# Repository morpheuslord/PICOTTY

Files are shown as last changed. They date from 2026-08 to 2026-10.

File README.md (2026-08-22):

<p align="center">
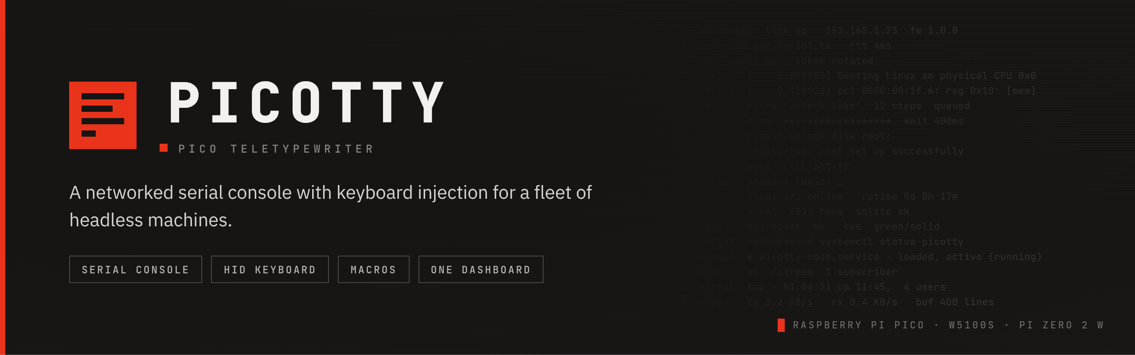
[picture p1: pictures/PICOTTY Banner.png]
PICOTTY — Pico TeleTYpewriter: a networked serial console with keyboard injection for a fleet of headless machines
  
</p>

# PICOTTY

*Pico TeleTYpewriter — an archaic telex reborn as a networked serial console.*

PICOTTY is a star-topology **serial console** for a fleet of Raspberry Pi Pico
nodes. Each node plugs into the USB port of a headless machine and becomes a
**networked serial console with keyboard injection** — it reads the target's
serial console back over the network and types keystrokes into the machine. One
hub (a Raspberry Pi Zero 2 W) coordinates the whole swarm and gives you a single
browser dashboard to watch every node and drive it, over your management network.

> **This is a serial console, not a KVM.** There is no video capture. Each node is
> a serial console with a USB keyboard attached: it reads what the target emits on
> its serial line and types back into it. Reading output therefore depends on the
> target actually having a serial console configured.

## Why this exists

I built PICOTTY for my own homelab, which runs on a rack of **mini PCs**. Unlike
a server, those boxes expose **no accessible serial port** — no BMC/IPMI, no
DB9/RJ45 console, often not even a usable header — so there's no out-of-band way
to see a stuck boot, poke a frozen box, catch a kernel panic, or drive the BIOS
without walking over and plugging in a keyboard and monitor. PICOTTY gives every
one of those headless machines exactly that, **over the network**: a tiny Pico on
its USB port acts as a USB keyboard (so you can type at BIOS, GRUB, and the OS)
and reads back a serial console, all surfaced in one browser dashboard. It's the
lights-out management a fleet of consumer mini PCs never shipped with.

---

## The dashboard

One page drives the whole swarm. **Click any screenshot to open it at full resolution.**

<p align="center">
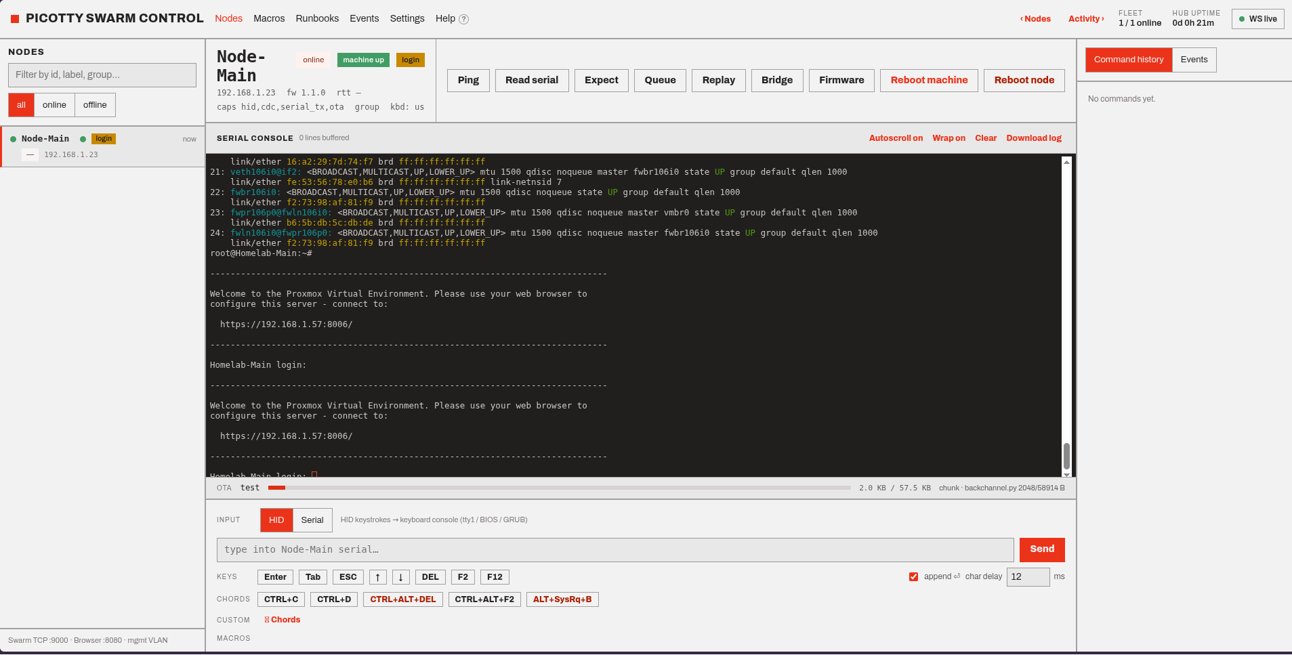
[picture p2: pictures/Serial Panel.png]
Serial console
  <br>
  <sub><b>Serial console</b> — live target output (ANSI-cleaned) with the HID ⇄ Serial input toggle</sub>
</p>

<table>
  <tr>
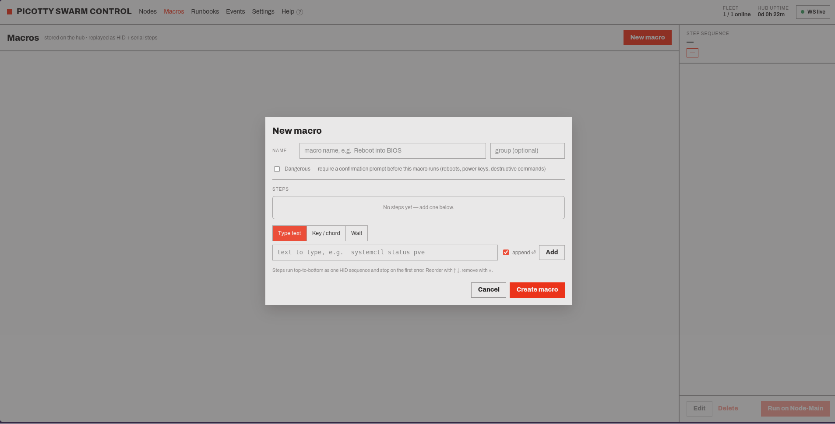
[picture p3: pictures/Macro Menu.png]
Macro editor
    <td width="50%" align="center"><br><sub><b>Macro editor</b> — reusable HID sequences from type / keys / wait steps</sub></td>
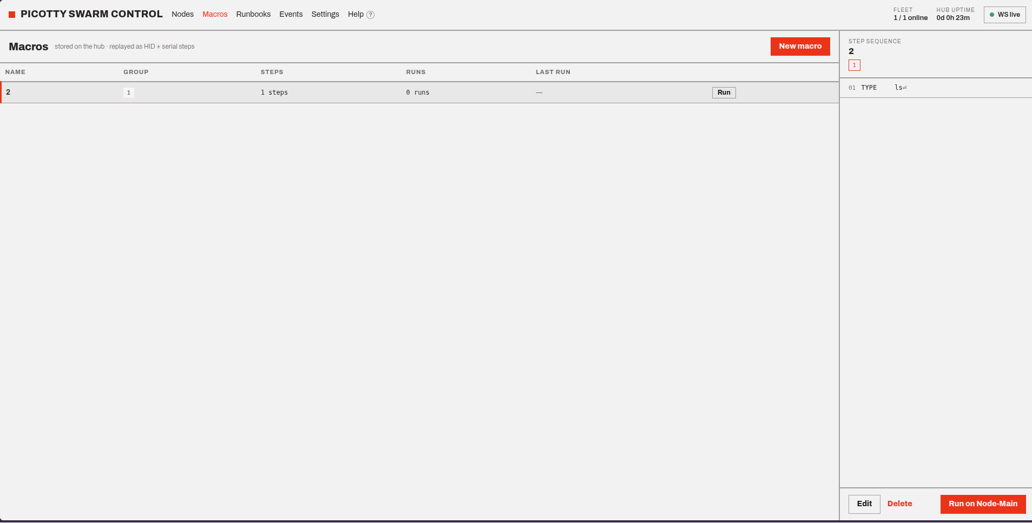
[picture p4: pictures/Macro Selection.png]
Macro library
    <td width="50%" align="center"><br><sub><b>Macro library</b> — saved sequences, replayable on any node</sub></td>
  </tr>
  <tr>
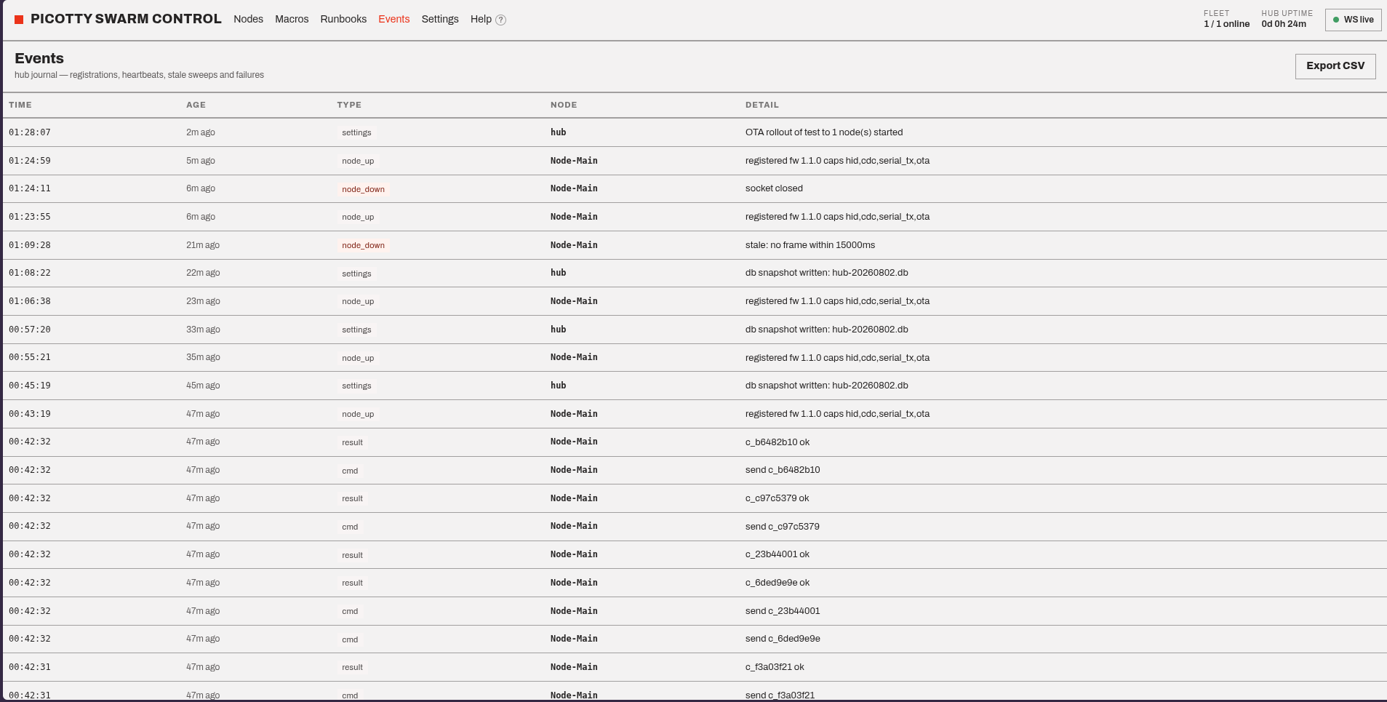
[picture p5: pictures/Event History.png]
Event history
    <td width="50%" align="center"><br><sub><b>Event history</b> — every connect, command, and fault, timestamped</sub></td>
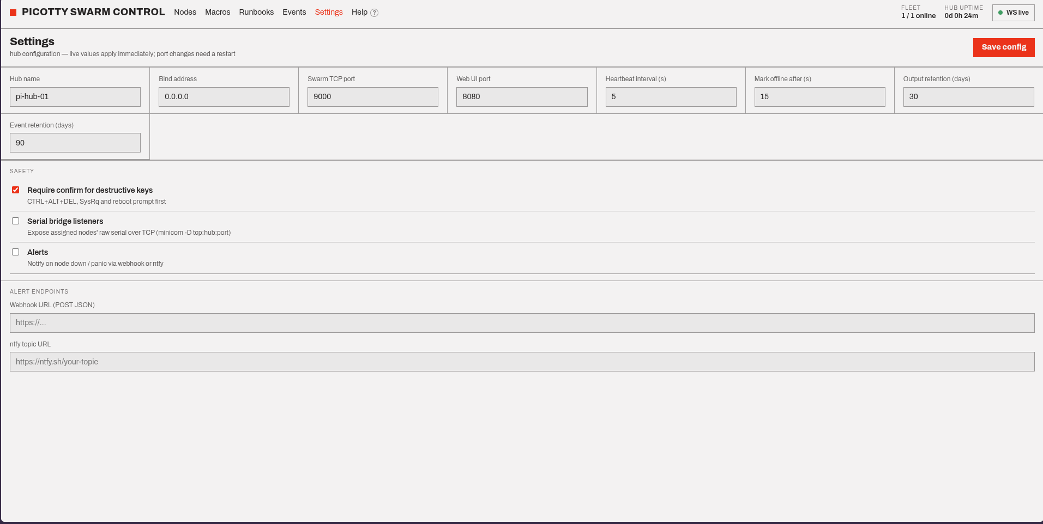
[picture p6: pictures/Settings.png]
Settings
    <td width="50%" align="center"><br><sub><b>Settings</b> — heartbeat, retention, token rotation, confirm-dangerous</sub></td>
  </tr>
  <tr>
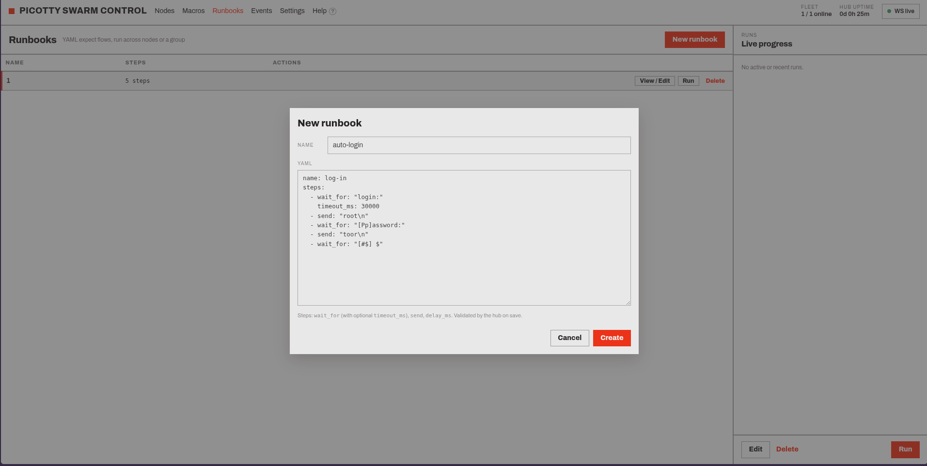
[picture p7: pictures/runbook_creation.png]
Runbook creation
    <td width="50%" align="center"><br><sub><b>Runbook creation</b> — author a YAML expect flow, validated on save</sub></td>
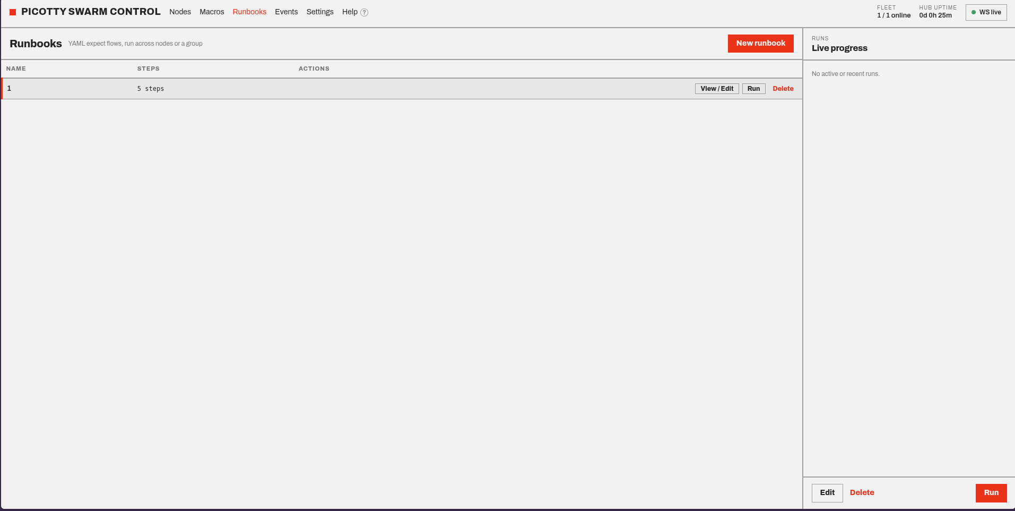
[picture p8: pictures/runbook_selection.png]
Runbook library
    <td width="50%" align="center"><br><sub><b>Runbook library</b> — pick a saved runbook, run it across a group</sub></td>
  </tr>
  <tr>
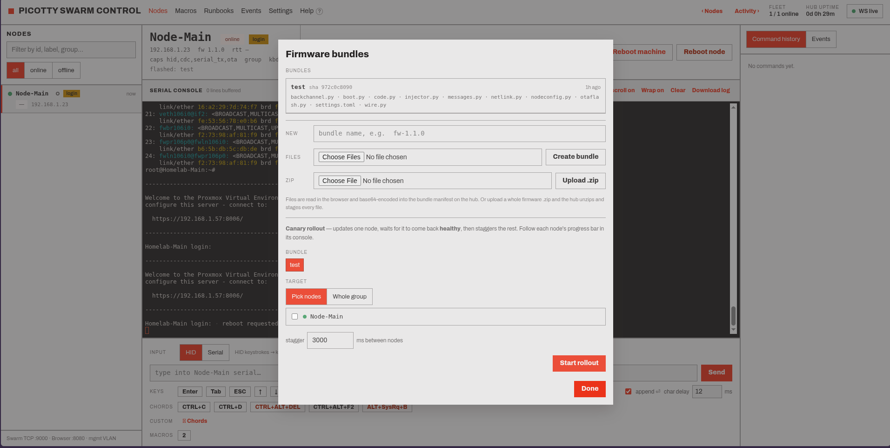
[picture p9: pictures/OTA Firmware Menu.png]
OTA firmware menu
    <td width="50%" align="center"><br><sub><b>OTA firmware menu</b> — push a bundle to a node, live byte-progress and health check</sub></td>
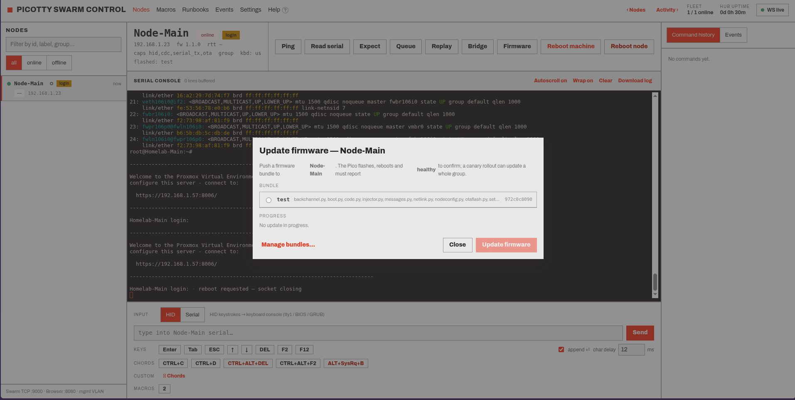
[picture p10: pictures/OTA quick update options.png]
OTA quick update options
    <td width="50%" align="center"><br><sub><b>OTA quick update options</b> — manage bundles, .zip upload, canary rollout</sub></td>
  </tr>
</table>

<p align="center">
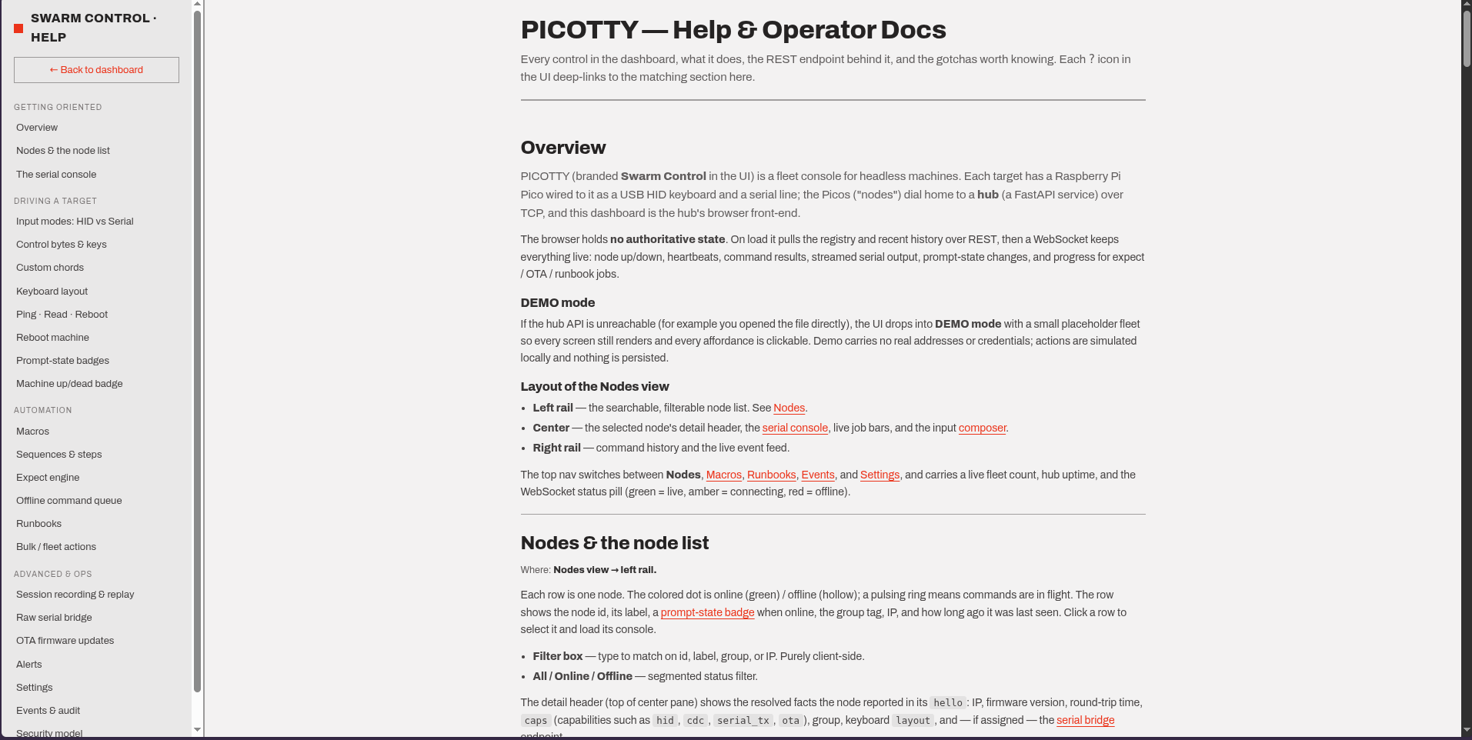
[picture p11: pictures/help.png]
In-app help
  <br>
  <sub><b>In-app help</b> — every control, its REST endpoint, and the gotchas, built into the hub</sub>
</p>

---

## What you get

- **Networked serial consoles** — read each target's serial console live and type
  into its serial login (`send`), all from the browser over the network.
- **Keyboard injection** — each node is also a USB HID keyboard, so it drives the
  target everywhere a keyboard works: BIOS, GRUB, initramfs, the OS.
- **One dashboard** — live status, per-node console, keys/chords, macros, bulk
  commands, and an event log, over HTTP + WebSocket.
- **Durable history** — every node, command, result, and output chunk is recorded
  in SQLite on the hub.
- **Headless-friendly** — LED status codes, opt-in `/error.txt`, and a REPL debug
  path make a node with no monitor diagnosable.

**What's new:** interactive serial write with a real terminal renderer, per-node
prompt-state badges, a **machine up/dead liveness badge** (is the *target* alive,
not just the node), a wait-for-output **expect engine** and YAML **runbooks**
(author, view, and edit in the browser), a **Reboot-machine menu** with three
methods (serial `reboot`, Ctrl+Alt+Del, Magic SysRq `Alt+SysRq+B`), **custom
quick chords** you save and replay, an offline command queue, **asciicast**
session replay, a raw **serial bridge** for `minicom`/PuTTY, webhook/**ntfy**
alerting, per-node keyboard layouts, and **OTA firmware updates** (chunked,
checksummed, **.zip-upload** bundles, canary rollout with watchdog-revert). Nodes now support **dual-hub failover** — a
primary + backup hub per node, with runtime steering (move / set-home / pin) and a
shared node token. The hub
now ships as the **`picotty`** uv package (`uv tool install picotty`, with a
`picotty.client` SDK), and an optional **Telegram bot sidecar** puts stats, alerts,
and a break-glass terminal on your phone — now with **fleet commands** (`/bulk`,
`/runmacro`, `/runbook`), read-only lookups (`/events`, `/log`, `/search`, `/ping`),
and dual-hub steering (`/hubs`, `/hub`). Depth in
**[docs/automation.md](docs/automation.md)**, **[docs/operations.md](docs/operations.md)**,
**[docs/ota.md](docs/ota.md)**, **[docs/packaging.md](docs/packaging.md)**,
**[docs/dual-hub.md](docs/dual-hub.md)**, and
**[docs/telegram.md](docs/telegram.md)**.

---

## Hardware

Per target machine: a **Raspberry Pi Pico** (or **Pico 2**) + a **WIZnet W5100S
Ethernet HAT** + a data-capable USB cable + an Ethernet drop. One shared **Pi Zero
2 W** runs the hub. (The all-in-one **W5100S-EVB-Pico** replaces the Pico + HAT.)

<table>
  <tr>
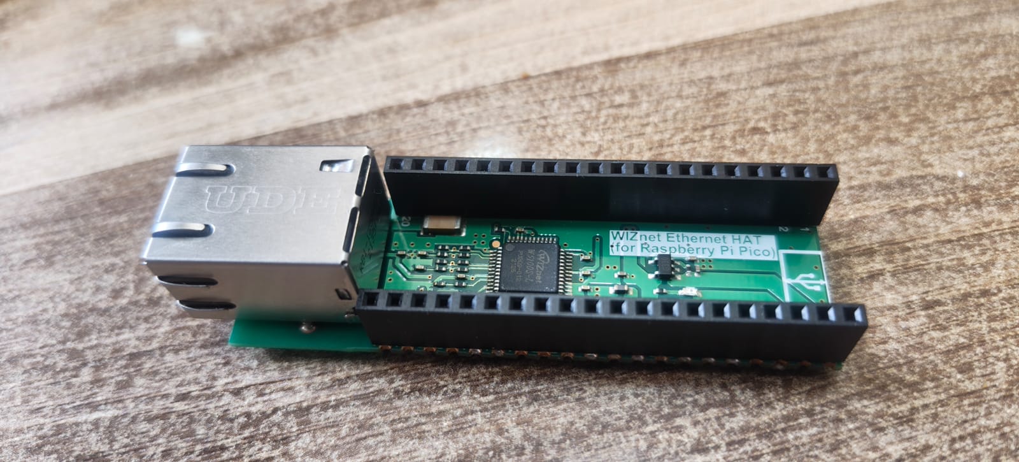
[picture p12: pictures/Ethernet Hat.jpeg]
WIZnet W5100S Ethernet HAT
    <td width="50%" align="center"><br><sub><b>WIZnet W5100S Ethernet HAT</b> — wired Ethernet over SPI</sub></td>
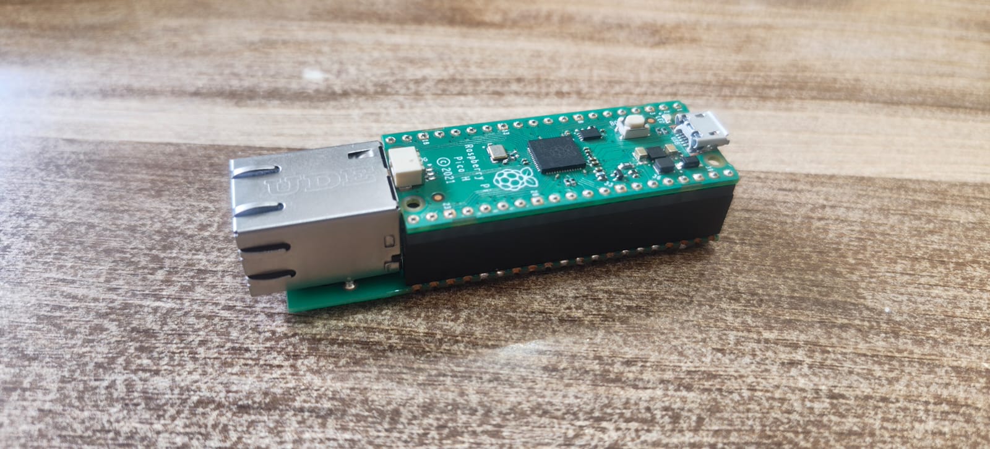
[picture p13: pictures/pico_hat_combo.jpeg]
Pico stacked with the Ethernet HAT
    <td width="50%" align="center"><br><sub><b>Pico + HAT</b> — SPI Ethernet, USB left free for the target</sub></td>
  </tr>
</table>

<p align="center">
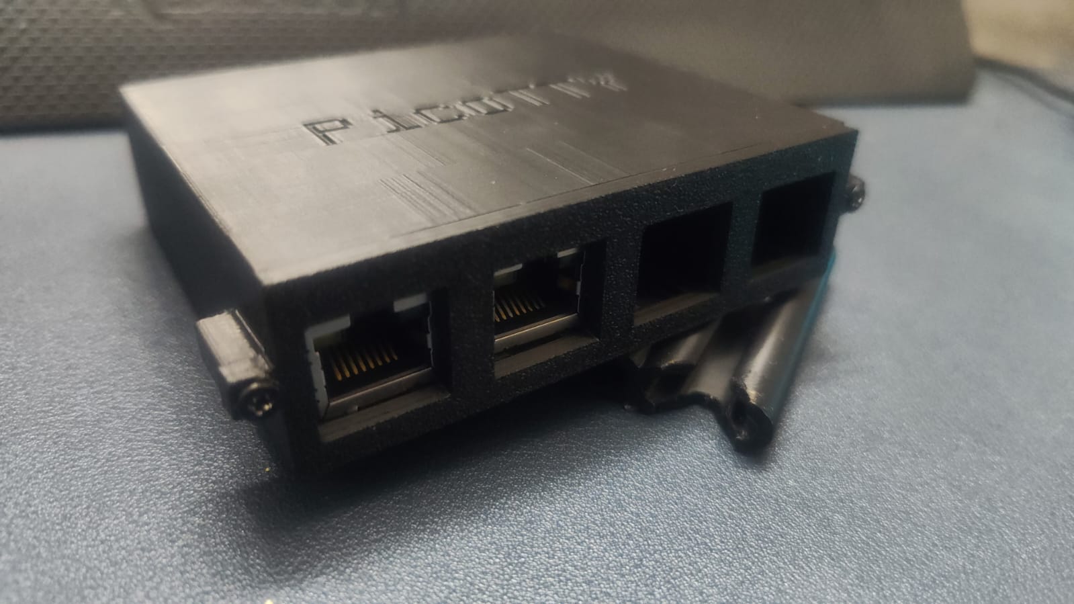
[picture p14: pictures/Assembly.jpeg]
A node assembled in its 3D-printed enclosure
  <br>
  <sub><b>A node assembled in its 3D-printed enclosure</b></sub>
</p>

### 3D-printable enclosure

<p align="center">
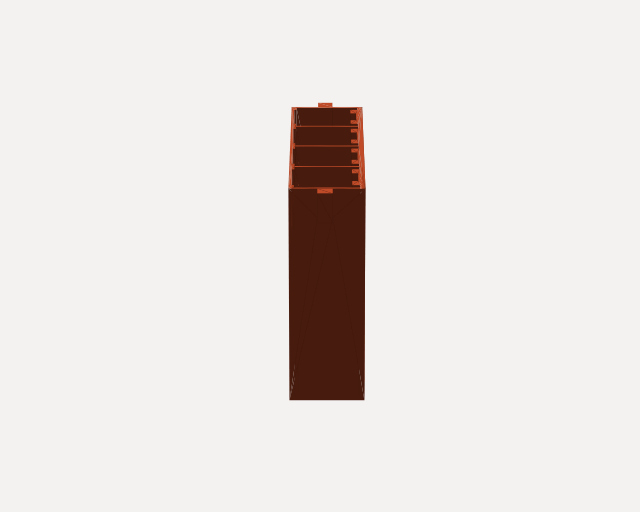
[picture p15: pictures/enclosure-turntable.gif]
PICOTTY node enclosure — rotating STL preview
  <br>
  <sub>▶ <b><a href="https://3dviewer.net/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">Open the interactive 3D viewer</a></b> &nbsp;·&nbsp; or click <a href="Enclosure%20Cad/Enclosure%20Body.stl">the STL in the repo</a> for GitHub's built-in 3D viewer</sub>
</p>

Files in [`Enclosure Cad/`](Enclosure%20Cad):
[**STL**](Enclosure%20Cad/Enclosure%20Body.stl) (slice & print) ·
[STEP](Enclosure%20Cad/PICOTTY-ENCLOSURE.step) (neutral CAD) ·
[Fusion 360 (.f3d)](Enclosure%20Cad/PICOTTY-ENCLOSURE.f3d) (editable source)

→ Full bill of materials and topology: **[docs/hardware.md](docs/hardware.md)**

---

## Quick start

The hub ships as the **`picotty`** package (uv). Install it as a tool, or run
from source:

```bash
# 1. Hub — on the Pi Zero 2 W
uv tool install picotty        # picotty-hub + picotty-sim on PATH  (or: from source ↓)
picotty-hub                    # → dashboard at http://<hub-ip>:8080
#    from a repo checkout instead:
bash hub/scripts/install.sh    # uv sync --extra hub  (+ fetches the terminal libs)
bash hub/scripts/install-service.sh          # or: bash hub/scripts/run.sh  (foreground)

# 2. Node — on your flashing machine (<id> = a node id under private/nodes/)
bash firmware/scripts/install-deps.sh
bash firmware/scripts/build.sh --node <id> --drive /run/media/$USER/CIRCUITPY
#    …or stage an artifact to drag on later:
bash firmware/scripts/build.sh --node <id> --stage        # -> firmware/build/<id>/ + .zip

# 3. Target — on each managed machine (emits its serial console to the node)
sudo bash target-setup/proxmox-serial.sh
```

**Test without hardware:**

```bash
uv run picotty-sim --id <id> --token <TOKEN>              # a fake node against the hub
python3 firmware/tools/testhub.py --selftest              # a mock hub against a real node
python3 firmware/tools/testhub.py --framecheck            # offline firmware framing checks
cd hub && uv run python tests/test_db.py                  # offline hub db checks
```

Your node ids, hub address, and token live only under `private/` (gitignored) —
nothing machine-specific is committed.

---

## Documentation

The full technical reference lives in **[docs/](docs/)**:

| Doc | What's inside |
|---|---|
| [architecture.md](docs/architecture.md) | Component roles, the single-loop hub, the one-cable USB design, the wire protocol, message journeys, data model, repo layout |
| [hardware.md](docs/hardware.md) | Physical topology, bill of materials, component tree, sizing |
| [deployment.md](docs/deployment.md) | The three build phases, the end-to-end workflow, the full script reference |
| [firmware.md](docs/firmware.md) | Firmware lifecycle, LED codes, keyboard layout, OTA capability, hardening, CircuitPython version rules |
| [dual-hub.md](docs/dual-hub.md) | Dual-hub failover: primary + backup hub per node, runtime steering, the independent-peers model, and the shared node token |
| [operations.md](docs/operations.md) | Observability, prompt-state badges, HID vs Serial input, console renderer, session recording, serial bridge, alerting |
| [automation.md](docs/automation.md) | Prompt-state detection, the expect (wait-for-output) engine, offline command queue, YAML runbooks |
| [ota.md](docs/ota.md) | Over-the-wire firmware updates: the safety model and rollout posture |
| [packaging.md](docs/packaging.md) | The `picotty` uv package: import surfaces, extras, entry points, the client SDK, and building + publishing to PyPI |
| [telegram.md](docs/telegram.md) | The Telegram bot sidecar: stats / alerts / gated terminal over chat, and the dashboard credential setup |
| [considerations.md](docs/considerations.md) | Security boundary, target requirements, power, roadmap |

---

## Contributing & security

- [CONTRIBUTING.md](CONTRIBUTING.md) — dev setup, coding style, the "keep secrets out of the repo" rule
- [SECURITY.md](SECURITY.md) — reporting a vulnerability, operator hardening
- [CODE_OF_CONDUCT.md](CODE_OF_CONDUCT.md) — community expectations
- Licensed under the terms in [LICENSE](LICENSE).

---

*PICOTTY — a teletype for machines that forgot they had a keyboard.*

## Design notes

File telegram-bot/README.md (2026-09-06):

[← Project README](../README.md)

# PICOTTY Telegram sidecar

Reach the hub from your phone without opening the management VLAN to inbound
traffic. This is a **separate process** (its own venv, its own systemd unit) that
talks to the hub **only** through the existing REST API and `/ws` event stream on
`:8080`. It holds no hub internals; stopping it removes the entire external
surface with zero hub impact — the kill switch.

Why Telegram: the Bot API's **long polling is outbound-only**. The sidecar opens
one HTTPS connection *out* to `api.telegram.org` and holds it — no inbound port,
no webhook, no public endpoint. The only firewall change is an egress allow to
`api.telegram.org` from the hub host.

> **Not end-to-end encrypted.** Bot traffic is TLS to Telegram's servers, which
> can read it. Fine for uptime numbers; for the shell tier this is the reason the
> terminal is gated behind break-glass TOTP arming and the getty keeps autologin
> off.

## Capability tiers

| Tier | Commands | Gate |
|---|---|---|
| **1 · Stats** | `/status` `/nodes` `/uptime [node]` `/telemetry [node]` | allowlist |
| **1b · Read-only** | `/events [n]` (recent audit), `/log <node> [lines]` (recent console), `/search <text>` (search console history), `/ping <node>` (active RTT), `/hubs`, `/source [primary\|backup]`, `/macros`, `/runbooks` | allowlist |
| **2 · Alerts** | node offline/online, watchdog recovery, command failed, hub restart; `/mute` `/unmute` | allowlist |
| **3 · Terminal** | `/shell [node]`, plain text → getty, `/ctrlc` `/ctrld` `/ctrlz` `/esc` `/tab` `/enter` `/up` `/down` `/left` `/right`, `/reboot`, `/sysrq` | allowlist **+ armed (TOTP)** |
| **3b · Fleet** | `/bulk <text>` (type into every online node), `/runmacro <id> [node …]`, `/runbook <id> <node …\|all\|group:NAME>`, `/hub <node> <switch\|prefer\|pin\|unpin> [target]` | allowlist **+ armed (TOTP)** |

Tier 3 is built on the hub `send` command and is **gated on the node advertising
`serial_tx`** — a node whose firmware can't write serial won't open a session. The
read-only and fleet commands are thin wrappers over existing hub REST; the fleet
commands touch many boards at once, so they sit behind the same break-glass arming
as the shell. `/hubs`, `/source`, and `/hub` cover [dual-hub
failover](../docs/dual-hub.md) — which hub each board is on, which hub the bot
acts on, and steering a board to the other hub.

## Security model

- **Chat-ID allowlist**, checked on *every* update, not just at session start.
  Unknown chats get **silence** (logged to the audit file), never a reply.
- **Break-glass arming** for tier 3. The allowlist alone isn't enough — a
  compromised phone or Telegram account would otherwise hold shell access. `/arm
  <TOTP>` arms the shell for a bounded window (`SHELL_ARM_WINDOW_S`, default 1 h),
  then it auto-disarms. The shell (`/shell`, `/reboot`, `/sysrq`) and the fleet
  actions (`/bulk`, `/runmacro`, `/runbook`, `/hub`) all require armed. Stats,
  read-only lookups, and alerts are always on. An immediate TOTP replay is
  rejected.
- **Idle auto-close** (`SHELL_IDLE_TIMEOUT_S`, default 5 min) ends a forgotten
  session; a mid-session disarm closes it too.
- **Password entry is safe for free**: the getty doesn't echo, so nothing
  sensitive is relayed. Your *typed commands* are visible in Telegram chat
  history, though — deleting them after is on you.
- **Audit log**: `data/telegram-audit.jsonl` (chmod 600, append-only) records
  chat id, command, node, and outcome — including session open/close and every
  line typed into a target. Kept sidecar-local so the bot needs no hub write
  endpoint (Option B isolation); the token and TOTP secret are never logged.
- **Sidecar kill switch**: `systemctl stop swarm-telegram`.
- **Egress**: allow the hub host outbound 443 to `api.telegram.org` only.

## Rate limits

The bot uses python-telegram-bot's `AIORateLimiter`, which honors Telegram's
`retry_after` on 429 automatically. Relayed terminal output is **coalesced** in a
~1.6 s window and flushed as monospace blocks split at Telegram's 4096-char
limit; under sustained output (boot logs at 115200 baud ≈ 11.5 KB/s) the pump
**drops to summarized delivery** — it keeps the tail and notes how many bytes it
skipped — so a `dmesg -w` can't blow past the per-chat limit.

## Setup

The sidecar and the hub share **one** credentials file —
`~/.config/picotty/telegram.env` (chmod 600) — which the dashboard writes and the
sidecar reads and **hot-reloads**. Nothing to align by hand.

**From the dashboard (recommended).** Open **Settings → the "Telegram sidecar"
card**: paste the bot token (from [@BotFather](https://t.me/BotFather)), your
numeric chat id (from [@userinfobot](https://t.me/userinfobot)), and — for the
shell tier — click **Generate** for a TOTP secret and add it to an authenticator
app. **Save** (the hub validates the token via `getMe`), then **Install / start
sidecar** (the hub runs `uv sync` and enables the service, showing the output).

**From the shell.**

```bash
bash telegram-bot/scripts/install.sh          # uv venv + the shared ~/.config/picotty/telegram.env
# fill that file in — by hand, or from the dashboard card above
bash telegram-bot/scripts/run.sh              # foreground (dev)
bash telegram-bot/scripts/install-service.sh  # systemd unit (starts on boot)
```

Then in Telegram, send **`/menu`** for the button UI — Status, Nodes (→ per-node
Ping/Read/Telemetry/Log/Mute and, once armed, Shell/Reboot/SysRq/Move-hub), Fleet
(Macros/Runbooks), Source hub, and Arm — all by tapping, no typing. Tap **🔒 Arm**
then send your TOTP code to unlock the shell tier. The typed commands below all
still work.

Or type directly: `/status`, `/nodes`, `/uptime`, `/telemetry`, and — after `/arm <code>` —
`/shell <node>`. The full walkthrough (with the security model and the credential
flow) is in **[../docs/telegram.md](../docs/telegram.md)**.

> After a `git pull` that changes hub code, `sudo systemctl restart swarm-hub` so
> new REST routes take effect (otherwise the install endpoint returns 405).

## Dual-hub

Set **`HUB_BASE_URL_BACKUP`** in `telegram.env` and the bot fails over between
hubs — every REST call and the live event stream prefer the primary and switch to
the backup when the primary is down. **`/source [primary|backup]`** picks which
hub the bot acts on (it still auto-fails-over afterward).

Telegram allows only **one active receiver per bot token**, so for HA run the
**same** bot on both hosts but keep only **one enabled** (systemctl) — the other
is a hot spare you promote by hand if the first host dies. Full model and setup:
**[../docs/dual-hub.md](../docs/dual-hub.md)**.

## Testing without Telegram

```bash
cd telegram-bot
uv run python tests/test_unit.py     # config, TOTP arm/replay, chunking, ANSI, roster
uv run python tests/smoke.py         # builds the whole app (wiring), no network
```

The unit tests cover config parsing, TOTP arming/replay, output chunking and the
summarize fallback, ANSI stripping, and the node roster rendering — none of which
need a live bot or hub.

## What runs where

```mermaid
graph LR
  TG["Telegram<br/>api.telegram.org"]
  subgraph MGMT["Management VLAN (no inbound)"]
    SIDE["telegram-bot<br/>sidecar process"]
    HUB["PICOTTY hub :8080<br/>REST + /ws"]
    NODES["nodes → targets"]
  end
  SIDE -->|"outbound HTTPS long-poll"| TG
  SIDE -->|"REST + WebSocket"| HUB
  HUB --> NODES
```

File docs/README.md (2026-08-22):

# PICOTTY documentation

Deep technical reference. For the gist and copy-paste commands, see the
[project README](../README.md).

| Doc | What's inside |
|---|---|
| [architecture.md](architecture.md) | Component roles, the single-loop hub, the one-cable USB design, the wire protocol, message journeys, data model, repository layout |
| [hardware.md](hardware.md) | Physical topology, bill of materials (Pico / Pico 2 + WIZnet HAT), component tree, sizing |
| [deployment.md](deployment.md) | The three build phases, the end-to-end workflow, the full script reference + common invocations |
| [firmware.md](firmware.md) | Node firmware lifecycle, LED status codes, keyboard layout, OTA capability, hardening, CircuitPython version rules |
| [dual-hub.md](dual-hub.md) | Dual-hub failover: a primary + backup hub per node, runtime steering (move / set-home / pin), cross-hub takeover from either hub (`HUB_PEERS`), the independent-peers model, and the shared node token |
| [operations.md](operations.md) | Observability, prompt-state badges, HID vs Serial input, console renderer, session recording, the serial bridge, alerting |
| [automation.md](automation.md) | Prompt-state detection, the expect (wait-for-output) engine, the offline command queue, YAML runbooks — with the REST API and worked examples |
| [ota.md](ota.md) | Over-the-wire firmware updates: the safety model (checksum, `.bak`, watchdog-revert, finalize-when-healthy), the push flow, canary rollout, and current integration status |
| [packaging.md](packaging.md) | The `picotty` uv package: import surfaces, extras, entry points, install (`uv tool install`), the client SDK, and building + publishing to PyPI |
| [telegram.md](telegram.md) | The Telegram bot sidecar: tiers (stats / alerts / gated terminal), the security model, and the dashboard credential setup flow |
| [considerations.md](considerations.md) | Security boundary, the serial-bridge boundary, target requirements, power, roadmap |

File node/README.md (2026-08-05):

[← Project README](../README.md)

# picotty_node — CircuitPython library (packaging target)

> **This is the DEFERRED Part-2 target, not the running firmware.** The
> authoritative node firmware **today** is [`firmware/circuitpython/`](../firmware/circuitpython/)
> — flat modules deployed by `build.sh`, fully working, OTA-capable. This folder
> holds the *packaging target* for that firmware (`picotty_node` as a `/lib`
> library) plus the drive-file [examples](examples/). The `.mpy` bundles, the
> per-CircuitPython-major CI, and circup registration described below are a
> **follow-up** — nothing here ships yet. Do not deploy from `node/`; deploy from
> `firmware/`.

## Goal

A node's `CIRCUITPY` drive should hold two files: a three-line `code.py` and a
`settings.toml`. Everything else — the wire layer, the netlink transport, the
HID injector, the serial backchannel, the command dispatch, OTA — moves into a
library installed once at `/lib/picotty_node/`.

```python
# code.py on the CIRCUITPY drive — the whole thing
import picotty_node
picotty_node.run()
```

`run()` reads `settings.toml`, builds the cooperative loop, and never returns.
Config stays out of the library on purpose: `settings.toml` is the one file
edited per node, `code.py` never changes, and a library update is "replace
`/lib/picotty_node/`" — touching neither. See [examples/](examples/) for both
template files.

## Package shape

The current flat firmware modules fold into the package one-to-one, with the
`code.py` dispatch loop becoming the package entry point:

| Current firmware module | `picotty_node` submodule |
|---|---|
| `code.py` (dispatch loop) | `picotty_node/__init__.py` (`run()`) + `picotty_node/loop.py` |
| `boot.py` | stays a drive file (runs before `/lib` is importable); OTA boot-recovery it calls moves to `picotty_node.otaflash` |
| `nodeconfig.py` | `picotty_node/config.py` |
| `messages.py` | `picotty_node/messages.py` |
| `wire.py` | `picotty_node/wire.py` |
| `netlink.py` | `picotty_node/netlink.py` |
| `injector.py` | `picotty_node/injector.py` |
| `backchannel.py` | `picotty_node/backchannel.py` |
| `otaflash.py` | `picotty_node/otaflash.py` |

`boot.py` is the one file that cannot move: it runs before `/lib` is on the
import path, so it stays on the drive (the example ships a thin one that imports
`picotty_node.otaflash` for boot-time OTA recovery). Third-party Adafruit
libraries (`adafruit_wiznet5k`, HID, `adafruit_hashlib`, layout libs) stay in
`/lib` alongside `picotty_node/` exactly as `build.sh` stages them today.

## Why `.mpy`

Shipping compiled `.mpy` instead of `.py` buys two things on an RP2040:

- **Import-time RAM.** No on-device compile step at import — faster boot and
  lower peak RAM during import, which is the tight resource at 264 KB.
- **Single-folder install.** `/lib/picotty_node/` is one directory of bytecode,
  no loose source files to manage on the drive.

The cost is a build step. **`.mpy` bytecode is tied to the CircuitPython MAJOR
version** — a 10.x board must load 10.x `.mpy`, and a 9.x `.mpy` fails to import
and crash-loops the node (the same rule that governs the Adafruit bundle, see
[firmware.md](../docs/firmware.md#circuitpython-version-rules)). So bundles are
compiled **per supported major** with the matching `mpy-cross`.

## Release layout (CI, per tag)

CI downloads the pinned `mpy-cross` binaries, compiles, zips, and attaches to the
GitHub release. Two artifacts per tag:

- **`picotty-node-<version>-cp<major>.zip`** — the `/lib/picotty_node/` folder as
  `.mpy` for that CircuitPython major, plus an example `code.py` and
  `settings.toml`. One zip per supported major.
- **`picotty-node-<version>-src.zip`** — plain `.py` source, for running from
  source or on a major without a prebuilt bundle.

Adafruit's cookiecutter library template and build actions do exactly this
per-major compile-and-attach and are worth cribbing from rather than writing
fresh.

## Install

### Manual unzip (the offline path — lead with this)

This must always work and needs no network on the node host.

1. Check the board's CircuitPython major (in `boot_out.txt` on the drive, or the
   REPL).
2. Download `picotty-node-<version>-cp<major>.zip` matching that major.
3. Unzip its `picotty_node/` folder into the board's `/lib`.
4. Copy the example `code.py` and `settings.toml` to the drive root; edit
   `settings.toml` for this node.

Getting the major wrong is the one failure mode — a mismatched `.mpy` crash-loops
the node — so match the zip's `cp<major>` to the board before copying.

### circup (follow-up)

Once `picotty_node` is registered in the CircuitPython **Community Bundle**,
`circup install picotty_node` fetches the bundle matching the board's real
version automatically. Registration means adopting the community bundle's repo
layout, CI conventions, and tagged releases — worth doing for discoverability,
but a follow-up, not a blocker. **In the meantime circup can install straight
from a GitHub URL**, so the tagged release is usable via circup before formal
registration lands.

## Memory checklist

The current firmware already fits, and `.mpy` only *improves* the import-time
footprint — but the restructure is the moment to bank a measurement. Add to the
node test checklist:

- **Measure free RAM after `run()` reaches steady state, per supported
  CircuitPython major**, and record it. Regressions across a major bump then show
  up as a number, not a mystery crash-loop.

**Escape hatch (mention, don't build):** if a future CircuitPython major gets
tight, `picotty_node` can be built as **frozen modules in flash**, which drops
its RAM cost further still. Note it as an option; there is no need to build it
now.

## Protocol compatibility

The node and hub version independently and will drift — a hub bugfix should not
force reflashing four nodes — so they negotiate rather than assume:

- The hub's `picotty.protocol` carries `PROTOCOL_VERSION = 1`. The node **echoes
  it in `hello`**. The hub logs a warning on mismatch and **refuses only on an
  incompatible major**; a compatible drift is allowed.
- **Capability flags** (`hid` / `cdc` / `serial_tx` / `ota`) still do
  feature-level negotiation on top of the version handshake — a node only gets
  offered what it advertises it can do.
- Each side's release notes state the protocol version it speaks and the minimum
  counterpart version.

### Constants-diff CI check

`picotty.protocol` is the single authoritative source; the node's wire code
mirrors it. A CI check **diffs the command names and the protocol version**
between the hub's protocol module and the node's wire code, failing the build if
they diverge — so the two sides cannot silently drift out of sync. Direct code
sharing is not practical (the node is written against CircuitPython's stdlib
subset), which is exactly why the diff exists.

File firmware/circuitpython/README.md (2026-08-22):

# Node firmware (CircuitPython)

Firmware for one swarm node: a Raspberry Pi Pico (RP2040) with a WIZnet W5100S
Ethernet HAT. The node plugs into a target machine's USB port and presents itself
as a **USB keyboard** plus a **USB serial data channel**, while reaching the hub
over Ethernet (SPI). It dials the hub, obeys its commands (type text, send key
chords, run sequences, read the target's serial output, and **write** into the
target's serial line), and reports back.

This implements the node half of the wire protocol: growing reconnect backoff, a
bounded receive buffer, a per-loop cap on forwarded output, non-blocking I/O
throughout, a hardware watchdog, and full coverage of every message type.

## Files

| File | Role |
|---|---|
| `boot.py` | Shapes the USB device (keyboard HID + CDC data channel). Runs once, before USB enumerates. |
| `code.py` | Main program: bring-up, connect/backoff supervisor, cooperative session loop, command dispatch. |
| `netlink.py` | Transport over the W5100S: brings the interface up once, manages one TCP socket with correct non-blocking semantics. |
| `injector.py` | The keystroke path: type literal text and map named chords to HID keycodes. |
| `backchannel.py` | Reads the target's serial output from the CDC data channel, and writes into it for the `send` command (chunked, non-blocking, drained across loop passes). |
| `wire.py` | Length-prefixed JSON framing and a bounded frame reader. |
| `messages.py` | Builders for every node→hub message. |
| `nodeconfig.py` | Loads and validates `settings.toml`. |
| `hubselect.py` | Dual-hub failover: picks primary/backup, rotates on failure, applies runtime steering directives. Pure logic, host-testable. |
| `otaflash.py` | Over-the-wire firmware update machinery (checksummed push, `.bak` + watchdog-revert). Wired into `code.py`/`boot.py` behind the `ota` capability — see the OTA note below. |
| `settings.toml.example` | Copy to `settings.toml` and edit per node. |

## Hardware and wiring

W5100S HAT on the Pico's SPI0 (confirm against your HAT's silkscreen — revisions
vary):

| Signal | Pico GPIO |
|---|---|
| MISO | GP16 |
| CS | GP17 |
| SCK  | GP18 |
| MOSI | GP19 |
| RST  | GP20 |
| INT  | GP21 (unused by the polling driver) |

The HAT is powered from the Pico's 3V3; the Pico is powered from the target's USB.
When the target is off, the node is off. If you need the node to survive a target
power cycle, give it a second power feed and avoid backfeeding the target (a
hardware choice, not a firmware one).

To change the pins, edit the constants at the top of `netlink.py`.

## Flashing

1. **Install CircuitPython** on the Pico. Flash the generic *Raspberry Pi Pico*
   build (8.x or 9.x), **not** the W5100S-EVB build — your Ethernet is a separate
   HAT, not integrated. Hold BOOTSEL, drag the `.uf2` onto the `RPI-RP2` drive.
   The board reboots as a `CIRCUITPY` drive.

2. **Install the libraries** into `CIRCUITPY/lib/`. The easiest way is
   [`circup`](https://github.com/adafruit/circup), which pulls dependencies too:

   ```bash
   pip install circup
   circup install adafruit_wiznet5k adafruit_hid
   ```

   That brings in `adafruit_wiznet5k`, `adafruit_hid`, and their dependencies
   (`adafruit_bus_device`, `adafruit_ticks`, `adafruit_connection_manager`).
   Requires **adafruit_wiznet5k ≥ 7.0.0** (the SocketPool API this firmware uses).
   Alternatively, copy those folders from the matching
   [CircuitPython library bundle](https://circuitpython.org/libraries) by hand.

3. **Copy the firmware.** Copy every file in this directory to the root of the
   `CIRCUITPY` drive: `boot.py`, `code.py`, `netlink.py`, `injector.py`,
   `backchannel.py`, `wire.py`, `messages.py`, `nodeconfig.py`, `hubselect.py`.

4. **Configure the node.** Copy `settings.toml.example` to `settings.toml` on the
   drive and edit at least `NODE_ID`, `NODE_TOKEN`, and `HUB_IP`. Because `boot.py`
   changes the USB descriptors, **fully power-cycle the board once** after the
   first copy (a plain reset re-runs `code.py` but not `boot.py`).

5. **Watch it come up.** Open the node's REPL console serial port; you should see
   `node <id> ip <addr> cap ['hid', 'cdc', 'serial_tx']` then `connected; hello sent`.

### Build scripts (steps 2–4 automated)

`../scripts/install-deps.sh` installs the tooling (circup, mpy-cross). Then
`../scripts/build.sh` either deploys to a mounted board or builds a drop-in
artifact:

```bash
../scripts/build.sh --node node-01              # copy onto a mounted CIRCUITPY
../scripts/build.sh --node node-01 --stage      # -> ../build/node-01/ + a .zip
```

A CircuitPython app is a *folder* of files (`boot.py`, `code.py`, the modules,
`lib/`, `settings.toml`), not a single compiled binary — the only one-file
drop-in is the CircuitPython `.uf2` in step 1. `--stage` assembles that folder
(and a zip) offline, with the Adafruit libraries fetched into `lib/`, so you can
drag its contents onto any board later without this machine present. Add `--mpy`
to ship the modules precompiled.

## `settings.toml`

`NODE_ID`, `NODE_TOKEN`, and `HUB_IP` are required; the node refuses to run without
them and prints a clear error. Everything else has a sensible default — see the
comments in `settings.toml.example`. Notes:

- Use the hub's **IP**, not a hostname, so `connect()` stays fast.
- Leave `STATIC_IP` unset to use DHCP. A static node needs no lease upkeep.
- Each node auto-derives a **unique MAC** from its `NODE_ID` (nodes must not share
  a MAC on the VLAN). Override with `NODE_MAC` only if you manage MACs centrally.
- Numbers must have no leading zeros, underscores, or `0x`/`0b` prefixes
  (CircuitPython parses `settings.toml` numbers with C `strtol` rules).

## The real limitation: the target must talk

The node presents a serial port to the target, but it can only read what the
target actually *sends* to it. By default a running OS sends nothing there. To get
output back, configure the target to use that serial port as a console:

- **Linux:** enable a `getty` on the serial device (e.g. `systemctl enable
  --now serial-getty@ttyACMx.service`) and/or add `console=ttyACMx,115200` to the
  kernel command line.
- **BIOS/UEFI:** enable serial console redirection to the port.

Where a target can't be configured this way, the node is a **blind keyboard**: you
can type, you can't read. That's inherent to the hardware. The node still advertises
`cdc`; it just won't see output until the target emits some. Decide per target
which machines are worth wiring a console on.

Also note the node presents **two** CDC ports (the node's own REPL console and the
data channel). Point the target's serial console at the **data** port. For a
production node you can set `console=False` in `boot.py` so the target sees only the
one clean data port.

## Writing to the serial line — the `send` command

Reading the console is only half of an interactive session. The `send` command
lets the hub **write** bytes into the target's serial line, so with a getty
running there the console becomes a real serial login (type a command, the getty
echoes it back, you read the reply — all over the one CDC data channel).

- Wire shape: `{type: "send", cmd_id, data}` for UTF-8 text, or
  `{type: "send", cmd_id, raw}` where `raw` is a hex string (e.g. `"03"` for
  Ctrl+C, `"0d"` for CR, `"7f"` for Backspace). Exactly one of `data`/`raw`.
  Binary bytes travel as hex so the wire stays UTF-8 JSON.
- **Cooperative, non-blocking.** Writes are chunked and drained across loop
  passes with a per-loop byte budget (`SERIAL_TX_BUDGET`, default 1024),
  interleaved with the console read path so neither starves the other. A large
  paste can never block the loop or trip the ~8 s watchdog.
- **Bounded buffer.** At most `SERIAL_TX_BOUND` bytes (default 4096) may be queued
  but unsent at once. A `send` that would overflow it is failed with a
  `serial tx backlog` detail rather than growing memory. The `ok` result is sent
  only once the whole payload has been handed to the CDC port.
- **Capability-gated.** A node advertises `serial_tx` in its `hello` capabilities
  when `usb_cdc.data` is present, so the hub and dashboard can tell new firmware
  from old. If the data channel is not enabled in `boot.py`, `send` fails cleanly
  with a clear detail — it never crashes the loop.

## Keyboard layout — `KEYBOARD_LAYOUT`

The node types as a USB HID keyboard, and the character-to-keycode mapping is
**layout-specific** and lives on the node. A US-configured node typing into a
target set to a German/UK/French layout mistypes symbols (the classic "the
password has a `/` and the node sent `-`" bug), so the layout is a per-node
setting the hub cannot fix for you.

- Set `KEYBOARD_LAYOUT` in `settings.toml` to the target's layout code. Default
  `us`; an unset value keeps a node typing exactly as before.
- `us` (or `en`/`en_us`) uses the built-in `KeyboardLayoutUS`. Any other code
  lazily imports the community library `keyboard_layout_win_<code>` (which needs
  its paired `keycode_win_<code>` in `lib/`). If that library isn't on the board,
  the node **logs a warning and falls back to US** — a bad layout degrades to a
  working keyboard, never a fatal error. Stage the layout your node needs.
- The node reports its resolved layout in `hello`; the hub shows it read-only in
  node detail so you can see what each node is set to.
- Only literal text (`type`, and `send` as text) is layout-sensitive; the
  named-chord path (`keys`) maps keycodes directly and is unaffected.

## Firmware updates over the wire

`otaflash.py` implements receiving a new firmware bundle over the network and
swapping it in, with SHA-256 verification, a `.bak` backup of every replaced file,
and an automatic revert if the new firmware crash-loops (a watchdog reset on the
next boot restores the `.bak` set). It is **fully wired into `code.py` and
`boot.py`**: `code.py` imports it, advertises the `ota` capability when
`OTA_ENABLED` is set and the filesystem is writable with `adafruit_hashlib`
present, and handles `ota_begin`/`ota_chunk`/`ota_commit` plus finalize-on-healthy;
`boot.py` runs its boot-time recovery. So an OTA-posture node can be flashed over
the wire from the dashboard. The safety model and push flow are documented in
[../../docs/ota.md](../../docs/ota.md).

## Reboot, reconnect, and liveness

- `reboot` from the hub calls `supervisor.reload()` — it restarts the firmware
  logic (fresh sockets and buffers) **without** re-enumerating USB, so the target
  keeps seeing the keyboard and serial port. It is not a target reboot.
- If the hub goes away, the node retries with growing backoff (1 s → 30 s) and
  resumes when it returns. It does nothing to the target in the meantime.
- If the main loop ever hangs, the hardware watchdog resets the node (this *does*
  re-enumerate USB). Disable it with `WATCHDOG_ENABLED = "false"` if you prefer.

## Testing a node in isolation (no hub)

Use `../tools/testhub.py` — a mock hub that a node connects to, so you can verify
the firmware before the real hub exists. Point the node at the machine running it
(set `HUB_IP`/`HUB_PORT` in the node's `settings.toml`) and either match the token
or let the tool accept any.

```bash
# on the test machine:
python3 ../tools/testhub.py                 # interactive
python3 ../tools/testhub.py --selftest      # automated checks, then exit
python3 ../tools/testhub.py --selftest --hid # also test keystroke injection
```

When the node connects you'll see its `hello`, live heartbeats, and any serial
output. Interactive commands: `run <cmd>`, `type <text>`, `key ENTER`,
`keys CTRL+C`, `read`, `send <text>`, `sendraw <hex>`, `ping`, `config <ms>`,
`seq`, `reboot`, `selftest`.

`--selftest` checks heartbeat, ping/pong RTT, `read`, `send` (serial write, on
nodes advertising `serial_tx`), `config`, and graceful handling of an unknown
command, printing PASS/FAIL. Add `--hid` to also test `type`/`keys`. Like `read`,
`send` has no HID side effect — its bytes go to the serial channel, not the
keyboard — so it is in the default safe subset.

> **Watch where the keystrokes go.** `type`/`keys`/`seq` inject over USB into
> **whatever machine the Pico is plugged into**. For a clean test, plug the Pico
> into a spare machine or VM with a text field focused, and run `testhub.py` on a
> different box. The ping/read/config/heartbeat checks have no HID side effects.

## Observing a deployed node (no console)

Once deployed — USB to the target, Ethernet to the switch — there's no port left
for a serial console. Two channels replace it.

### 1. The onboard LED — problems *before* the hub is reachable

The firmware drives the Pico's onboard LED so you can read the node at a glance:

| LED | Meaning |
|---|---|
| **solid on** | connected to the hub, healthy |
| **slow blink** (~1 Hz) | powered + networked, but not connected to the hub (retrying) |
| **medium blink** (~2.5 Hz) | Ethernet/link problem — can't bring the network up |
| **fast blink** (~5 Hz) | fatal config or HID error (bad `settings.toml`, HID not enabled) |

The W5100S HAT's own RJ45 link/activity LEDs separately confirm the physical
Ethernet link.

### 2. The hub — everything *after* it connects

The node reports home, so the hub is your log. In the dashboard's **Events** feed
(or `GET /api/events`, or `journalctl -u swarm-hub -f` on the hub) you see:

- **node_up / node_down** — registration, disconnect, and stale-sweep offline.
- **heartbeat + RTT** — live liveness; a node that dies stops pulsing.
- **error events** — the node sends an `error` frame for anything it wants on the
  record: an unknown command, a protocol desync, and **"recovered from watchdog
  reset"** after the loop hung and the watchdog restarted it.
- **command results** — every command's `ok`/`failed`, and on failure the detail
  (e.g. `unknown keycode: 'FOO'`, or an unmappable character). Filter the Events
  feed or command history by the node's id to see exactly what failed.

So: a misbehaving node shows up as failed results + error events against its id; a
dead one shows as node_down and silence. Repeated "recovered from watchdog reset"
means it's hanging — check power and the attached target.

### 3. Optional: `/error.txt` on the filesystem

For detail from a node that can't reach the hub — config errors, HID failures,
Ethernet-init failures, watchdog reset loops, crashes — the firmware can append
them to `/error.txt`, which you read by unplugging the Pico and plugging it into
any computer.

Turn it on with `LOG_TO_FILE = "true"` in `settings.toml`. `boot.py` then remounts
the filesystem writable to CircuitPython and `code.py` logs faults there (the file
self-truncates past ~32 KB).

**The trade-off:** a filesystem writable to CircuitPython is **read-only over USB**,
so `build.sh` / `deploy-zip.sh` drag-drop updates no longer work while it's on. You
can still *read* the drive (that's the point), just not write it. To update or turn
logging back off, **re-flash CircuitPython** (hold BOOTSEL, drag the `.uf2`) — that
resets the filesystem to host-writable — then redeploy with `LOG_TO_FILE = "false"`.

So: leave it off normally (the hub + LED cover the usual cases); switch it on only
when you're actively chasing a fault on a node you can't attach a console to.

### Before you deploy

Bench-test each node headless first: point its `HUB_IP` at your laptop and run
`python3 ../tools/testhub.py --selftest`. If that passes, the node is good before
it ever goes dark.

## Troubleshooting

- **Board boots to safe mode, or the keyboard/serial port never appears on the
  target.** You've likely exhausted USB endpoints (keyboard HID + two CDC channels
  + the mass-storage drive is a lot for the RP2040). Uncomment
  `storage.disable_usb_drive()` in `boot.py` to drop the drive and free endpoints —
  this also hides the `CIRCUITPY` drive from the target, which you usually want on a
  node plugged into a managed machine. Edit files via a dev machine or the REPL
  afterward.
- **`HID ERROR: no USB HID devices`.** `boot.py` didn't enable the keyboard, or you
  edited it and only did a soft reset. Power-cycle so `boot.py` re-runs.
- **`CONFIG ERROR: missing required setting`.** Add the named key to `settings.toml`
  and reset.
- **`ethernet init failed` on a loop.** Check the HAT seating, the SPI pins in
  `netlink.py`, and (for DHCP) that a lease is available. The node retries every
  3 s.
- **Connected, but no serial output in the console.** The target isn't emitting to
  the serial port — see "The real limitation" above. Typing still works.
- **Symbols type wrong.** The character-to-keycode mapping is layout-specific and
  defaults to US. If the target is set to a non-US layout, set `KEYBOARD_LAYOUT`
  (e.g. `"de"`, `"uk"`, `"fr"`) in `settings.toml` and make sure the matching
  `keyboard_layout_win_<code>` library is in `lib/`; otherwise the node logs a
  warning and falls back to US. The named-chord path (`keys`) is unaffected. See
  "Keyboard layout" below.

## A note on MicroPython

This firmware is CircuitPython specifically because of the composite USB device:
CircuitPython exposes an HID keyboard **and** a dedicated CDC *data* channel
(separate from the REPL) natively. On MicroPython the second data CDC requires a
custom composite descriptor and a firmware rebuild; its built-in CDC is the REPL,
so the target's serial port would be the node's Python prompt rather than a clean
data channel.

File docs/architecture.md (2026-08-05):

[← Docs index](README.md) · [← Project README](../README.md)

# Architecture

- [Component roles](#component-roles)
- [How a node uses one USB cable](#how-a-node-uses-one-usb-cable)
- [The hub, inside](#the-hub-inside)
- [The wire protocol](#the-wire-protocol)
- [Message journeys](#message-journeys)
- [Data model](#data-model)
- [Repository layout](#repository-layout)

## Component roles

Each node opens a persistent TCP connection **out** to the hub's fixed address and
announces itself with an ID baked into its firmware. The hub keeps a live registry
of connected nodes in memory and a durable record in SQLite. A single Python
process on the hub runs two listeners on one asyncio event loop: a raw TCP server
facing the swarm (`:9000`), and a FastAPI app facing your browser over HTTP and
WebSocket (`:8080`). The browser holds no authoritative state — it loads the
current picture over REST, then live-updates from the WebSocket as nodes connect,
heartbeat, and return output. Commands you issue in the browser travel down the
same socket the node opened, and results come back up it.

| Component | Runs on | Initiates | Listens | Renders | Persists |
|---|---|---|---|---|---|
| Node firmware | Pico + W5100S | Outbound TCP to hub | Hub commands; target serial | Nothing | `/error.txt` (opt-in) |
| TCP server | Pi Zero (hub) | Nothing | Node connections `:9000` | Nothing | Writes DB on ingest |
| Registry | Pi Zero, in memory | — | — | — | No (rebuilt on connect) |
| DB layer | Pi Zero, SQLite | — | — | — | Yes |
| REST API | Pi Zero (FastAPI) | Writes to node sockets | Browser HTTP `:8080` | Nothing | Reads/writes DB |
| WebSocket hub | Pi Zero (FastAPI) | Pushes to browsers | Browser upgrades | Nothing | Reads DB on backfill |
| Dashboard | Your browser | Calls REST | WebSocket events | Everything | Local prefs only |

## How a node uses one USB cable

A node built with the default `boot.py` presents the target **three** USB
functions plus draws power — all over the single cable — while reaching the hub
over SPI Ethernet:

```mermaid
graph LR
  subgraph PICO["Pico node (CircuitPython)"]
    CODE["code.py<br/>cooperative loop"]
    HID["usb_hid — keyboard"]
    DATA["usb_cdc.data — back-channel"]
    CONS["usb_cdc.console — REPL"]
    ETH["W5100S over SPI0"]
    LED["onboard LED — status"]
  end

  CODE --> HID
  CODE <--> DATA
  CODE --> CONS
  CODE --> LED
  CODE <-->|"length-prefixed JSON"| ETH

  HID -->|"keystrokes"| TARGET["Target machine"]
  TARGET -->|"serial console out"| DATA
  CONS <-->|"/dev/ttyACM — pico-debug"| TARGET
  ETH <-->|"TCP :9000"| HUB["Hub"]
```

- **`usb_hid` keyboard** injects keystrokes (works everywhere a USB keyboard
  works: BIOS, bootloader, OS).
- **`usb_cdc.data`** is the clean serial back-channel the node reads the target's
  console from **and** writes into (the `send` command / dashboard Serial mode).
- **`usb_cdc.console`** is the CircuitPython REPL — a live debug view of the node
  itself, reachable from the target host via `pico-debug.sh`.

## The hub, inside

One Python program, one asyncio event loop, two faces sharing one registry and one
database. Run it under a **single** uvicorn worker — a second worker would get its
own registry and its own node sockets, and the two would disagree about who is
online.

```mermaid
graph TB
  NODES["Swarm nodes"] -->|"frames"| TCP["TCP server :9000"]

  subgraph HUBPROC["Hub process — single asyncio loop"]
    TCP --> REG["Registry (in-memory)"]
    TCP --> DB["SQLite (aiosqlite, WAL)"]
    TCP --> BUS["Event bus"]
    REST["FastAPI REST :8080"] --> REG
    REST --> DB
    REST -->|"writer lookup → push cmd"| REG
    WS["WebSocket /ws"] --> BUS
    TASKS["tasks: sweep · output-flush · retention · stats · loop-lag"] --> REG
    TASKS --> DB
    TASKS --> BUS
    BUS --> WS
  end

  REST --> BROWSER["Dashboard"]
  WS --> BROWSER
```

- The **TCP server** writes what nodes report (registrations, results, output,
  connect/disconnect). The **REST layer** writes what operators change (labels,
  notes, groups, macros, settings, the initial command row). Both read.
- The **registry** is the only shared mutable state, and it is small and
  rebuildable — on a hub restart it starts empty and refills as nodes reconnect.
- Serial **output** is subscription-scoped over the WebSocket (only browsers that
  have a node's console open receive it); everything else broadcasts. Slow clients
  get drop-oldest backpressure, never a stalled loop.

## The wire protocol

The `:9000` link is deliberately small: each message is a **4-byte big-endian
length** followed by that many bytes of **UTF-8 JSON**. Length-prefixing (not
newline-delimiting) means a body containing newlines or control characters needs
no escaping.

```
+----------------+--------------------------------+
| length (4 B)   | JSON body (length bytes)       |
+----------------+--------------------------------+
```

```mermaid
graph LR
  subgraph N2H["node → hub"]
    direction TB
    hello["hello {id, token, fw, cap}"]
    heartbeat["heartbeat {id}"]
    result["result {cmd_id, status, payload?}"]
    output["output {text, ts}"]
    pong["pong {nonce}"]
    error["error {detail, cmd_id?}"]
    bye["bye {}"]
  end
  subgraph H2N["hub → node"]
    direction TB
    type["type {cmd_id, text, char_delay_ms?}"]
    keys["keys {cmd_id, chord[]}"]
    sequence["sequence {cmd_id, steps[], stop_on_error?}"]
    read["read {cmd_id}"]
    send["send {cmd_id, data | raw}"]
    ping["ping {nonce}"]
    reboot["reboot {}"]
    config["config {heartbeat_ms?}"]
  end
```

Every command carries a **`cmd_id`**; the node echoes it in the `result` and in any
`output` it can attribute to that command. This correlation is what lets the UI
match a result to the exact command that produced it, even when several commands
are in flight. The `token` in `hello` is a shared secret that stops a random device
on the VLAN from registering; it is a second line behind network isolation, not a
replacement for it.

## Message journeys

**A — A node comes online.**

```mermaid
sequenceDiagram
  participant N as Node
  participant T as TCP server
  participant D as Database
  participant B as Event bus
  participant U as Browser
  N->>T: hello {id, token, fw, cap}
  T->>T: validate token
  alt token ok
    T->>D: upsert node + node_up event
    T->>T: add to registry (online, store writer)
    T->>B: node_up
    B->>U: node_up (row appears / un-greys)
  else token bad
    T->>D: audit event
    T->>N: close socket
  end
```

**B — An operator issues a command.**

```mermaid
sequenceDiagram
  participant U as Browser
  participant R as REST
  participant G as Registry
  participant N as Node
  participant T as TCP server
  participant D as Database
  participant B as Event bus
  U->>R: POST /nodes/{id}/cmd
  R->>G: online? get writer
  R->>D: insert command (status=sent)
  R->>N: cmd frame (down node's own socket)
  R-->>U: {cmd_id, status:sent}
  N->>N: inject HID / read serial
  N->>T: result {cmd_id, status, payload?}
  T->>D: update command → done/failed, insert result
  T->>B: result (to subscribers)
  B->>U: result (resolves the inflight cmd_id)
```

**C — The target emits serial output.**

```mermaid
sequenceDiagram
  participant Tg as Target
  participant N as Node
  participant T as TCP server
  participant D as Database
  participant B as Event bus
  participant U as Browser (subscribed)
  Tg->>N: serial bytes to CDC data
  N->>T: output {text, ts}
  T->>D: append to output_log (batched)
  T->>B: output (subscribers only)
  B->>U: console appends the chunk
```

**D — Heartbeats and the liveness sweep.**

```mermaid
sequenceDiagram
  participant N as Node
  participant T as TCP server
  participant S as Sweep task
  participant B as Event bus
  participant U as Browser
  loop every 5s
    N->>T: heartbeat {id}
    T->>T: refresh last_seen (registry only, no DB write)
    T->>B: heartbeat pulse (rtt)
    B->>U: live pulse
  end
  loop every few seconds
    S->>S: scan registry for stale last_seen
    S->>B: node_down (if past threshold)
    B->>U: node greys out
  end
```

## Data model

Two stores. The **registry** is in-memory, live, and disposable. The **database**
is SQLite, durable, and the record of truth for anything that must survive a
restart. WAL is on so reads don't block the ingest writer; output appends are
batched to protect SD-card throughput.

```mermaid
erDiagram
  nodes ||--o{ commands : "issues"
  commands ||--o| results : "produces"
  nodes ||--o{ output_log : "emits"
  nodes ||--o{ events : "logs"

  nodes {
    text id PK
    text label
    text group_name
    text notes
    text fw_version
    int  first_seen
    int  last_seen
  }
  commands {
    int  id PK
    text cmd_id UK
    text node_id FK
    text type
    text payload
    text status
    int  issued_at
    int  completed_at
  }
  results {
    int  id PK
    int  command_id FK
    text cmd_id
    text status
    text payload
    int  received_at
  }
  output_log {
    int  id PK
    text node_id FK
    text cmd_id
    text text
    int  received_at
  }
  events {
    int  id PK
    text node_id
    text type
    text detail
    int  ts
  }
  macros {
    int  id PK
    text name
    text group_name
    text steps
    int  dangerous
  }
  settings {
    text key PK
    text value
  }
```

`output_log` and `events` are pruned on a daily schedule per their retention
settings; `commands`/`results` are kept longer; `nodes`/`macros` are never
auto-pruned. The registry holds `writer`, `last_seen`, `status`, `rtt_ms`, and
`inflight` per node — none of which is persisted.

## Repository layout

```
PICOTTY/
├── README.md                     ← the gist + copy-paste commands
├── docs/                         ← this technical reference
├── .gitignore                    ← ignores private/, hub/data/, firmware/build/
│
├── firmware/                     ← the nodes (CircuitPython)
│   ├── circuitpython/            ← boot.py, code.py, wire/netlink/injector/backchannel/
│   │                               nodeconfig/messages, settings.toml.example, README.md
│   ├── scripts/                  ← install-deps.sh, build.sh, deploy-zip.sh
│   ├── tools/                    ← testhub.py  (mock hub to test a node)
│   └── build/                    ← staged artifacts (gitignored)
│
├── hub/                          ← the management side (Python)
│   ├── src/picotty/              ← the picotty package (installed, console scripts)
│   │   ├── hub/                  ← main, config, registry, db, eventbus,
│   │   │                           core, tcp_server, tasks, api/{rest,ws,models}
│   │   ├── client/               ← client-side helpers
│   │   ├── protocol.py           ← wire protocol
│   │   ├── sim.py                ← fake node to test the hub (picotty-sim)
│   │   └── static/               ← Swarm Control dashboard (index.html, app.js, styles)
│   ├── scripts/                  ← install.sh, run.sh, install-service.sh, swarm-hub.service
│   ├── tests/                    ← offline checks (test_db.py)
│   ├── data/                     ← hub.db (gitignored)
│   ├── pyproject.toml            ← project + deps (picotty-hub / picotty-sim scripts)
│   └── uv.lock
│
├── target-setup/                 ← run ON a target machine
│   ├── proxmox-serial.sh         ← target emits its serial shell to the node
│   └── pico-debug.sh             ← open the node's REPL from the target host
│
└── private/                      ← secrets + per-node config (gitignored)
    ├── nodes/<id>/settings.toml
    ├── provision.py              ← stamp token into configs + seed the hub DB
    ├── hub-token.txt             ← shared node token (systemd EnvironmentFile)
    └── demo.json                 ← optional populated offline demo
```

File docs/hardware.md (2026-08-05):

[← Docs index](README.md) · [← Project README](../README.md)

# Hardware

## Physical topology

The shape is a star. The hub sits at the center. Every node is a leaf with two
independent attachments: a USB cable to its target machine, and an Ethernet cable
to the management switch. Nothing connects node to node. Addresses below are
illustrative placeholders — use your own management subnet.

```mermaid
graph TB
  subgraph MGMT["Management VLAN"]
    HUB["Pi Zero 2 W — HUB<br/>static IP<br/>:9000 swarm · :8080 web"]
    SW["Managed switch"]
    HUB --- SW
  end

  SW --- N1["node-01<br/>Pico + W5100S"]
  SW --- N2["node-02<br/>Pico + W5100S"]
  SW --- N3["node-03<br/>Pico + W5100S"]
  SW --- N4["node-04<br/>Pico + W5100S"]

  N1 -->|"USB: HID + serial + power"| T1["target A"]
  N2 -->|"USB: HID + serial + power"| T2["target B"]
  N3 -->|"USB: HID + serial + power"| T3["target C"]
  N4 -->|"USB: HID + serial + power"| T4["target D"]

  OP["Operator browser"] -->|"HTTP + WebSocket (via VPN / tunnel)"| HUB
```

Two facts drive the whole design:

- **The node's Ethernet is on SPI, not USB.** The W5100S talks to the Pico over
  SPI, leaving the Pico's USB free to be a device presented to the target. That is
  what lets a node be a USB keyboard *and* reach the network at the same time.
- **One node per target.** No fan-out. Five machines means five nodes, five
  Ethernet drops, five IPs. The per-node cost is the real sizing driver.

Each node draws power from its target over the same USB cable that carries HID.
When the target is off, the node is off.

## Component itemization

```mermaid
graph TD
  ROOT["PICOTTY"] --> FW["firmware/ — the nodes"]
  ROOT --> HUBC["hub/ — the management side"]
  ROOT --> TGT["target-setup/ — target host config"]
  ROOT --> PRIV["private/ — secrets + per-node config (gitignored)"]

  FW --> FWC["circuitpython/ — boot.py, code.py, modules"]
  FW --> FWS["scripts/ — install-deps, build, deploy-zip"]
  FW --> FWT["tools/ — testhub.py (mock hub)"]

  HUBC --> APP["app/ — TCP + FastAPI + SQLite + registry"]
  HUBC --> STAT["static/ — Swarm Control dashboard"]
  HUBC --> HST["scripts/ — install, run, systemd service"]
  HUBC --> HTL["picotty-sim — fake node"]

  TGT --> PS["proxmox-serial.sh — target emits serial to node"]
  TGT --> PD["pico-debug.sh — debug the node itself"]

  PRIV --> PN["nodes/<id>/settings.toml"]
  PRIV --> PP["provision.py, hub-token.txt, demo.json"]
```

## Bill of materials

**Per node** — one set for each target machine you want to control:

| Component | Role | Qty | Notes |
|---|---|---|---|
| **Raspberry Pi Pico** (RP2040) — *or* **Pico 2** (RP2350) | Runs the CircuitPython node firmware; enumerates on the target as a USB keyboard + serial back-channel | 1 | Pico 2 is a drop-in — identical 40-pin layout and USB; just flash the **Pico 2** CircuitPython `.uf2` and stage libs for that build. Plain (non-W) boards are fine: the node is wired, so on-board Wi-Fi/BLE goes unused. |
| **WIZnet W5100S Ethernet HAT** | Wired Ethernet to the hub over **SPI**, keeping the Pico's USB free for the target | 1 | Seats on the Pico's 40-pin header (SPI0 + reset/interrupt). Driven by `adafruit_wiznet5k`. |
| **USB cable — data-capable** | Power **and** all three USB functions to the target, over the one cable | 1 | Micro-USB for Pico, USB-C for Pico 2. A charge-only cable powers the board but carries no HID/serial — a common gotcha. |
| **Ethernet patch cable** | Node → switch, on the management segment | 1 | |

> **All-in-one alternative:** the **WIZnet W5100S-EVB-Pico** integrates an RP2040 and the W5100S on a single board — it replaces the *Pico + HAT* pair with **no firmware changes**. Use it where you'd rather not stack a HAT.

**Hub** — one, shared by the whole swarm:

| Component | Role | Qty | Notes |
|---|---|---|---|
| **Raspberry Pi Zero 2 W** | Runs the hub: FastAPI dashboard, raw-TCP node server, SQLite history | 1 | Give it a **static IP** — nodes dial it by address. 64-bit Raspberry Pi OS installs the Python wheels (uvicorn/pydantic-core) most smoothly. Any always-on Linux box works too. |
| **Wired Ethernet for the hub** | Puts the hub on the **same wired management segment as the nodes** | 1 | The Zero 2 W has **no built-in Ethernet** (only Wi-Fi). Add wired networking with an Ethernet HAT — e.g. the **Waveshare Ethernet/USB HUB HAT** (also a WIZnet W5500-based Ethernet HAT) — or a USB-OTG Ethernet adapter. See the note below. |
| **microSD card** (8 GB+) | Hub OS + the SQLite database | 1 | |
| **USB power supply** | Powers the hub | 1 | |

> **Put the hub on wired Ethernet.** The nodes reach the hub over wired Ethernet
> (SPI → RJ45), so the hub belongs on that same switched/VLAN segment. The Pi Zero
> 2 W has only Wi-Fi on-board, so give it a wired NIC: an **Ethernet HAT** such as
> the **Waveshare Ethernet/USB HUB HAT** (or any W5500/USB-Ethernet HAT), or a
> USB-OTG Ethernet dongle. Wi-Fi *works* for a bench test, but a wired hub is the
> production posture — it keeps hub↔node traffic on one isolated management
> segment and avoids Wi-Fi drops taking the whole fleet's control plane with them.

**Fabric** — shared:

| Component | Role | Notes |
|---|---|---|
| **Managed switch / isolated VLAN** | Carries node↔hub TCP on an internal segment | The network boundary is **not** an authenticator — the node token still applies on every connection. |

**Sizing:** one Pico (+ HAT) and one Ethernet drop **per target machine**. A five-node swarm is five Picos, five HATs, five IPs, plus the single hub — the per-node cost is the real sizing driver.

Your real node ids, hub address, and token live only under `private/` (gitignored)
— nothing machine-specific is committed.

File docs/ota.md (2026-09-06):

[← Docs index](README.md) · [← Project README](../README.md)

# OTA firmware updates

- [Current status](#current-status)
- [Why this is the highest-risk feature](#why-this-is-the-highest-risk-feature)
- [The safety model](#the-safety-model)
- [Creating a bundle: files or a .zip](#creating-a-bundle-files-or-a-zip)
- [The push flow](#the-push-flow)
- [Rollout posture: canary, one node at a time](#rollout-posture-canary-one-node-at-a-time)
- [The writable-filesystem trade-off](#the-writable-filesystem-trade-off)
- [When OTA fails: wipe and reflash by hand](#when-ota-fails-wipe-and-reflash-by-hand)

Updating firmware by hand means physically touching every Pico — for a rack of
nodes that is the real operational cost. CircuitPython can remount its own
filesystem writable, so a node can receive new files over the wire and reload
itself. OTA is that: a hub-driven, chunked, checksummed file push with a
known-good fallback so a bad update self-reverts.

## Current status

**OTA is fully wired, end to end.** The firmware safety machinery and the
transport wiring and the hub side are all in place:

- `firmware/circuitpython/otaflash.py` implements the staging, SHA-256
  verification, atomic-ish swap, `.bak` backup, watchdog-revert, and
  finalize-when-healthy logic described below. This is the hard, dangerous part.
- **The firmware wiring:** `code.py` imports `otaflash`, advertises the `ota`
  capability (only when `OTA_ENABLED` is on *and* the write probe + `adafruit_hashlib`
  succeed), and dispatches `ota_begin`/`ota_chunk`/`ota_commit`; it calls
  `ota.finalize()` on a healthy heartbeat. `boot.py` calls `recover_if_pending()`
  early in boot; the `OTA_ENABLED` setting exists in `nodeconfig.py` /
  `settings.toml`.
- **The hub side:** `hub/src/picotty/hub/ota.py` provides bundle storage (under
  `hub/data/firmware/`), the per-node chunked push, and the canary rollout, with
  REST endpoints (`GET/POST /api/ota/bundles`, `POST /api/nodes/{id}/ota`,
  `GET /api/nodes/{id}/ota/{job_id}`, `POST /api/bulk/ota`).

The capability gate does exactly its job: a node that cannot safely receive OTA
(read-only filesystem, or no `adafruit_hashlib`) never advertises `ota`, so the
hub never offers it a push. This page is both the design of record for the safety
model and the operator runbook for the shipped feature.

## Why this is the highest-risk feature

A bad firmware push deploys to hardware you may not be able to reach. If an update
crash-loops a node in a rack you can't physically get to, and there is no
automatic escape, that node is bricked until someone walks to it with a laptop and
holds BOOTSEL. Every design choice below exists to make that outcome impossible
*without human help*. The rule: **build the safety rails first, and never push to
the whole fleet at once.**

## The safety model

Four rails, in order, each one covering the previous one's failure:

1. **It only runs on a writable filesystem.** OTA needs `boot.py` to have
   remounted `/` writable-to-CircuitPython — which (like `LOG_TO_FILE`) makes the
   `CIRCUITPY` drive read-only over USB, the production posture anyway (USB drive
   hidden). A node that cannot write does not advertise `ota`, so the hub never
   tries to push to it.
2. **Integrity is verified before anything is swapped.** Each file carries a size
   and a SHA-256 in the manifest; every staged file's hash and length must match
   before a single live file is touched. SHA-256 comes from `adafruit_hashlib`;
   without that library the node reports `ota` unavailable rather than trusting an
   unchecked transfer. A half-received or corrupt bundle is discarded and the live
   firmware is left exactly as it was.
3. **The swap keeps the old files and drops a pending marker.** On commit, each
   replaced file is renamed to `<file>.bak` and an `/ota_pending.json` marker is
   written listing what changed. The staged files are moved into place, then the
   node reloads.
4. **A crash-looping update reverts itself on the next reset.** `boot.py` calls
   `recover_if_pending(was_watchdog)` early in boot. If a pending marker
   exists **and this boot followed a watchdog reset** — i.e. the new firmware hung
   and the ~8 s hardware watchdog restarted the node — the `.bak` set is restored
   automatically and the marker is cleared. The node comes back on the old, known-good
   firmware without anyone touching it.

The counterpart to rail 4 is **finalize-when-healthy**: once the *new* firmware
has actually booted, connected to the hub, and run, it calls `finalize()`, which
deletes the `.bak` files and the pending marker. From that point a later,
unrelated watchdog reset can never revert a firmware that already proved it works.
So the window in which an update can auto-revert is exactly "it was just installed
and hasn't successfully run yet" — which is precisely the window you want it in.

All of `otaflash.py`'s filesystem operations swallow errors during boot recovery:
recovery must never itself raise in `boot.py` and brick a node.

The whole commit → reboot → recover-or-finalize decision, end to end:

```mermaid
flowchart TD
    A[ota_commit: verify every file's size and SHA-256] -->|mismatch| Z[Discard staging, live firmware untouched]
    A -->|all match| B[Swap staged files in]
    B --> C[Rename each replaced file to file.bak]
    C --> D[Write /ota_pending.json marker]
    D --> E[supervisor.reload onto new firmware]
    E --> F{Next boot: what kind of reset?}
    F -->|watchdog reset, new firmware hung| G[recover_if_pending restores the .bak set and clears the marker]
    F -->|clean boot, connects, runs a heartbeat| H[finalize deletes the .bak files and the marker]
    G --> I[Node returns on the old, known-good firmware]
    H --> J[New firmware is now permanent, cannot be reverted]
```

### Path safety

A bundle path must be a plain relative path under the drive root — no leading `/`,
no `..` traversal. A hostile or malformed manifest cannot write outside
`CIRCUITPY`.

## Creating a bundle: files or a .zip

Before anything is pushed, the firmware to ship lives on the hub as a **bundle** —
a directory under `hub/data/firmware/<name>/` holding the file blobs and a
`manifest.json` (each file's path, size, and SHA-256, plus a `total_sha256`).
There are two ways to create one.

**From hand-picked files** — `POST /api/ota/bundles`:

```json
{"name": "node-01-v3", "files": [{"path": "code.py", "content_b64": "..."},
                                  {"path": "nodeconfig.py", "content_b64": "..."}]}
```

Each file is base64 in the request; the dashboard's "Manage bundles…" sheet reads
the picked files in the browser and fills this in. The name must match
`[A-Za-z0-9._-]{1,64}`.

### Uploading a bundle as a .zip

Picking files one by one is fine for a one-line patch but tedious for a whole
firmware (with `lib/` that is hundreds of files). Instead, upload the entire
firmware as a single `.zip` — `POST /api/ota/bundles/zip`:

```json
{"name": "node-01-v3", "zip_b64": "<base64 of a .zip>"}
```

`zip_b64` is the base64 of a `.zip` archive. The hub **decompresses it
server-side** and stages every entry, so the browser never has to enumerate the
files. Two conveniences make the archive "just work":

- **A single shared top-level directory is stripped.** Zipping the *folder*
  `Node-Main/` yields entries like `Node-Main/code.py`; the hub detects that every
  entry shares one leading directory and strips it, so the bundle contains
  `code.py`, not `Node-Main/code.py`. (A flat zip with no common prefix is left
  as-is.)
- **Junk entries are skipped** — `__MACOSX/`, `.DS_Store`, `boot_out.txt`,
  `Thumbs.db` are never staged.

Every path is then validated exactly like a hand-built bundle (plain relative
paths only — no leading `/`, no `..`), and the same size/count caps apply
(≤ 400 files, ≤ 1 MiB/file, ≤ 8 MiB/bundle). A malformed archive is rejected with
HTTP **422** (`bad_zip`, or `not a valid zip file`); the bundle name defaults to
the uploaded file's basename (sanitized) when the name field is blank.

**`build.sh` already produces exactly this.** Building with `--stage` writes both
`firmware/build/<node>/` and `firmware/build/<node>.zip` — that `.zip` is precisely
what the upload endpoint expects, so the normal path is: build the node artifact,
then upload its `.zip` as a bundle.

```bash
bash firmware/scripts/build.sh --node <id> --stage   # -> firmware/build/<id>.zip
#   …then upload firmware/build/<id>.zip via "Upload .zip" (or POST /api/ota/bundles/zip)
```

<p align="center">
  The per-node OTA firmware push panel — bundle picker and live byte-progress
  <br><sub>The per-node OTA panel: pick a bundle, push, and watch live byte-progress until the node reports healthy.</sub>
</p>

## The push flow

Once a bundle exists, pushing it to a node (`POST /api/nodes/{id}/ota`) runs the
begin → chunk → commit → reconnect flow below. Progress streams to every browser
as `ota_progress` events; poll `GET /api/nodes/{id}/ota/{job}` for a snapshot.

```mermaid
sequenceDiagram
    actor Op as Operator
    participant Hub
    participant Node as Node (Pico)
    Op->>Hub: Create bundle (pick files or upload .zip)
    Op->>Hub: Push bundle to node
    Hub->>Node: ota_begin {files[path,size,sha256], total_sha256}
    Node-->>Hub: ok — staging opened, one file per entry
    loop each file, in 4 KB chunks
        Hub->>Node: ota_chunk {path, seq, data as hex}
        Node-->>Hub: ok — appended to staging, running hash updated
    end
    Hub->>Node: ota_commit {}
    Node-->>Hub: ok — every size + SHA-256 verified, swapped in
    Note over Node: writes .bak backups + /ota_pending marker, then supervisor.reload()
    Node->>Hub: hello — reconnects on the new firmware
    Hub->>Hub: canary gate — reconnected healthy?
```

Three node commands carry a bundle, designed to stream without growing memory:

| Command | Payload | Node does |
|---|---|---|
| `ota_begin` | `{files: [{path, size, sha256}], total_sha256}` | Clears staging, opens an empty staging file per manifest entry. |
| `ota_chunk` | `{path, seq, data}` (`data` is hex) | Appends the chunk to that file's staging area and updates its running hash. |
| `ota_commit` | `{}` | Verifies every file's size + SHA-256, swaps in with `.bak` backups, writes the pending marker, reloads. |

Chunks are **4 KB** raw (≈8 KB as hex, under the node's 16 KB frame cap) and
written straight to a staging file, so a large bundle never grows the heap. The
cooperative loop keeps feeding the watchdog between chunk frames exactly as it does
for serial output — filesystem writes on CircuitPython can be slow, so the work is
budgeted the same way `drain_tx` budgets serial writes.

**Resilient transfer.** A transient link drop *during* begin/chunk retries the
whole transfer (up to a few times) rather than failing the push — this is safe
because `ota_begin` re-wipes staging and nothing is swapped until commit. Commit
itself is sent once and never retried (see the safety model above).

## Scoped pushes: firmware-only / settings-only

A push takes a **scope** so you can update code and configuration independently —
the hub simply filters which files of the bundle it sends, and the node writes
exactly what it receives (no firmware change needed):

| Scope | Sends | Use |
|---|---|---|
| `all` (default) | every file in the bundle | a full deploy |
| `firmware` | everything **except** `settings.toml` | update the code, **keep each node's existing config** |
| `settings` | **only** `settings.toml` | change config, **keep the running code** |

```bash
# update code on a node, leaving its settings.toml alone
curl -X POST http://hub:8080/api/nodes/Node-IC2/ota \
     -H 'Content-Type: application/json' \
     -d '{"bundle":"Node-IC2-dualhub","scope":"firmware"}'

# push only settings.toml (e.g. retune HUB_FAILOVER_TRIES) — code untouched
curl ... -d '{"bundle":"Node-IC2-dualhub","scope":"settings"}'
```

In the dashboard the **Update firmware** sheet has an **Update scope** selector
(Everything / Firmware only / Settings only). A push whose scope leaves nothing to
send (e.g. `firmware` on a settings-only bundle) is rejected with `empty_scope`.
`POST /api/bulk/ota` takes the same `scope`. Because a settings-only push carries
just one small file, it's the way to retune a board's timing/failover knobs
without reflashing code.

The reload uses the same `supervisor.reload()` soft-reload path as `reboot`: it
restarts the firmware **without** re-enumerating USB, so the target keeps seeing
the node's keyboard and serial port across the update.

Any recoverable failure (bad path, size or hash mismatch, commit with no begun
bundle) is reported as a `failed` result, never a crash — the half-written staging
area is discarded and the live firmware is untouched.

## Rollout posture: canary, one node at a time

The single most important operational rule: **never flash the whole fleet in one
shot.** The hub orchestration (`POST /api/bulk/ota`) is a staged rollout with a
canary — push to one node, wait for it to reconnect on the new `fw` version and
run a clean heartbeat (i.e. prove rail 4 didn't have to fire), and only then
proceed to the next node or small batch. A bad bundle then costs you exactly one
node's auto-revert cycle, not a dark rack.

```mermaid
flowchart TD
    A[Rollout: node list + bundle] --> B[Push to the first node, the canary]
    B --> C{Canary reconnected healthy?}
    C -->|no| D[Abort rollout, report canary status, touch nothing else]
    C -->|yes| E[Push to the next node]
    E --> F{More nodes left?}
    F -->|yes, wait stagger_ms| E
    F -->|no| G[Rollout complete]
```

Verify the revert path deliberately before trusting it in production: push a
knowingly-broken `code.py` to a single bench node and confirm it watchdog-resets,
restores the `.bak` set, and reconnects on the old firmware on its own. Exercise
the whole flow against one node on the bench (via `firmware/tools/testhub.py`)
before any bulk path exists.

## The writable-filesystem trade-off

OTA and normal drag-drop deployment are mutually exclusive on a given boot, for
the same reason `LOG_TO_FILE` is (see
[firmware.md](firmware.md#circuitpython-version-rules)): a filesystem writable to
CircuitPython is **read-only over USB**. An OTA-capable node is one you update
*over the network* precisely because you have given up updating it *over USB* —
that is the whole point, and it is the production posture (USB drive hidden) you
would run a deployed node in anyway. A node left in host-writable mode for
bench work simply won't advertise `ota`, and that is correct.

## When OTA fails: wipe and reflash by hand

The automatic watchdog-revert (rail 4) recovers a node from a *crash-looping*
update on its own. But some failures need hands-on recovery — an OTA push that
errors out repeatedly, a bundle that boots but is wrong, a node you simply want to
re-provision. The catch is that an OTA node's `CIRCUITPY` drive is **read-only over
USB** (that is the writable-filesystem trade-off above), so you can't just drag new
files onto it or delete the old ones.

The escape hatch is **`firmware/scripts/wipe-pico.sh`**. It reaches the node over
the one channel that still works when USB is write-locked — the CircuitPython
**REPL** on the console serial port — disables the watchdog, and reformats the
filesystem (`storage.erase_filesystem()`). That returns `CIRCUITPY` to an **empty,
host-writable** drive, after which you deploy the current firmware by hand exactly
as you would a fresh board:

```bash
# 1. Wipe the write-protected node (auto-grants the serial port with sudo chmod).
bash firmware/scripts/wipe-pico.sh                 # or --dev /dev/ttyACM0
#    --files instead does a softer delete (keeps lib/); --status just shows the port.

# 2. The drive comes back empty and writable — redeploy the built firmware:
bash firmware/scripts/build.sh --node <id> --drive /run/media/$USER/CIRCUITPY
#    …or drag the contents of firmware/build/<id>/ onto CIRCUITPY, then power-cycle.
```

If the REPL can't be reached at all (no console port, or the watchdog resets the
board before the wipe lands), fall back to the guaranteed hardware path: hold
**BOOTSEL** while plugging the Pico in, then drop the CircuitPython `.uf2` (fresh
install) or Adafruit's `flash_nuke.uf2` (full erase) onto the `RPI-RP2` drive, and
redeploy. See the script's `--help` for the full manual REPL sequence
(`Ctrl-C` → `import storage; storage.erase_filesystem()`).

Nothing unique is lost in a wipe: each node's identity lives in
`private/nodes/<id>/settings.toml`, and `build.sh` re-stitches it back in on the
next deploy.

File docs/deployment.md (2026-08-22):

[← Docs index](README.md) · [← Project README](../README.md)

# Deployment

## The plan

PICOTTY is delivered in three layers, built and deployed in this order:

```mermaid
flowchart LR
  P1["Phase 1 — Nodes<br/>CircuitPython firmware<br/>(HID + serial + Ethernet)"]
  P2["Phase 2 — Hub<br/>asyncio TCP + FastAPI + SQLite<br/>+ Swarm Control dashboard"]
  P3["Phase 3 — Targets<br/>serial console<br/>+ stable device names"]
  P1 --> P2 --> P3
  P2 -.observes + drives.-> P1
  P3 -.emits serial to.-> P1
```

- **Phase 1 — Nodes.** Flash CircuitPython, deploy firmware, verify each node in
  isolation with a mock hub, then join it to the fleet.
- **Phase 2 — Hub.** Runs on the Pi Zero 2 W: listens for every node, records
  history, and serves the dashboard where you watch and drive the fleet.
- **Phase 3 — Targets.** Configure each managed machine to emit its serial console
  to its node, with a device name that survives reboots.

## End-to-end workflow

```mermaid
flowchart TD
  subgraph HUBSETUP["Hub (Pi Zero 2 W)"]
    H1["hub/scripts/install.sh"] --> H2["hub/scripts/install-service.sh"]
    H2 --> H3["hub listening :9000 / :8080<br/>token adopted from hub-token.txt"]
    H3 --> H4["private/provision.py --seed-db<br/>(label the nodes)"]
  end

  subgraph NODESETUP["Each node (Pico)"]
    N1["Flash CircuitPython .uf2"] --> N2["firmware/scripts/build.sh --node <id> --stage"]
    N2 --> N3["Drop build/<id>/ contents onto CIRCUITPY"]
    N3 --> N4["Power-cycle"]
    N4 --> N5{"LED solid + appears in hub?"}
    N5 -->|no| ND["Debug: LED code · /error.txt · pico-debug · testhub"]
    N5 -->|yes| N6["Node online in the fleet"]
  end

  subgraph TARGETSETUP["Each target"]
    T1["target-setup/proxmox-serial.sh"] --> T2["serial shell on /dev/ttyPICO"]
  end

  H3 -.nodes dial the hub.-> N6
  N6 --> T1
```

**Step by step:**

1. **Hub.** On the Zero 2 W: `bash hub/scripts/install.sh` then
   `bash hub/scripts/install-service.sh`. It adopts the shared token from
   `private/hub-token.txt` and starts listening. Optionally seed labels:
   `python3 private/provision.py --token <TOKEN> --seed-db hub/data/hub.db`.
2. **Bench-test a node.** Flash CircuitPython, build + deploy the firmware, point
   the node's `HUB_IP` at your laptop, and run
   `python3 firmware/tools/testhub.py --selftest` — confirm ping/read/config/
   heartbeat pass before it goes headless. (`--framecheck` runs the framing unit
   checks with no hardware at all.)
3. **Deploy nodes.** Set `HUB_IP` back to the hub's address, deploy, power-cycle.
   Each node dials the hub and appears in the dashboard.
4. **Configure targets.** On each managed machine run
   `target-setup/proxmox-serial.sh` so it emits its serial console to the node.
5. **Operate.** Open `http://<hub-ip>:8080`, pick a node, watch its console, and
   drive it (keys, chords, macros, bulk). Everything is logged.

## Optional: a backup hub

For failover, stand up a **second hub** and point boards at it. The two hubs are
independent (own DB each) and share only the node token:

1. Install the backup hub exactly like the primary, but give it a **distinct
   `HUB_ID`** (`HUB_ID=hub-backup picotty-hub`) so you can tell them apart.
2. Set the **same node token** on both hubs (its `node_token_hash` must match), so
   either can authenticate the same board.
3. On each node's `settings.toml`, point `HUB_IP_BACKUP` at the backup hub. Nodes
   prefer the primary and fail over to the backup when it's unreachable.
4. On **both** hubs, set **`HUB_PEERS`** to the *other* hub's base URL (e.g.
   `HUB_PEERS=http://192.168.1.169:8080` on the primary, and the primary's URL on
   the backup). This enables cross-hub takeover and peer visibility: each hub shows
   boards held by its peer as "active on `<peer>`", and steering a board a hub
   doesn't hold relays the directive to the peer that does — so you can pull a
   board across from either dashboard. Peer calls carry no auth, so this assumes a
   trusted management VLAN.

The **Telegram sidecar** can run on both hosts too: set `HUB_BASE_URL_BACKUP` so
the bot fails over between hubs, but keep only **one** unit enabled at a time
(Telegram allows one active receiver per bot token) — the other is a hot spare.

Full model, runtime steering, and token setup: **[dual-hub.md](dual-hub.md)**.

## Script execution reference

All shell scripts are run with `bash <script>` (no chmod needed). Python tools run
with `python3`.

| Script | Run on | Purpose |
|---|---|---|
| `firmware/scripts/install-deps.sh` | flashing machine | Install `circup` + `mpy-cross` tooling. |
| `firmware/scripts/build.sh` | flashing machine | Deploy firmware to a mounted board (`--drive`) **or** build a drop-in artifact (`--stage`); installs Adafruit libs via circup; includes a node's `settings.toml` (`--node`). Staged library version defaults to CircuitPython 10.2.1 — override with `--cp-version`. |
| `firmware/scripts/deploy-zip.sh` | flashing machine | Extract a staged `.zip` onto a `CIRCUITPY` drive (for a machine that only has the zip). |
| `firmware/tools/testhub.py` | any machine | Mock hub: exercise a real node's every command, interactively or `--selftest`; `--framecheck` runs offline framing unit checks. |
| `hub/scripts/install.sh` | hub (Pi) | `uv sync --extra hub` (creates `hub/.venv`) + fetches the terminal libs. |
| `hub/scripts/run.sh` | hub (Pi) | Run the hub in the foreground (loads `hub-token.txt`). |
| `hub/scripts/install-service.sh` | hub (Pi) | Install + enable + start the systemd service. |
| `picotty-sim` (packaged simulator) | any machine | Fake node: exercise the hub + dashboard with no hardware. |
| `hub/tests/test_db.py` | any machine | Offline SQLite checks for the hub's data layer. |
| `private/provision.py` | anywhere | Stamp the token into node configs and seed the hub DB. |
| `target-setup/proxmox-serial.sh` | target host | Pin the node's serial device to `/dev/ttyPICO` + run a serial login shell. |
| `target-setup/pico-debug.sh` | target host | Open the node's CircuitPython REPL over USB (live debug). |

**Common invocations** (`<id>` = one of your node ids from `private/nodes/`):

```bash
# --- flashing a node ---
bash firmware/scripts/install-deps.sh
bash firmware/scripts/build.sh --node <id> --stage                # -> firmware/build/<id>/ + .zip
bash firmware/scripts/build.sh --node <id> --drive /run/media/$USER/CIRCUITPY   # direct
bash firmware/scripts/deploy-zip.sh firmware/build/<id>.zip       # on another machine
python3 firmware/tools/testhub.py --selftest                      # verify the node
python3 firmware/tools/testhub.py --framecheck                    # offline framing checks

# --- the hub ---
bash hub/scripts/install.sh
bash hub/scripts/install-service.sh
uv run picotty-sim --id <id> --token <TOKEN>                      # test without hardware
hub/.venv/bin/python hub/tests/test_db.py                         # offline db checks

# --- a target ---
sudo bash target-setup/proxmox-serial.sh            # emit serial to the node
sudo bash target-setup/pico-debug.sh                # debug the node itself
```

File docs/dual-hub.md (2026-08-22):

[← docs index](README.md)

# Dual-hub failover

Give a node a **primary** and a **backup** hub. The node prefers the primary,
fails over to the backup when the primary is unreachable, and either hub can
drive the board. A hub — the dashboard today, an app tomorrow — can also **steer**
a board at runtime: move it to the other hub, or promote the backup to be its new
home. It is the lights-out-management equivalent of a second power feed.

## The model: independent peers, one connection at a time

The two hubs are **independent**. Each runs its own process and its own SQLite
database; they do **not** replicate state. They share exactly one thing: the
**node token**, so either can authenticate the same board.

```mermaid
graph TB
  subgraph HUBS["Two independent hubs (own DB each)"]
    A["hub-main :9000<br/>(primary)"]
    B["hub-backup :9000<br/>(backup)"]
  end
  N["node A2<br/>HUB_IP + HUB_IP_BACKUP"]
  N -->|"prefers primary"| A
  N -.->|"fails over when primary is down"| B
  A -. "shared node token only" .- B
```

A board holds **exactly one** connection at a time, so there is no split-brain
and no coordination between hubs. What this buys you and what it doesn't:

- **Fails over:** the live control connection moves to the backup. You keep full
  control of the board from the backup's dashboard/API/bot.
- **Does not move with the board:** per-hub data — queued commands, session
  recordings, OTA jobs, command history, alert settings — stays on the hub that
  recorded it. Each hub shows only the boards currently connected to *it*.

If you need history that spans both hubs, export/read it from each; there is no
merge. This is deliberate — a homelab backup hub should be simple and reliable,
not a distributed database.

## Node configuration

In the node's `settings.toml` (see
[settings.toml.example](../firmware/circuitpython/settings.toml.example)):

```toml
HUB_IP = "10.20.0.10"          # primary (required, as before)
HUB_PORT = 9000

HUB_IP_BACKUP = "10.20.0.11"   # backup — set this to enable failover
HUB_PORT_BACKUP = 9000

# Optional labels, shown on the dashboard / in Telegram and used as the target
# name when you steer a board. Defaults: "primary" / "backup".
HUB_LABEL = "primary"
HUB_LABEL_BACKUP = "backup"

# Failback policy after a failover:
#   sticky     (default) stay on whichever hub is working — never interrupts a
#              live session. Move back manually when you want.
#   preemptive retry the most-preferred hub first on every reconnect, so a
#              recovered primary is used again on the next reconnect.
HUB_FAILBACK = "sticky"

HUB_FAILOVER_TRIES = 2         # connect failures before rotating to the other hub
```

Leave `HUB_IP_BACKUP` unset and the node behaves exactly as a single-hub node —
this change is fully backward compatible.

**Both hubs must share the node token.** `NODE_TOKEN` on the board must match the
`node_token_hash` on *both* hubs (see [below](#sharing-the-node-token)). And both
hubs ping their nodes by default (`HUB_NODE_PING_INTERVAL_MS`), which the node's
`HUB_TIMEOUT_MS` relies on — so don't disable pinging on the backup.

## How the node chooses (the selector)

The node's `HubSelector`
([hubselect.py](../firmware/circuitpython/hubselect.py)) keeps an ordered list of
hubs and points the transport at the chosen one before each connect:

- **Boot / normal:** dial the primary.
- **Primary unreachable:** after `HUB_FAILOVER_TRIES` failed connects, rotate to
  the backup.
- **Sticky (default):** once a hub accepts the board, keep using it across benign
  drops. A recovered primary does **not** yank a live session back.
- **Dead-hub detection:** if the connected hub goes silent past `HUB_TIMEOUT_MS`,
  the node drops it and reconnects (retrying the same hub first, then rotating).

Failover triggers are the same signals the node already used for reconnect —
there is no extra polling and no second socket (the WIZnet chip has only four).

## Steering a board at runtime

Each hub advertises its identity to a board right after it connects (a `welcome`
frame carrying the hub's `HUB_ID`), so the board always knows **which hub it is
talking to**. An authenticated hub can then send the board a directive:

| Action | Effect |
|---|---|
| **switch** | Move to the target hub **now** (one-shot; preference unchanged — a later failover still prefers the primary). |
| **prefer** | Make the target the board's **preferred/home** hub **and** move now. Persisted — this is "use my backup as my main". |
| **pin** | Lock the board to the target hub, ignoring failover, and move now. Persisted. |
| **unpin** | Release a pin; normal failover resumes. |

The target must be one of the board's **configured** hubs, so a hub can never
redirect a board to an arbitrary address. `prefer`/`pin` persist to
`/hub_pref.json` on the board so they survive a soft reload (best-effort: on a
read-only filesystem — the default without OTA — the override holds for the life
of the process instead).

Drive it three ways:

- **Dashboard:** each node's **Hub** control (Move / Set-as-home / Pin / Unpin).
- **REST:** `POST /api/nodes/{id}/hub` with `{"action": "...", "target": "..."}`.
- **Telegram:** `/hubs` shows which hub each board is on; `/hub <node>
  <switch|prefer|pin|unpin> [target]` steers it (armed / break-glass gated).

## Driving a board from *either* hub (peer relay)

A board holds exactly one hub connection at a time, so only the hub that
currently **holds** the board can push it a frame. That means a plain single hub
can't steer — or even see — a board that's connected to the *other* hub: to the
backup, a board living on the primary just looks offline.

Point each hub at the other with **`HUB_PEERS`** (a comma-separated list of the
other hubs' base URLs) and both gaps close:

```bash
HUB_ID=hub-main    HUB_PEERS=http://192.168.1.169:8080  picotty-hub   # primary knows the backup
HUB_ID=hub-backup  HUB_PEERS=http://192.168.1.174:8080  picotty-hub   # backup knows the primary
```

With peers configured:

- **Peer visibility.** Each hub polls its peers' rosters, so a board live on the
  other hub shows in the list as **"active on `<peer>`"** (a purple badge) instead
  of missing/offline — even for a board this hub has never seen. You know it's up
  and where.
- **On-demand takeover from either hub.** When you steer a board the hub doesn't
  hold, the directive is **relayed** to the peer that does hold it, which delivers
  it — the board then switches over to you. So you can stand at the **backup's**
  dashboard, hit **Move / Set-as-home** on a board that's on the primary, and pull
  it across. (A relayed call is never relayed again, so peers can't loop.)

`HUB_PEERS` assumes a **trusted management VLAN** — peer calls carry no auth,
matching the node-token posture. Leave it unset for a standalone hub; failover
and holding-hub steering still work, you just can't steer/see a board from the
hub that isn't holding it.

## Sharing the node token

The board authenticates with the same `NODE_TOKEN` on every hub, so both hubs
must hold the matching `node_token_hash`. Set it up once:

1. On the primary, note or rotate the node token (dashboard **Settings → rotate
   node token**, or `POST /api/settings/token/rotate`). Flash the token into every
   board's `settings.toml` as `NODE_TOKEN`.
2. On the backup, set the **same** token so its `node_token_hash` matches. The
   simplest path is to point the backup at the same value during install; if you
   rotate later, rotate on both or copy the hash across.

Give each hub a distinct name so you can tell them apart:

```bash
HUB_ID=hub-main    picotty-hub   # primary
HUB_ID=hub-backup  picotty-hub   # backup
```

`HUB_ID` is shown on the dashboard and sent to boards in the welcome frame; it
defaults to the host's name.

## What it looks like end to end

1. Board boots, dials `hub-main`, registers, gets `welcome{hub_id: hub-main}`.
2. `hub-main` loses power. The board's connects fail; after
   `HUB_FAILOVER_TRIES` it dials `hub-backup`, registers there, and you keep
   working from the backup — sticky, so it stays put when `hub-main` returns.
3. You decide the backup should be home: from the backup's dashboard (or `/hub A2
   prefer backup`) you promote it. The board persists the preference; future
   failovers now prefer `hub-backup`.

## The Telegram sidecar in a dual-hub setup

The phone control plane should survive a hub outage too, so the sidecar is
dual-hub aware.

### The bot fails over between hubs

Give the sidecar a backup hub and it prefers the primary, failing over to the
backup if the primary is unreachable — every REST call and the live event stream
follow whichever hub is up:

```ini
# in ~/.config/picotty/telegram.env
HUB_BASE_URL=http://192.168.1.174:8080          # primary
HUB_BASE_URL_BACKUP=http://192.168.1.169:8080   # backup
```

Pick which hub the bot **acts on** from chat:

- **`/source`** — show the two hubs and which one is active.
- **`/source primary`** / **`/source backup`** — switch the bot to that hub. (It
  still auto-fails-over if that hub later goes down.)

So `/source` chooses your **source/fleet**, while `/hub <node> …` (armed) steers
an individual **board** between hubs.

### Running a sidecar on both hosts (one active)

Telegram allows only **one active receiver per bot token** — two processes polling
the same token conflict and drop messages. So run the **same** bot on both hosts
but keep only **one enabled** at a time; the other is a hot spare:

```bash
# on BOTH hosts: install with the SAME telegram.env (token, allowlist, both hubs)
bash telegram-bot/scripts/install.sh

# host A (the one you run day to day): make it the live bot
bash telegram-bot/scripts/install-service.sh    # enables + starts swarm-telegram

# host B (the spare): install the unit but leave it OFF
sudo systemctl disable --now swarm-telegram
```

If host A dies, promote the spare with one command on host B:

```bash
sudo systemctl enable --now swarm-telegram
```

The live bot already reaches **both** hubs (via `HUB_BASE_URL_BACKUP`) and you pick
the source with `/source`, so a single active bot covers the whole fleet — the
second host is purely for surviving the loss of the first host.

## See also

- [architecture.md](architecture.md) — the wire protocol and the node/hub loop.
- [firmware.md](firmware.md) — node lifecycle, LED codes, settings.
- [telegram.md](telegram.md) — the `/hubs` and `/hub` commands in context.

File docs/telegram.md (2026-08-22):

[← Docs index](README.md) · [← Project README](../README.md)

# Telegram sidecar

Reach the hub from your phone without opening the management VLAN to inbound
traffic.

## What it is

The sidecar is a **separate process** — the [`telegram-bot/`](../telegram-bot/)
uv app — not part of the hub. It reaches the hub **only** through the hub's REST
API and `/ws` event stream; it holds no hub internals. It depends on
`picotty[telegram]` and imports `picotty.client` (the `HubClient` + `HubEvents`
SDK), so it needs no repo checkout of the hub — just the installed package. How
`picotty[telegram]` is installed is in [packaging.md](packaging.md).

Telegram is used because the Bot API's **long polling is outbound-only**: the
sidecar opens one HTTPS connection *out* to `api.telegram.org` and holds it — no
inbound port, no webhook, no public endpoint. The only firewall change is an
egress allow to `api.telegram.org` from the hub host. Stopping the sidecar
removes the entire external surface with zero hub impact.

## Setup

Two ways to bring the sidecar up on the hub host. Both end at the **same
credentials file** — `~/.config/picotty/telegram.env` — which the dashboard
writes and the sidecar reads and hot-reloads. No path to align by hand.

**A · From the dashboard (recommended).** In **Settings → the "Telegram sidecar"
card**:

1. Create a bot with [@BotFather](https://t.me/BotFather) and paste the **token**.
2. Add your numeric **chat id** (get it from [@userinfobot](https://t.me/userinfobot)).
3. For the shell tier, click **Generate** for a TOTP secret and add it to an
   authenticator app — or turn "Enable shell tier" off for stats + alerts only.
4. **Save** — the hub validates the token via `getMe` and writes the file.
5. Click **Install / start sidecar** — the hub runs the installer (`uv sync` +
   the shared `.env`) and enables the service, streaming the output into the card.
   The card's status line then reads **sidecar running**.

The install button's service step needs passwordless sudo on the hub (typical on
Raspberry Pi OS); if that isn't set up, the output panel prints the one command to
run by hand.

**B · From the shell.**

```bash
bash telegram-bot/scripts/install.sh          # uv venv + the shared ~/.config/picotty/telegram.env
# fill that file in — by hand, or from the dashboard card above
bash telegram-bot/scripts/run.sh              # foreground test
bash telegram-bot/scripts/install-service.sh  # systemd unit (starts on boot)
```

Then in Telegram: `/status`, `/nodes`, `/uptime`, and — after `/arm <code>` —
`/shell <node>`.

> **After a `git pull` that changes hub code, restart the hub** —
> `sudo systemctl restart swarm-hub` — or new REST routes (like the install
> endpoint) return `405 Method Not Allowed`. The dashboard's static files update
> live, but the Python server is loaded into memory at start.

## Capability tiers

| Tier | Commands | Gate |
|---|---|---|
| **1 · Stats** | `/status` `/nodes` `/uptime [node]` | allowlist |
| **1b · Read-only** | `/events [n]` (recent audit), `/log <node> [lines]` (recent console), `/search <text>` (search console history), `/ping <node>` (active RTT), `/hubs`, `/source [primary\|backup]`, `/macros`, `/runbooks` | allowlist |
| **2 · Alerts** | node down/up, watchdog recovery, command failed, hub restart; `/mute` `/unmute` | allowlist |
| **3 · Terminal** | `/shell [node]`, plain text → getty, control keys (`/ctrlc` `/ctrld` `/ctrlz` `/esc` `/tab` `/enter` …), `/reboot`, `/sysrq` | allowlist **+ armed (TOTP)** |
| **3b · Fleet** | `/bulk <text>` (type into every online node), `/runmacro <id> [node …]`, `/runbook <id> <node …\|all\|group:NAME>`, `/hub <node> …` | allowlist **+ armed (TOTP)** |

Tier 3 rides the hub `send` command and is gated on the node advertising
`serial_tx`. The read-only and fleet commands are thin wrappers over existing hub
REST — nothing new on the hub. Fleet commands touch many boards at once, so they
sit behind the same break-glass arming as the shell. The full command reference is
in [../telegram-bot/README.md](../telegram-bot/README.md).

### Dual-hub commands

With a [backup hub](dual-hub.md) configured, more commands surface which hub each
board is on, pick which hub the bot acts on, and let you steer a board:

- **`/hubs`** (allowlist) — list every board and the hub it's currently connected
  to (its `via <label>`).
- **`/source [primary|backup]`** (allowlist) — pick which hub the bot **acts on**.
  With no argument it shows the two hubs and which is active; `/source primary` /
  `/source backup` switch the bot to that hub. This is the bot's own source/fleet
  selection — distinct from `/hub <node> …`, which steers an individual board
  between hubs.
- **`/hub <node> <switch|prefer|pin|unpin> [target]`** (armed) — steer a board:
  move it now (`switch`), make a hub its home (`prefer`), lock it (`pin`), or
  release a pin (`unpin`). It maps to `POST /api/nodes/{id}/hub`; because it
  redirects control of a board, it is armed / break-glass gated like the shell.
  See [dual-hub.md](dual-hub.md) for the model.

### Dual-hub

The sidecar is dual-hub aware so the phone control plane survives a hub outage.
Give it a backup hub with **`HUB_BASE_URL_BACKUP`** and every REST call and the
live event stream prefer the primary, failing over to the backup when the primary
is unreachable. **`/source`** switches which hub the bot acts on (it still
auto-fails-over afterward).

Telegram allows only **one active receiver per bot token**, so HA is run the
**same** bot on both hosts with only **one enabled** (systemctl) and the other a
hot spare you promote by hand if the first host dies. The live bot already reaches
both hubs, so a single active bot covers the whole fleet. See
[dual-hub.md](dual-hub.md#the-telegram-sidecar-in-a-dual-hub-setup) for the setup.

## Security model

- **Chat-ID allowlist**, checked on *every* update — not just at session start.
  Unknown chats get **silence** (logged), never a reply.
- **Break-glass arming** for tier 3. The allowlist alone isn't enough: a
  compromised phone would otherwise hold shell access. `/arm <TOTP>` arms the
  shell for a bounded window, then it **auto-disarms**; an **idle timeout** ends
  a forgotten session; a replayed code is rejected. Stats, read-only lookups, and
  alerts are always on — the shell (`/shell`, `/reboot`, `/sysrq`) and the fleet
  actions (`/bulk`, `/runmacro`, `/runbook`, `/hub`) require armed.
- **Passwords stay out of chat**: the getty doesn't echo, so nothing sensitive
  is relayed back (your *typed* commands are still in chat history — deleting
  them is on you).
- **Sidecar-local audit log**: chat id, command, node, outcome, and every line
  typed into a target, append-only, chmod 600 — kept sidecar-local so the bot
  needs no hub write endpoint. The bot token and TOTP secret are never logged.
- **Kill switch**: `systemctl stop` the sidecar unit removes the whole external
  surface at once.
- **Egress**: allow the hub host outbound 443 to `api.telegram.org` only.

## How the credential file works

The sidecar's credentials are provisioned from the dashboard, so nothing
sensitive is typed at a shell. **Settings → the "Telegram sidecar" card** drives
the hub's REST layer:

- **`POST /api/telegram`** — validates the bot token against Telegram (`getMe`)
  before saving, then writes the token, allowlist, and shell/alert settings.
- **`POST /api/telegram/totp`** — generates a base32 TOTP secret and returns an
  `otpauth://` URI (render it as a QR for the authenticator app).
- **`POST /api/telegram/install`** — the **Install / start sidecar** button: runs
  the sidecar's own installer on the hub (`uv sync` + the shared `.env`) and
  enables its systemd service, returning the captured output.
- **`GET /api/telegram`** — the card's status: whether it's configured, the bot
  username (via `getMe`), the chat count, and **`service_active`** (sidecar
  running/stopped). Never returns the token or the TOTP secret — both are
  **write-only**.

**One file, no alignment needed.** Both the hub (`TELEGRAM_ENV_PATH`) and the
sidecar (`TELEGRAM_ENV_FILE`) default to the same path, **`~/.config/picotty/
telegram.env`** (chmod 600) — `install.sh` standardizes on it. The sidecar
**hot-reloads** the allowlist and shell/alert settings whenever the file changes,
with no restart. The one exception: a **bot-token change needs a sidecar restart**
(python-telegram-bot binds the token at start), and the sidecar logs that it's
required. A legacy in-repo `telegram-bot/.env` still works as a fallback and is
migrated on the next `install.sh`.

```mermaid
flowchart LR
  DASH["Dashboard<br/>Settings · Telegram card"]
  HUB["Hub REST<br/>/api/telegram · /totp · /install"]
  ENV["~/.config/picotty/telegram.env<br/>chmod 600"]
  SIDE["Sidecar<br/>reads + hot-reloads"]
  TG["api.telegram.org"]
  DASH -->|token · allowlist · install| HUB
  HUB -->|getMe validates token| TG
  HUB -->|writes the shared file| ENV
  ENV -->|hot-reload allowlist + settings| SIDE
  SIDE -->|outbound long-poll| TG
```

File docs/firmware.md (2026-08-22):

[← Docs index](README.md) · [← Project README](../README.md)

# Node firmware

## Lifecycle

The firmware is a single cooperative loop with a hardware watchdog. The onboard
LED encodes the state so a headless node is readable at a glance.

```mermaid
stateDiagram-v2
  [*] --> Boot
  Boot --> Fatal: bad settings.toml / no HID
  Boot --> NetInit: HID ready (blocks on USB enumerate)
  NetInit --> NetDown: Ethernet/DHCP fails
  NetDown --> NetInit: retry (3s)
  NetInit --> Connecting: interface up, watchdog armed
  Connecting --> Online: connect + hello ok
  Online --> Connecting: link drop → backoff (1s→30s)
  Connecting --> Connecting: hub unreachable → backoff
  Fatal --> [*]: idle, needs attention

  note right of Online: LED solid · reports to hub
  note right of Connecting: LED slow blink
  note right of NetDown: LED medium blink
  note right of Fatal: LED fast blink · logs /error.txt
```

Key hardening: growing reconnect backoff, a bounded receive buffer, a per-loop cap
on forwarded output, non-blocking I/O throughout, a bounded connect timeout so a
down hub never hangs the loop, an ~8 s RP2040 watchdog (armed only after startup so
enumeration/DHCP don't false-trip it), and a unique MAC derived per node id.

Firmware is now **1.3.0**.

## Dual-hub failover

A node can carry a **primary and a backup hub** and fail over between them — the
same reconnect signals above drive it, with no extra socket. Set the backup keys
in `settings.toml`:

```toml
HUB_IP_BACKUP = "10.20.0.11"   # set this to enable failover (unset = single-hub)
HUB_PORT_BACKUP = 9000
HUB_LABEL = "primary"          # labels shown on the dashboard / in Telegram
HUB_LABEL_BACKUP = "backup"
HUB_FAILBACK = "sticky"        # sticky (default) | preemptive
HUB_FAILOVER_TRIES = 2         # connect failures before rotating to the other hub
```

The node prefers the primary and, after `HUB_FAILOVER_TRIES` failed connects,
rotates to the backup; a hub can also steer a board at runtime. Leaving
`HUB_IP_BACKUP` unset keeps the old single-hub behaviour, so existing configs are
unaffected. Both hubs must share the node token. Full model, the selector, and the
steering directives are in **[dual-hub.md](dual-hub.md)**.

## LED status codes

| Pattern | Meaning |
|---|---|
| Solid on | Connected to the hub, healthy |
| Slow blink | Powered + networked, but not connected to the hub (retrying) |
| Medium blink | Ethernet/link problem (cannot bring the network up) |
| Fast blink | Fatal config or HID error — needs attention; also logs `/error.txt` |

## Keyboard layout

The node types into the target as a USB HID keyboard, and the mapping from a
character to a keycode is **layout-specific** — it lives in the Adafruit layout
object *on the node*, not on the hub. A node hardcoded to US typing into a target
set to a German/UK/French layout mistypes symbols (the classic "my password has a
`/` and the node typed `-`" bug). So layout is a per-node firmware setting, not
something the hub can translate.

- Set `KEYBOARD_LAYOUT` in the node's `settings.toml` to the code the target
  expects (`us`, `de`, `uk`, `fr`, …). **Default `us`**; an absent setting keeps a
  node typing exactly as before, so old configs are unaffected.
- `us` (or unset/`en`/`en_us`) uses the built-in `KeyboardLayoutUS`. Any other
  code lazily imports the matching community library (`keyboard_layout_win_<code>`,
  which pairs with its own `keycode_win_<code>`). If that library isn't staged on
  the board, the node **logs a warning and falls back to US** rather than failing —
  a misconfigured layout degrades to a working keyboard, never a fatal HID error.
  Make sure the layout library the node needs is installed in its `lib/`.
- The node reports its **active, resolved** layout in `hello` (e.g. `"layout":"de"`,
  or `"us"` if a requested layout fell back). The hub keeps it as **read-only**
  node detail (`layout` on `GET /api/nodes/{id}`) so an operator can see at a glance
  what each node is set to; old firmware omits it and the hub treats that as `us`.

Only the literal-text (`type` / `send`-as-text) path is layout-sensitive; the
named-chord path (`keys`, e.g. `CTRL+C`) maps to keycodes directly and is
unaffected.

## OTA capability

`firmware/circuitpython/otaflash.py` implements over-the-wire firmware updates —
a chunked, SHA-256-verified file push with a `.bak` backup and an automatic
watchdog-revert so a bad update self-reverts on the next reset. It is **fully
wired into the running firmware**: `code.py` imports it, advertises the `ota`
capability (gated on `OTA_ENABLED` plus a writable filesystem and `adafruit_hashlib`),
dispatches `ota_begin`/`ota_chunk`/`ota_commit`, and finalizes on a healthy
heartbeat; `boot.py` calls its boot-time recovery; the `OTA_ENABLED` setting and
the hub-side push path (bundle store, per-node push, canary rollout) are all in
place. A node that cannot safely receive OTA never advertises `ota`, so the hub
never attempts a push to it. The full safety model and the push flow are
documented in [ota.md](ota.md). An OTA node runs with the filesystem writable
(USB drive hidden), the same trade-off as `LOG_TO_FILE` below.
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

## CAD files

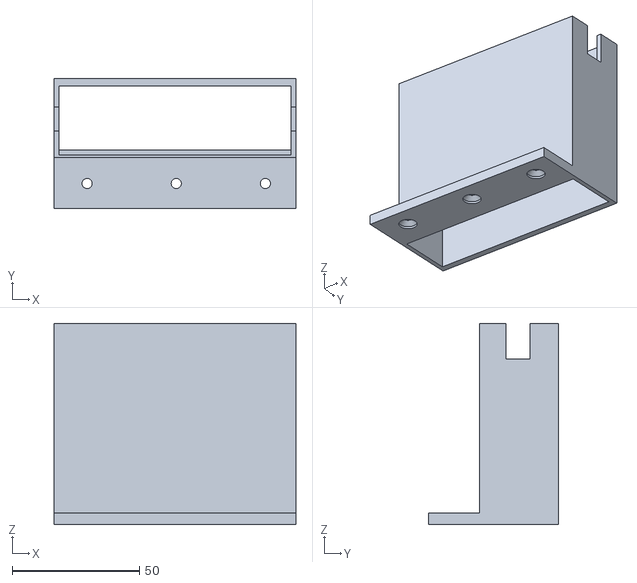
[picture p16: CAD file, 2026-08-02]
Enclosure Cad/Lab Mount Box.stl
95.0 x 51.0 x 79.0

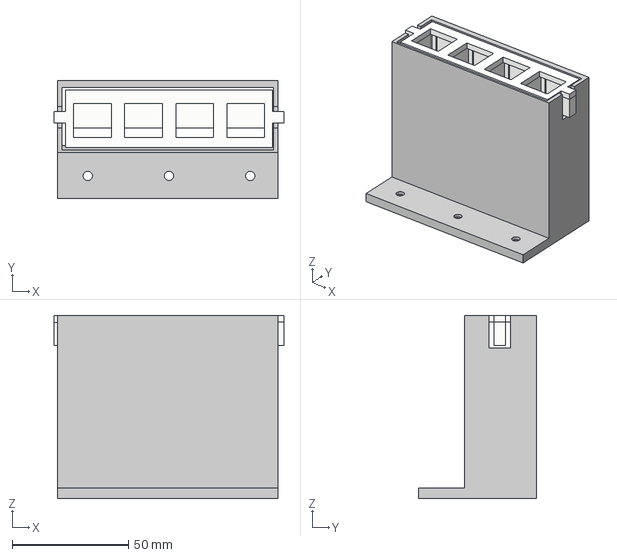
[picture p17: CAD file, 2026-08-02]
Enclosure Cad/PICOTTY-ENCLOSURE.step
99.1 x 51.0 x 79.0 mm

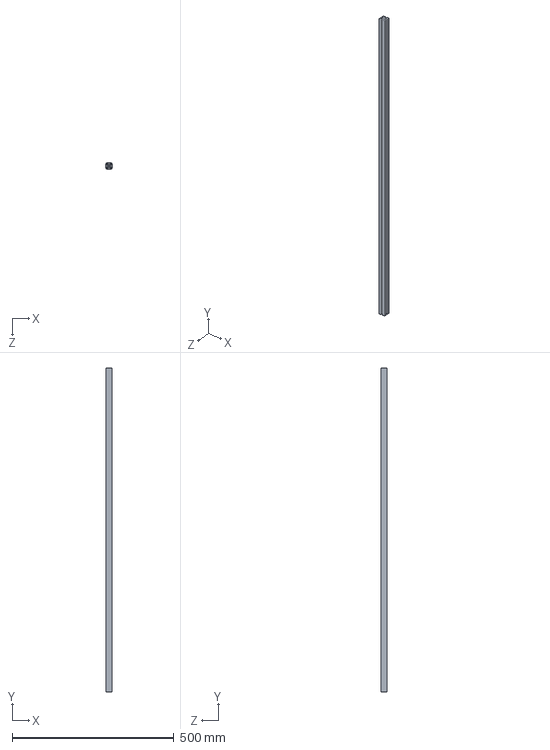
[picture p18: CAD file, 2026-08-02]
Enclosure Cad/Aluminium extrusion 20x20x1000.sldprt
20.0 x 1000.0 x 20.0 mm

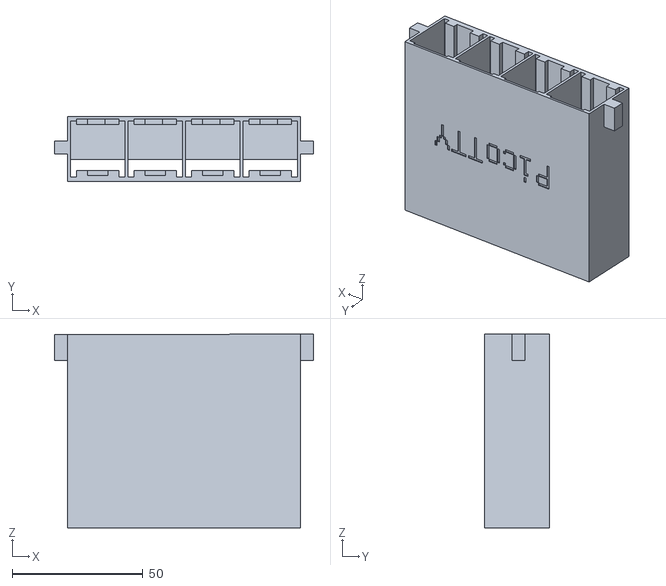
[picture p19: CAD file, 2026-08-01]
Enclosure Cad/Enclosure Body.stl
99.1 x 24.8 x 74.1

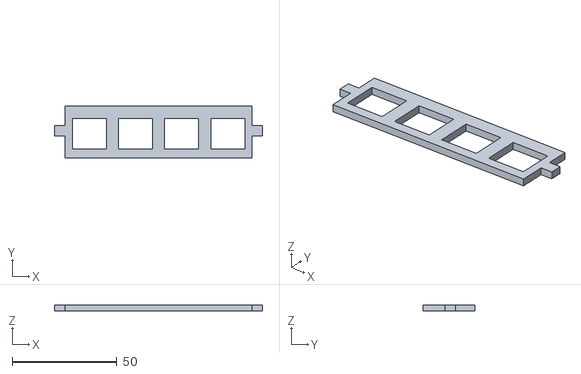
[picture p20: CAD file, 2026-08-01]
Enclosure Cad/Front Side.stl
99.1 x 24.8 x 3.00

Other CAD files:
Enclosure Cad/Aluminium 20x20x1000.step
Enclosure Cad/PICOTTY-ENCLOSURE.f3d

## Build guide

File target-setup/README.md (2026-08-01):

# target-setup

Scripts that run **on a target machine** (the box a Pico is plugged into), not on
the hub. They configure the target to talk to the Pico over its USB serial port.

## proxmox-serial.sh

Run once on each Proxmox host with the Pico plugged in (as root):

```bash
./proxmox-serial.sh            # detect + configure
./proxmox-serial.sh --status   # show what it detects, change nothing
./proxmox-serial.sh --undo      # remove the rule + stop the getty
```

It:
- finds the Pico's `/dev/ttyACM*`,
- pins it to a stable **`/dev/ttyPICO`** via a udev rule (survives reboots and
  the ACM number changing),
- runs a serial **login shell** on it, started automatically whenever the Pico is
  present. Your normal `tty1` shell is untouched.

Add `--boot-console` to also send kernel/boot messages to serial (uses
`ttyACM0` since the kernel needs a name before udev runs; edit if yours differs).

## pico-debug.sh

A bidirectional debug view of the **Pico itself** from the host, over the same USB
cable. A node with `console=True` in `boot.py` (the default) exposes a second
serial port — the CircuitPython REPL — carrying the firmware's `print()` output,
tracebacks, and an interactive prompt.

```bash
./pico-debug.sh            # find the console port and open a terminal
./pico-debug.sh --status   # show which port is CONSOLE vs DATA
./pico-debug.sh --pin       # pin a stable /dev/ttyPICO-console symlink
```

In the terminal: **Ctrl-C** interrupts `code.py` into the REPL, **Ctrl-D** reloads
it. It uses `tio`/`picocom`/`screen` if installed, else a built-in Python terminal
(quit with Ctrl-]).

## Console mode: keep it on if you want the debug view

`pico-debug.sh` needs the REPL port, which only exists with `console=True` in
`boot.py` — **the shipped default**. Both scripts here auto-detect which port is
which by USB interface number (CONSOLE = lower, DATA = higher), so keeping console
on is not ambiguous. Set `console=False` only if you never want to debug the Pico
and prefer a single clean serial port (and rebuild/redeploy after changing it).

### Reading vs. driving the serial shell

This makes Proxmox **emit** its serial shell to the Pico (the Pico *reads* it).
To also *type into* that serial shell — including logging in — the Pico must
**write** to the serial channel, which it now does: the firmware's `send` command
(the dashboard's **Serial** input mode) writes bytes straight into the getty on
this line, so the console becomes a real interactive serial login. This login
shell is exactly what the getty above provides; it is a distinct session from the
host's `tty1`.

Keep the mental split clear:

- **Serial mode** (`send`) drives *this* getty — the interactive Linux login.
- **HID mode** (`type`/`keys`) drives the host's `tty1`, and BIOS/UEFI and the
  GRUB menu, where a USB keyboard drives the console that mirrors to serial.

While you watch the Serial console, HID keystrokes appear to do nothing — they are
landing on `tty1`, not this serial getty. The `send` write path also powers the
hub's automation (the expect engine and runbooks) and the raw serial bridge
(`minicom -D tcp:<hub-ip>:<port>`). Serial mode needs the node's firmware to
advertise `serial_tx`; see the project docs for the full HID-vs-Serial distinction.

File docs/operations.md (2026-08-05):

[← Docs index](README.md) · [← Project README](../README.md)

# Operations & debugging

- [Observability](#observability)
- [Prompt-state at a glance](#prompt-state-at-a-glance)
- [HID input vs. Serial input](#hid-input-vs-serial-input)
- [The console renderer](#the-console-renderer)
- [Session recording & replay](#session-recording--replay)
- [The raw serial bridge](#the-raw-serial-bridge)
- [Alerting hooks](#alerting-hooks)

## Observability

Three concentric views, from a headless node outward to the whole fleet:

```mermaid
graph LR
  LED["Onboard LED<br/>(glance: solid / blink codes)"] --> FILE["/error.txt<br/>(plug in, read the fault)"]
  FILE --> REPL["pico-debug.sh<br/>(live REPL over USB)"]
  REPL --> HUBV["Hub Events + results<br/>(dashboard / journalctl / API)"]
```

- **LED** — solid = connected & healthy; slow blink = up but not connected; medium
  blink = Ethernet problem; fast blink = fatal config/HID error.
- **`/error.txt`** — opt-in (`LOG_TO_FILE = "true"`): config/HID/Ethernet errors,
  watchdog-reset boots, and crashes, readable by plugging the Pico into a computer.
  Trade-off: the drive goes read-only over USB until you re-flash CircuitPython.
- **`pico-debug.sh`** — the node's REPL over its console USB channel: live
  `print()` output, tracebacks, and an interactive prompt (Ctrl-C / Ctrl-D).
- **The hub** — once connected, the node reports home: `node_up`/`node_down`,
  heartbeats + RTT, **error** events (including "recovered from watchdog reset"),
  and every command's `ok`/`failed` result with detail. Read it in the dashboard
  **Events** view, `journalctl -u swarm-hub -f`, or `GET /api/events`.

## Prompt-state at a glance

Online/offline tells you a node is *reachable*; it doesn't tell you *where the
target is*. The hub classifies each node's serial output into a coarse
**prompt-state** — `login`, `password`, `shell`, `grub`, `panic`, or `booting` —
so a per-node badge on the dashboard shows, across the whole fleet, which boxes
sit at a login prompt, which are mid-boot, and which have panicked.

This is computed hub-side from the output stream (no firmware change): a small
ordered set of regexes runs over the freshest bytes of each node's rolling output
tail, and the first match wins. It is **live status, never persisted** — it lives
on the registry like `rtt_ms`, is `null` while a node is offline, and is exposed
read-only via `prompt_state` on `GET /api/nodes/{id}`. When it changes, the hub
broadcasts a `node_state` event to every browser, so badges update without any
console being open. The full pattern table and ordering are in
[automation.md](automation.md#prompt-state-detection) — the same matcher the
expect engine waits on.

## HID input vs. Serial input

The console tab has two input modes, toggled per node.

- **HID mode** injects USB keystrokes (`type`/`keys`/macros); they land on the
  target's keyboard console — `tty1`, BIOS, GRUB — so it is the mode for firmware
  setup, bootloaders, and any target with no serial getty.
- **Serial mode** writes bytes straight into the target's serial line (the `send`
  command) and is the mode for an interactive **Linux serial login**: with a getty
  on the node's data port, keystrokes reach the login session and the getty echoes
  them back through the same channel, so passwords mask and typed characters appear
  with no local echo.

The two are distinct sessions and line up only at BIOS/GRUB; at Linux runtime, HID
drives `tty1` while Serial drives the getty. **A common surprise:** while watching
the Serial console, HID keystrokes appear to do nothing — they are landing on
`tty1`, not the serial getty you're viewing. Serial mode is offered only for nodes
whose firmware advertises the `serial_tx` capability; older firmware shows HID only.

**Control-byte shortcuts.** Because Serial mode writes raw bytes, the common
control characters map straight onto the `send` command's `raw` (hex) field:
Ctrl-C `"03"`, Ctrl-D `"04"`, CR `"0d"`, Tab `"09"`, Esc `"1b"`, Backspace `"7f"`.
Ctrl-C interrupting a running command on the target is the canonical case.

## The console renderer

The console is fed a live text stream over the WebSocket; how it *renders* that
stream determines what you can drive from it.

The console is moving to a vendored **xterm.js** terminal so that ANSI colors,
cursor positioning, and full-screen TUIs (a distro installer, `htop`, `nano`)
render correctly instead of scrolling as garbage — which matters once Serial mode
makes the console interactive. Because the hub runs on an **isolated VLAN with no
internet**, xterm.js is not loaded from a CDN: the operator **vendors** the assets
locally. Download `xterm.js`, `xterm.css`, and the fit addon into
`hub/src/picotty/static/vendor/` and reference them from `index.html`. The hub side needs no
change — output already streams as text; only the client rendering changes.

Where the vendored terminal is not present, the console falls back to the original
append-only text log: terminal control sequences (colors, cursor moves) are
**stripped** at render and full-screen TUIs scroll as plain text rather than
repainting in place. Either way the raw bytes are always stored verbatim in
`output_log` — only the *display* is affected — so a recording or a downloaded log
keeps every byte the target emitted.

## Session recording & replay

`output_log` already stores every chunk with a hub-stamped timestamp, so a past
session — an install, a crash, a boot — can be replayed as it happened without any
new capture path. The hub exports it as an **asciicast v2** recording:

```
GET /api/nodes/{id}/session.cast?since=<ms>&before=<ms>&width=100&height=30
```

`since`/`before` bound the window in milliseconds on the **hub's** `received_at`
clock — the same clock as output timestamps. (Node `ts` is deliberately ignored:
the Picos have no RTC, so their timestamps are monotonic-from-boot, not
wall-clock — see [considerations.md](considerations.md).) The response is a
streamed asciicast: a `{"version":2,...}` header line followed by one
`[offset, "o", text]` event per stored chunk, offsets measured from the first row
in the window.

The `.cast` file plays in any asciinema player — the standalone
`asciinema play file.cast`, the web player, or a vendored `asciinema-player` under
`hub/src/picotty/static/vendor/` (same offline-vendoring reasoning as xterm.js above) wired to
a "replay" affordance that loads a chosen time window. It is read-only over
existing data: no schema change, no firmware change, no protocol change.

## The raw serial bridge

The serial channel is otherwise reachable only through the dashboard. The bridge
exposes an assigned node's serial line as a plain **TCP socket**, so any tool that
speaks a raw serial socket — `minicom`, PuTTY, `conserver`, `esptool` — attaches
to a node unchanged:

```bash
minicom -D tcp:<hub-ip>:<port>      # interactive serial to that node
```

**It is off by default and opt-in per node:**

- Enable the subsystem with the `serial_bridge_enabled` setting (Settings panel or
  `PATCH /api/settings`). Toggling it binds/unbinds listeners immediately.
- Assign a node a port: `POST /api/nodes/{id}/bridge?port=<port>` (1024–65535, not
  a hub face port, not already taken). `GET /api/bridge` lists the map and the
  bind host; `DELETE /api/nodes/{id}/bridge` removes an assignment. The map is
  durable (the `serial_bridge` table); one TCP port per node.
- On a client connection the hub pipes socket bytes → the node's serial line (a
  lightweight `send`, with no DB row per keystroke) and the node's `output` → the
  socket. A node with no `serial_tx` gets a **read-only** bridge — writes are
  dropped. A slow reader that backs up past ~1 MiB is dropped rather than stalling
  the loop, and disconnecting the socket cleanly detaches without affecting the
  dashboard's view of the same node.

**Security boundary.** The bridge is raw and unauthenticated — anything that can
reach the port gets an interactive serial session to that node. Bind it on the
management interface only: the bind host is process-level (`HUB_BRIDGE_HOST`,
default `0.0.0.0`, fine on an isolated VLAN; set it to a specific IP on a
multi-homed hub) and it must never be reachable from outside the segment. This is
the same "network isolation is the real boundary" posture as `:9000` and `:8080` —
see [considerations.md](considerations.md).

## Alerting hooks

For a fleet you stop watching the dashboard, so the hub tells you when something
matters. The audit path (`hub.audit`) is the single place every notable event
already passes through, so outbound notifications hang off it — no polling, no new
code path.

- **Off by default.** Enable `alerts_enabled` and set `alerts_webhook_url` and/or
  `alerts_ntfy_url` in Settings (`PATCH /api/settings`). A generic webhook receives
  the JSON payload; an ntfy URL receives a plain-text body.
- **Which events fire.** Three, selected out of the audit stream:
  - `node_down` — a node goes offline (disconnect or stale-sweep),
  - watchdog recovery — the "recovered from watchdog reset" `error` event a node
    sends after the loop hung and the watchdog restarted it,
  - a command `result` whose status is `failed`.
- **Dedup.** The same `(kind, node)` alert is suppressed for 60 s, so a node that
  flaps down/up every few seconds sends one alert, not a storm.
- **Never blocks the loop.** Each notification is its own asyncio task with a 5 s
  timeout and a single retry; a slow or dead endpoint can't stall the event loop,
  and a delivery that still fails is recorded as an event rather than raised.

Keep the alert endpoints reachable from the isolated segment, or route them
through the same tunnel you use for the dashboard.

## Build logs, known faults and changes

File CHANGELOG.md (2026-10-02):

# Changelog

All notable changes to PICOTTY. This project adheres to [Semantic Versioning](https://semver.org).

## v1.2.1 — 2026-10-02

Docs/packaging only — no code or firmware changes.

### Added

- **Explainer site + GitHub Pages.** A standalone landing page under `site/`
  (teletype/phosphor themes, topology diagram, feature grid, PyPI section, quick
  start, docs map), deployed to <https://morpheuslord.github.io/PICOTTY/> by a new
  `pages.yml` GitHub Actions workflow on changes to `site/`.

### Changed

- **Project URLs.** The `picotty` `Homepage` and `Documentation` links now point at
  the published GitHub Pages site instead of the GitHub repo tree.

## v1.2.0 — 2026-09-06

Building on 1.1.0's dual-hub work: **OTA** gains firmware-only / settings-only
pushes plus a big speed-up, and the **Telegram bot** becomes button-driven.

### Added — OTA firmware-only / settings-only + faster, more resilient pushes

- **Scoped pushes.** An OTA push now takes a **scope**: `all` (default),
  `firmware` (everything *except* `settings.toml` — update the code, keep each
  node's existing config) or `settings` (only `settings.toml` — change config,
  keep the code). Exposed in the dashboard's Update-firmware sheet, on
  `POST /api/nodes/{id}/ota` and `/api/bulk/ota` (`scope`), and in the OTA manager.
  Works with existing nodes — the node writes exactly the files the hub sends, so
  no firmware change is needed. (Tip: a `settings`-only push is how you retune a
  board's `HUB_FAILOVER_TRIES`/timings without reflashing code.)
- **~8× faster.** The OTA chunk size went from 512 B to 4096 B (still well under
  the node's 16 KB frame cap), cutting round-trips.
- **Resilient transfer.** A transient link drop mid-transfer now retries the whole
  transfer (safe — `ota_begin` re-wipes staging and nothing is swapped until
  commit) instead of failing the push; commit is still one-shot, checksum-verified,
  with `.bak`/watchdog auto-revert.

### Added — Telegram button UI (picotty-telegram 1.3.0)

The bot is now **tap-driven**, not type-driven. **`/menu`** (and `/start`) opens an
inline-keyboard home screen — Status, Nodes, Telemetry, Events, Fleet, Alerts,
Source hub, Arm — and everything drills down by tapping:

- **Nodes → node detail** with action buttons: Ping, Read, Telemetry, Log, Mute,
  and (when armed) Shell, Reboot (confirm step), SysRq (key picker), Move hub.
- **Fleet** → Macros / Runbooks as buttons, then a "run on ALL online / this node"
  target picker.
- **Source hub** switch and per-node hub steering are button flows too.
- **Arm** by tapping 🔒 then sending your TOTP code (no `/arm` needed).
- **Context memory**: the bot remembers your selected node and the pending prompt,
  so buttons act without re-typing ids; the home screen shows live hub/online/armed
  status. Every typed command still works.

### Changed — clearer hub-switch controls

The dashboard's dual-hub control is now a prominent **⤓ Take over** button when a
board is live on a peer hub, alongside a clearly-labelled **⇄ Switch hub** control
(it was previously just an unlabelled "Hub" button).

### Fixed — Magic SysRq chord

The **Alt+SysRq+B** quick-chord (and any custom chord naming SysRq) was sent as a
plain HID chord, which failed on the node with `unknown keycode: 'SYSRQ'` (SysRq is
the PrintScreen key, and it must be held while the command key is tapped). Such
chords now route to the dedicated `/sysrq` command, which does the correct timing.
Also fixed `HubClient.sysrq()` sending the key under the wrong field (`command`
instead of `key`), so a Telegram `/sysrq <node> <key>` no longer silently defaulted
to `b` (reboot).

### Verified

Hub 7/7 db + **61/61** integration (incl. OTA firmware/settings scope + empty→422);
sidecar **28/28** unit (incl. the button-menu callback scheme) + wiring smoke; no
regressions.

## v1.1.0 — 2026-08-22

A board can now be served by **two hubs** with automatic failover and runtime
source-selection, and the **Telegram bot** gains a much larger command surface.

### Added — dual-hub failover

Give a node a **primary** and a **backup** hub. It prefers the primary, fails over
to the backup when the primary is unreachable, and **either hub can drive the
board** — so a dead main hub no longer means losing the fleet. See
[docs/dual-hub.md](docs/dual-hub.md).

- **Independent peers.** The two hubs run independently, each with its own SQLite
  DB; they share only the **node token**. Failover moves the live control
  connection, not the data — a board holds exactly one connection at a time, so no
  split-brain and no cross-hub coordination. Per-hub data (queue, recordings, OTA
  jobs, history) stays on the hub that recorded it.
- **Node config** ([settings.toml](firmware/circuitpython/settings.toml.example)):
  `HUB_IP_BACKUP`/`HUB_PORT_BACKUP`, display labels `HUB_LABEL`/`HUB_LABEL_BACKUP`,
  `HUB_FAILBACK` (`sticky` default / `preemptive`), `HUB_FAILOVER_TRIES`. Absent
  backup = today's single-hub behavior, fully backward compatible. The failover
  state machine lives in a new, host-testable
  [`hubselect.py`](firmware/circuitpython/hubselect.py).
- **Runtime steering.** Each hub advertises its identity to a board on connect (a
  `welcome` frame carrying the new `HUB_ID`), so the board knows **which hub it's
  talking to**. An authenticated hub can then send a directive — **switch** (move
  now), **prefer** (promote to home hub, persisted — "use my backup as my main"),
  **pin**/**unpin** — restricted to the board's configured hubs. Drive it from the
  dashboard's per-node **Hub** control, `POST /api/nodes/{id}/hub`, or Telegram.
- **Hub:** new `HUB_ID` env (default hostname), shown on the dashboard and sent in
  the welcome frame; a node's reported hub label is surfaced in the node API and on
  the dashboard (a "via &lt;label&gt;" badge). Node firmware bumped to **1.3.0**.

### Added — richer Telegram bot (picotty-telegram 1.2.0)

Surfaced hub capabilities that were REST-ready but had no chat command:

- **Read-only** (allowlist tier): `/events [n]` (recent audit), `/log <node>
  [lines]` (recent console output), `/search <text>` (search console history),
  `/ping <node>` (active RTT).
- **Fleet** (break-glass **armed** tier): `/bulk <text>` (type a line into every
  online node), `/macros` + `/runmacro <id> [node ...]`, `/runbooks` + `/runbook
  <id> <node ...|all|group:NAME>`.
- **Dual-hub:** `/hubs` (which hub each board is on) and `/hub <node>
  <switch|prefer|pin|unpin> [target]` (armed).
- New `picotty.client` SDK methods back these (`node_output`, `output_search`,
  `ping`, `bulk_cmd`, `macros`/`run_macro`, `runbooks`/`run_runbook`,
  `hub_directive`), so any client — not just the bot — can use them.

### Added — cross-hub takeover & peer visibility

A board holds one hub connection at a time, so only the hub that holds it can
steer it. New **`HUB_PEERS`** (comma-separated peer hub URLs) closes the gap:

- **Peer visibility.** Each hub polls its peers' rosters and shows a board that's
  live on the other hub as **"active on `<peer>`"** (a badge) instead of offline —
  even a board it has never seen.
- **On-demand takeover from either hub.** Steering a board the hub doesn't hold
  **relays** the directive to the peer that does, which delivers it — so you can
  pull a board to the backup from the backup's own dashboard while it's still on
  the primary. Relayed calls are never relayed again (loop-safe). Peer calls
  assume a trusted management VLAN (no auth), matching the node-token posture.

### Added — Telegram sidecar dual-hub

- **The bot fails over between hubs.** Set `HUB_BASE_URL_BACKUP` and the sidecar
  prefers the primary hub, failing over to the backup (REST + the live event
  stream) so the phone control plane survives a hub outage.
- **`/source [primary|backup]`** picks which hub the bot acts on (distinct from
  `/hub`, which steers an individual board). Telegram permits only one active
  receiver per token, so the intended HA is: run the same bot on both hosts with
  one enabled and the other a hot spare — see [docs/dual-hub.md](docs/dual-hub.md).

### Fixed — responsive dashboard

The dashboard (a fixed-width desktop layout) now adapts to phones, tablets, and
any window aspect ratio: the side rails are fluid on desktop and the three columns
stack with the console kept usably tall on narrow screens, with the page scrolling
instead of clipping. The node header is a vertical stack (info above a wrapping
action toolbar) so the info no longer collapses under the buttons.

### Verified

Firmware selector **12/12** host unit; hub 7/7 db + **58/58** integration (welcome
frame, hub-label, directive endpoint) + **5/5** two-hub relay (cross-hub takeover,
peer visibility, loop guard); sidecar **27/27** unit (hub-failover + source select)
+ wiring smoke + **18/18** end-to-end through `picotty.client`. No regressions.

## v1.0.3 — 2026-08-12

A reliability pass on node presence: nodes no longer get stuck showing offline
while alive, both ends recover from a dropped link on their own, and the
dashboard now surfaces link quality and node activity so a degrading node is
visible before it drops.

### Added — link telemetry & activity monitoring

Precautionary observability so a degrading node is visible before it drops:

- **Network telemetry.** The hub's per-node ping now feeds a rolling window that
  yields **RTT avg/min/max, jitter** (mean variation between consecutive pings),
  and **packet loss %**. Surfaced per node in the API and dashboard, with a
  live `node_net` event and a colour-coded **link quality** badge (good/fair/poor).
- **Activity / uptime.** Nodes report firmware **uptime** in the heartbeat; the
  hub shows it and raises a `node_down` event when it jumps backwards (an
  unannounced reboot). The hub also counts **reconnects** per node this run, so a
  flapping link is obvious even while the node reads "online".

### Fixed — nodes falsely shown offline (stuck-offline / reconnection)

A node that was alive and networked could show **offline** in the dashboard
indefinitely, only recovering when the hub was restarted (no node restart
needed). Root cause: when the hub's liveness sweep flipped a stale node offline
it removed it from the registry **without closing the socket**, so the still-open
connection kept delivering the node's frames onto a detached state — the node
never re-registered. Hardened both sides of the link:

- **Hub — sweep now tears down the socket.** `mark_offline` closes the node's
  writer, forcing a reconnect instead of a lingering half-open connection.
- **Hub — TCP keepalive** on accepted node sockets, a kernel-level backstop for a
  peer that vanished without a FIN.
- **Hub — node keepalive pinger** (`HUB_NODE_PING_INTERVAL_MS`, default 5s): the
  hub→node half of the heartbeat, so an idle node keeps receiving traffic and a
  silent node is swept promptly.
- **Node — dead-hub detection** (`HUB_TIMEOUT_MS`, default 20s): reconnect if no
  frame arrives from the hub within the window, catching a half-open socket where
  the node's own sends still buffer locally.
- **Node — bounded send** (`SEND_MAX_WAIT_MS`, default 2s): a wedged TX buffer now
  reconnects instead of spinning until the watchdog resets the whole node.
- **Node — DHCP re-acquire** (`REBIND_AFTER_FAILURES`, default 5): after repeated
  connects that never reached the hub, re-init the interface to pull a fresh
  lease — recovers a node that powered up before its DHCP server (site power cut)
  or whose lease went bad.

Node firmware bumped to **1.2.0**. The node pinger and dead-hub timeout are a
matched pair: run the updated hub alongside 1.2.0 firmware (or set
`HUB_TIMEOUT_MS = 0` to pair 1.2.0 nodes with an older, non-pinging hub).

### Telegram sidecar — `/telemetry` (picotty-telegram 1.1.0)

- **`/telemetry`** surfaces the new link telemetry over chat: bare, it prints a
  per-node roster (rtt avg, jitter, loss %, a good/fair/poor quality rating, and
  reconnect count); `/telemetry <node>` gives that node's detail plus firmware
  uptime. Requires a hub on **1.0.3+** (the fields it reads); the sidecar's
  `picotty` floor is bumped accordingly.

## v1.0.2 — 2026-08-05

First packaged release. (Versions 1.0.0 and 1.0.1 were burned on PyPI by the
file-name-reuse policy after deleted test uploads; 1.0.2 is the first published
version.) PICOTTY is a star-topology **networked serial console with
USB-HID keyboard injection** for a fleet of headless machines: each Raspberry Pi
Pico node plugs into a target's USB port and becomes a keyboard **and** a serial
console reader, and one Pi Zero 2 W hub coordinates the swarm through a single
browser dashboard over your management network. Built for homelab mini-PCs that
ship with **no BMC/IPMI and no accessible serial port** — this is the lights-out
management they never came with.

This release turns the repo-clone deployment into an installable, versioned
distribution and adds a phone control plane.

### Highlights

- **`picotty` Python package (uv)** — `uv tool install picotty` brings up the hub;
  three import surfaces (`picotty.hub`, `picotty.client`, `picotty.protocol`).
- **Interactive serial write** — a real terminal (xterm.js) in the browser, typing
  straight into the target's serial getty, alongside HID keyboard injection.
- **Telegram bot sidecar** — stats, push alerts, and a break-glass terminal on your
  phone, configured entirely from the dashboard.
- **OTA firmware updates** — chunked, checksummed, `.zip`-upload bundles with canary
  rollout and watchdog-revert.
- **Automation** — a wait-for-output expect engine, YAML runbooks, and an offline
  command queue.

### The hub — the `picotty` package

- Repackaged as the **`picotty`** distribution built with the `uv_build` backend
  from a `src/` layout, with a committed `uv.lock` for reproducible installs.
- **Three import surfaces:**
  - `picotty.hub` — the server (registry + SQLite + `:9000` TCP + FastAPI dashboard); needs the `[hub]` extra.
  - `picotty.client` — the SDK: `HubClient` (async REST) + `HubEvents` (WebSocket async-iterator); lean base install (httpx + websockets).
  - `picotty.protocol` — the wire protocol: framing, validation, `PROTOCOL_VERSION`.
- **Console entry points:** `picotty-hub` (the server) and `picotty-sim` (the node
  simulator — a fake node for demos/tests, no hardware).
- **Lean-by-default install** with extras: `[hub]` pulls FastAPI/uvicorn/aiosqlite/
  pydantic/pyyaml; `[telegram]` pulls the sidecar deps. A Pi running only the
  sidecar never installs FastAPI.
- **Runtime state out of the tree** — SQLite defaults to `~/.local/share/picotty/`
  (a systemd `StateDirectory` gets `/var/lib/picotty`); the dashboard's static
  assets ship inside the wheel (`importlib.resources`).

### Node firmware (CircuitPython, RP2040)

- One node per target: reads the target's serial console back over the network and
  types keystrokes (BIOS, GRUB, initramfs, the OS) as a USB HID keyboard.
- LED status codes, opt-in `/error.txt`, and a REPL debug path keep a monitorless
  node diagnosable; a hardware watchdog recovers a hung loop.
- Per-node keyboard layouts, target-machine liveness reporting, and a `serial_tx`
  capability that gates the interactive write path.

### Dashboard (Swarm Control)

- Rebuilt around a real terminal renderer with an **HID ⇄ Serial** input toggle,
  per-node **prompt-state** badges, and a **machine up/dead** liveness badge (is the
  *target* alive, not just the node).
- **Reboot-machine menu** with three methods (serial `reboot`, Ctrl+Alt+Del, Magic
  SysRq `Alt+SysRq+B`), **custom quick chords**, macros, and bulk/fleet actions.
- Author, view, **and edit** YAML runbooks in the browser; event history and audit;
  hover hints on every control with a docs "?" deep-link, plus an in-app help page.

### Automation

- **Expect engine** — wait-for-output flows with per-step regex + timeouts.
- **YAML runbooks** — expect flows run across a node group.
- **Offline command queue** — commands queued for an offline node deliver on
  reconnect (once, guarded against double-delivery).

### OTA firmware updates

- Push firmware over the wire: chunked transfer, **SHA-256 verify**, staged writes
  with a `.bak` backup and a `/ota_pending.json` marker, **watchdog-revert** in
  `boot.py`, and finalize-when-healthy.
- Upload a firmware **`.zip`** the hub decompresses into a bundle; **canary rollout**
  with per-node provenance (`last_ota`).

### Operations

- **Raw serial bridge** — expose an assigned node's serial as a TCP port for
  `minicom`/PuTTY.
- **Alerting** — outbound webhook / **ntfy** on node down, watchdog recovery, and
  command failures, with dedup.
- **Session recording** — asciicast capture and in-browser replay.

### Telegram bot sidecar (new)

- A **separate process** that reaches the hub only via REST + `/ws` and bridges it to
  Telegram over **outbound-only** long polling (no inbound port) — usable from an
  isolated management VLAN. Depends on `picotty[telegram]`, imports `picotty.client`.
- **Three tiers:** stats (`/status` `/nodes` `/uptime`), push alerts (node down/up,
  watchdog, failed, hub-restart; `/mute`), and a terminal bridge (`/shell` + control
  keys, `/reboot`, `/sysrq`) gated behind a chat-ID allowlist **+ break-glass TOTP
  arming** with auto-disarm and idle-close.
- **Dashboard setup** — Settings → Telegram card validates the bot token via
  Telegram `getMe`, generates a TOTP secret, and one-click **Install / start
  sidecar**. The hub and sidecar share one credentials file
  (`~/.config/picotty/telegram.env`, chmod 600) that the sidecar **hot-reloads**.

### Packaging & release

- `uv sync` / `uv run` dev workflow; `uv build` produces the wheel + sdist.
- **GitHub-Release-triggered publish** to PyPI via Trusted Publishing (OIDC, no
  token) — publishing a release builds and uploads the distributions.
- CI runs the hub (`test_db`, `test_integration`) and sidecar (unit, smoke) suites;
  workflows use least-privilege permissions.

### Tooling

- **`tools/package_tester.py`** — a live-hub smoke test to run on the hub host after
  install: exercises REST + WebSocket + a node round-trip end to end.

### Docs

New/updated: [packaging.md](docs/packaging.md), [telegram.md](docs/telegram.md),
plus architecture, hardware, deployment, firmware, operations, automation, and ota.

### Install

```bash
uv tool install picotty        # picotty-hub + picotty-sim on PATH
picotty-hub                    # dashboard at http://<hub-ip>:8080
```

From a source checkout: `bash hub/scripts/install.sh` (uv) then
`bash hub/scripts/install-service.sh`.

### Notes & known limitations

- **Serial console, not a KVM** — no video capture; reading output requires the
  target to have a serial console configured.
- Run the hub under **one** uvicorn worker (the single event loop is the design).
- The **CircuitPython node library** (installable `.mpy` bundles + circup) is
  scaffolded and documented ([node/README.md](node/README.md)) but **deferred**;
  the authoritative firmware today is `firmware/circuitpython/`.
- The management network is **not** an authenticator — the node token applies on
  every connection; auth on the dashboard is optional and off by default (assumes an
  isolated VLAN reached over VPN/tunnel).

### Verified

Hub wheel builds clean; 7/7 db + 44/44 integration checks; sidecar 14/14 unit +
wiring smoke + 9/9 end-to-end against a real hub through `picotty.client`; live
`tools/package_tester.py` green on a Pi Zero 2 W.

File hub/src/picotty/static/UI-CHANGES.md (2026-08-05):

# Dashboard UI changes

All work is confined to `hub/src/picotty/static/`. Additive and non-breaking: every existing
flow (HID/serial composer, macros, events, settings, DEMO mode) is unchanged.
Verified with `node --check hub/src/picotty/static/app.js`.

Files touched: `app.js`, `index.html`, `styles`/`app.css` (no CSS change needed),
plus new `vendor/fetch-vendor.sh`, `vendor/README.md`, this file.

## Phase 1 — Layout display (read-only)
- `renderHeaderInto`: node detail header now shows `kbd: <layout>` from the node's
  `layout` field.
- Carried into the client node record in `apiNodeToRec` and `mergeMeta`
  (`layout`, default `"us"`).

## Phase 2 — Serial composer polish (verify)
- Verified `buildSerialComposer` already provides Enter (CR `\r`=0d), Backspace
  (`7f`), Tab (`\t`=09), Esc (`1b`), Ctrl-C (`03`), Ctrl-D (`04`), Ctrl-Z (`1a`),
  the HID⇄Serial `buildModeRow` toggle gated on `serial_tx`, debounced key
  streaming and paste. No gaps found; left unchanged.

## Phase 3 — xterm.js console (progressive enhancement)
- New helpers: `xtermAvailable`, `xtermActive`, `setupXterm`, `disposeXterm`,
  `xtermReplay`, `xtermMeta`, `mountConsole`, `refreshConsole`.
- `buildCenter` mounts an xterm `Terminal` + fit addon into `ui.xtermHost` **only
  when `window.Terminal` exists**; otherwise the original DOM-log `ui.term`
  surface is used unchanged.
- `pushOutput` writes raw bytes to `term.write(...)` when active (DOM-log path
  otherwise); `pushLine` mirrors sys/in/err lines into xterm with ANSI prefixes.
- Serial mode wires `term.onData(d => postSend(id,{data:d}))`; HID mode leaves the
  terminal read-only.
- `renderView` disposes the terminal before clearing; a window `resize` listener
  refits. `selectNode`/`backfillNode`/`clearConsole` now call `refreshConsole`.
- `index.html` adds guarded `vendor/xterm.css`, `vendor/xterm.js`,
  `vendor/xterm-addon-fit.js` (404 harmless until vendored).

## Phase 4 — Prompt-state badge
- New `promptBadge()` + `PROMPT_BADGE` palette (panic=red, shell=green,
  login/password=amber, grub/booting=blue, null=none).
- Rendered per row in `renderNodeList` and (larger) in the detail header.
- `onEvent` handles `node_state` → updates `n.promptState` and re-renders.
- Carried in `apiNodeToRec`/`mergeMeta`; demo nodes seeded with states.

## Phase 5 — Expect builder + live progress
- `openExpectBuilder(nodeId)` modal: ordered steps mixing **send** actions,
  **wait-for** rows (regex + timeout_ms + on_timeout fail|continue) and **delay**
  rows; reorder/remove; `POST /nodes/{id}/expect {steps:[...]}`.
- `ui.expectBar` + `renderExpectBar` shows a live progress strip (step/total,
  phase, detail) under the console with Cancel/Dismiss.
- `onEvent` handles `expect_progress`; `cancelExpect` → `POST …/expect/{job}/cancel`.
- Opened from a new **Expect** button in the header actions.

## Phase 6 — Offline queue
- `openQueueSheet(nodeId)`: lists pending (`GET /nodes/{id}/queue`), adds a
  type-command with TTL (`POST …/queue {command,ttl_ms}`), cancels
  (`DELETE …/queue/{qid}`). New **Queue** header button.

## Phase 7 — Session replay
- `openReplay(nodeId)`: if `window.AsciinemaPlayer` is vendored, plays
  `/api/nodes/{id}/session.cast` inline; otherwise offers a `.cast` download link
  + `asciinema play` hint. New **Replay** header button; guarded
  `vendor/asciinema-player.*` in `index.html`.

## Phase 8 — Serial bridge info
- Header meta shows `serial bridge: <bind>:<port>` when assigned.
- `openBridgeSheet(nodeId)`: assign/unassign (`POST/DELETE /nodes/{id}/bridge?port=N`)
  with a `minicom -D tcp:<hub>:<port>` hint. New **Bridge** header button.
- `refreshBridge()` + `state.bridge` loaded in `loadLive`.
- Settings gains a `serial_bridge_enabled` toggle.

## Phase 9 — Runbooks view
- New nav entry **Runbooks** (between Macros and Events) + router case.
- `buildRunbooksView`: list, YAML `<textarea>` editor (`openRunbookEditor`,
  create/patch/delete), run modal (`openRunbookRun` → `POST /runbooks/{id}/run`
  with node_ids or group + stagger_ms), and a live runs pane.
- `onEvent` handles `runbook_progress`; `refreshRunbooks` + `state.runbooks`
  loaded in `loadLive`. Placeholder YAML matches the spec.

## Phase 11 — Alerts settings
- Settings adds `alerts_enabled` toggle and `alerts_webhook_url` /
  `alerts_ntfy_url` text inputs → `PATCH /settings`.

## Phase 12 — OTA firmware updates
- `nodeHasOta(n)` mirrors `nodeHasSerialTx` (checks the node's `caps` for `ota`).
  A **Firmware** button appears in the node header only for ota-capable nodes.
- **Per-node update** (`openOtaSheet`): pick a bundle (radio list from
  `state.bundles`), `POST /nodes/{id}/ota`, and watch live progress. Progress is
  driven by the `ota_progress` WS event (handled in `onEvent`, mirrored into
  `state.otaJobs[nodeId]`) with `pollOta` polling `GET /nodes/{id}/ota/{job_id}`
  as a backup. Terminal states are shown clearly: **healthy** (green success),
  **failed** and **unconfirmed** (red).
- A compact live **OTA bar** (`renderOtaBar` → `ui.otaBar`) sits beside the expect
  bar in the console view: bundle name, byte progress bar (`sent/total`), phase/
  status text, and a Dismiss button on terminal states.
- **Bundle manager + rollout** (`openBundleManager`, reached via the sheet's
  "Manage bundles…"): create a bundle from a name + `<input type=file multiple>`
  (files read with `FileReader` as base64, prefix stripped, `POST /ota/bundles`);
  list existing bundles with their files + short sha; and a **canary rollout**
  control (pick ota-capable nodes or a group + stagger → `POST /bulk/ota`) with a
  note to follow each node's progress bar.
- `state.bundles` / `state.otaJobs` added; bundles loaded in `loadLive`
  (`GET /ota/bundles`) and `applyDemo`. `refreshBundles` re-fetches after create.
- DEMO: demo nodes gain the `ota` cap, a demo `fw-1.1.0` bundle is seeded, and
  `runOtaDemo` simulates a byte-streamed flash → committing → reboot → healthy so
  the whole OTA UI (including rollout) is exercisable offline.

## DEMO mode
- Demo nodes carry `layout`/`promptState`; a demo runbook and empty bridge added.
- Expect / queue / bridge / runbook actions have demo simulations so the UI is
  never blank and every affordance is exercisable offline.

## Operator step (vendoring — optional)
The xterm and asciinema libs are **not** committed and **not** fetched at runtime
(hub is on an isolated VLAN). To enable the enhanced console + inline replay:

```sh
cd hub/src/picotty/static/vendor && sh fetch-vendor.sh   # on a networked machine
# then copy hub/src/picotty/static/vendor/ onto the hub
```

Until then the tags 404 harmlessly and the UI falls back to the existing DOM-log
renderer and a `.cast` download link. See `vendor/README.md`.

## Help system — in-app docs + tooltips + `?` deep-links
Additive and non-breaking; DEMO mode still works. `node --check hub/src/picotty/static/app.js`
passes and `help.html` is balanced HTML.

Files touched: `app.js`, `index.html` (unchanged — help is reachable directly at
`/help.html`), and a NEW self-contained `help.html`.

### New page — `hub/src/picotty/static/help.html`
- A single, self-contained docs page. Links `styles.css` for the shared palette
  (CSS custom properties), then an inline `<style>` for a sticky left TOC/sidebar
  + scrollable content column. Responsive (sidebar collapses under 820px). No CDN
  / no external assets — everything inline or same-origin (isolated VLAN).
- Top "← Back to dashboard" link (`/`) in the sidebar and again at the foot of the
  Security section; a grouped table of contents jumps to every section.
- One `<section id="…">` per feature, each with prose adapted from `docs/*.md`
  (operations, automation, ota, firmware, considerations) plus the real REST
  endpoint(s) from `hub/src/picotty/hub/api/rest.py`, gotchas and safety notes. Addresses and
  secrets are placeholders (`<hub-host>`, `<password>`, `<your-endpoint>`).
- **Stable anchor ids:** `overview`, `nodes`, `console`, `input-modes`,
  `control-bytes`, `keyboard-layout`, `ping-read-reboot`, `prompt-state`,
  `macros`, `sequences`, `expect`, `offline-queue`, `runbooks`, `bulk`,
  `session-recording`, `serial-bridge`, `ota`, `alerts`, `settings`, `events`,
  `security` (21 sections).

### `app.js` — shared helper
- New `helpLink(anchor, label, opts)` returns a small circular muted "?" `<a>`
  (`href="help.html#<anchor>"`, `target="_blank"`, `rel="noopener"`,
  `var(--color-neutral-600)`, ~15px, `cursor:help`). It `stopPropagation()`s so it
  never triggers the control it sits beside, and seeds its own hover tooltip.
  Reused everywhere (27 call sites).

### `app.js` — where the `?` links land (group- + key-button-level)
- **Top nav:** a new **Help** entry (after Settings) opens `help.html` in a new
  tab, with a trailing "?" glyph.
- **Panel/section headers:** Nodes rail, Serial console toolbar, right-rail
  history/events tabs, Macros header, Runbooks header, Events header, Settings
  header + Safety + Alert-endpoints sub-headers, and the composer's Input row.
- **Feature buttons in the node detail header:** Ping/Read/Reboot, Expect, Queue,
  Replay, Bridge, and Firmware (OTA) each get an adjacent anchor-specific "?".
- **Composer rows:** HID Keys/Chords and the Serial control-byte row link to
  `#control-bytes`; the Macros row links to `#macros`.
- **Modal sheets:** Expect, Queue, Bridge, OTA update + rollout bodies carry an
  inline "?" to their section.

### `app.js` — tooltips (`title=`) on every interactive control
- ~60 controls now carry a concise `title`: nav links + rail toggles + WS pill;
  node-list filter/status radios and each node row; console toolbar
  (autoscroll/wrap/clear/download); all detail-header actions (with caveats, e.g.
  "Reboot the Pico node (NOT the target machine)"); HID keys (per-key intent),
  chords (incl. ⚠ for CTRL+ALT+DEL and ALT+SysRq+B), append-⏎ and char-delay,
  macro chips; Serial field + each control byte (with hex); macro/runbook
  Run/Edit/Delete/New/Save; Events Export CSV; Settings Save; and the sheet
  primary actions (Run expect, Queue, Assign/Reassign/Unassign bridge, Update
  firmware, Create bundle, Start rollout, Run runbook).

## Phase 13 — Custom tooltip system (redesign)

Replaces BOTH the native `title=""` box and the standalone circular "?" `helpLink`
icon with one polished, custom-styled hover tooltip. The docs "?" now lives
**inside** the tooltip box, not as a separate icon beside each control.

### `app.js` — the singleton + delegation
- Removed `helpLink(anchor, label, opts)` entirely (all 26 call sites migrated).
- New `tip(text, anchor)` returns an attrs fragment
  `{ "data-tip": text, "data-tip-help": anchor }` to spread into `h(tag, {…})`;
  `withTip(node, text, anchor)` stamps the dataset onto an existing node.
  `kicker(label, tipText?, anchor?)` gained optional tooltip args.
- A single `<div class="sc-tooltip">` is appended to `<body>` (built with `h()` /
  `textContent`, never innerHTML). It holds a `.sc-tip-text` body and a
  `.sc-tip-foot` footer with a "Learn more" label + a circular accent **"?"**
  `<a href="help.html#<anchor>" target="_blank" rel="noopener">` — the docs link,
  now *inside* the box.
- `installTooltips()` (called once in `boot`) wires **delegated** listeners on
  `document` (`mouseover`/`mouseout`/`focusin`/`focusout`) that read
  `closest('[data-tip]')` — no per-element listeners. `keydown` Escape and a
  capture-phase `scroll` hide it.
- **Hover-intent:** leaving the trigger delays hide by 180ms; the tooltip's own
  `mouseenter` cancels the hide and `mouseleave` resumes it, so the "?" stays
  clickable. `mouseout` doesn't hide when moving onto the tooltip.
- **Positioning:** `getBoundingClientRect` + window bounds — below by default,
  flips above when it would overflow, centred on the trigger and clamped
  horizontally on-screen. Shows on keyboard focus for a11y.

### `app.js` — migration
- **~68 controls** converted from `title="…"` to `data-tip` (mechanical
  `title:` → `"data-tip":`), keeping the same text + caveats ("Reboot the Pico
  node (NOT the target machine)", serial control bytes with hex, dangerous chords
  flagged ⚠, "Serial mode: keystrokes stream to the target's getty", …).
- **26 `helpLink(…)` icons removed**; the docs anchor now rides *inside* the
  tooltip via `data-tip-help` — folded onto the relevant control/header:
  detail-header actions (ping-read-reboot / expect / offline-queue /
  session-recording / serial-bridge / ota), section headers (Nodes, Serial
  console, Macros, Events, Settings + Safety + Alert endpoints, Runbooks,
  right-rail tabs), composer rows (Input→input-modes, Keys/Chords/Serial→
  control-bytes, Macros→macros), and sheet bodies (Expect, Queue, Bridge, OTA,
  canary rollout).
- `promptBadge` → `data-tip` + `data-tip-help="prompt-state"`; `targetBadge`
  (up/dead/unknown) → `data-tip` + `data-tip-help="target-liveness"`.

### `app.css` — styling (light + dark aware)
- `.sc-tooltip`: `position:fixed`, dark ink (`#26241f`, matches the serial
  terminal), `max-width:320px`, ~9–11px padding, 13px text, rounded 8px, subtle
  border + layered shadow, `z-index:3000`, opacity/transform fade.
- `.sc-tip-foot` / `.sc-tip-learn` / `.sc-tip-help` (accent circular "?" pill
  with hover/focus states). `@media (prefers-color-scheme: dark)` and
  `:root[data-theme=…]` overrides lift the box off a dark backdrop.

### `help.html` — new section
- Added `#target-liveness` ("Machine up/dead badge") documenting the up / dead /
  unknown target signal (node powered by target; USB host enumerated or recent
  serial output = up; host gone but node alive = dead; can't tell = unknown), plus
  a TOC entry under "Driving a target". The machine badge's tooltip "?" points at
  it.

Verified: `node --check hub/src/picotty/static/app.js` passes; help.html tag balance checked
(section/table/div/main/nav all matched); every `data-tip-help` anchor resolves to
a real id in help.html.

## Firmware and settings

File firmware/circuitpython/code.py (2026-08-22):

# code.py — the node's main program.
#
# One cooperative loop, no threads. It brings up Ethernet once, then repeatedly
# dials the hub and runs a session: read hub frames and act on them, forward the
# target's serial output, and send a heartbeat on interval. On any link error it
# closes the socket, backs off, and reconnects. A hardware watchdog resets the
# node if the loop ever hangs.
#
# Hardened firmware built against the current CircuitPython and
# adafruit_wiznet5k / adafruit_hid APIs.

import gc
import time

import board
import digitalio
import supervisor

from nodeconfig import NodeConfig, ConfigError
from netlink import NetLink
from backchannel import BackChannel
from injector import Injector, InjectError
from wire import FrameReader, ProtocolError, encode
from hubselect import HubSelector
import messages

FW_VERSION = "1.3.0"

# Editing files on the CIRCUITPY drive must not yank a running node into a reload
# mid-command. We reload deliberately (on a reboot command), never by surprise.
supervisor.runtime.autoreload = False


def mono_ms():
    """Milliseconds since boot from the integer-ns clock (no float precision loss)."""
    return time.monotonic_ns() // 1_000_000


def decode_hex(s):
    """Decode a hex string like '030d' to bytes. Raises ValueError on bad input.

    Used by the `send` command's `raw` field (binary bytes travel as hex so the
    wire stays UTF-8 JSON). No bytes.fromhex on all CircuitPython builds, so this
    stays explicit and dependency-free."""
    if not isinstance(s, str):
        raise ValueError("raw must be a string")
    s = s.strip()
    if len(s) % 2 != 0:
        raise ValueError("odd-length hex")
    return bytes(int(s[i:i + 2], 16) for i in range(0, len(s), 2))


def log_error(msg):
    """Append a line to /error.txt so a headless node's fault is readable by just
    plugging it into a computer. A no-op unless LOG_TO_FILE is enabled in
    settings.toml (which makes boot.py remount the filesystem writable), so this
    is always safe to call. The file self-truncates past ~32 KB."""
    try:
        import os
        try:
            size = os.stat("/error.txt")[6]
        except OSError:
            size = 0
        with open("/error.txt", "w" if size > 32768 else "a") as f:
            f.write("[+%dms] %s\n" % (mono_ms(), msg))
    except OSError:
        pass  # filesystem read-only (logging disabled) — nothing to do


class State:
    """The small amount of runtime state the hub can change while connected."""

    def __init__(self, heartbeat_ms):
        self.heartbeat_ms = heartbeat_ms


# --- status LED (the headless debug channel) ---------------------------------

class StatusLED:
    """The onboard LED as an at-a-glance status indicator for a node with no
    console. Read the node by looking at it:

      solid on      connected to the hub, healthy
      slow blink    powered + networked, but not connected to the hub (retrying)
      medium blink  Ethernet/link problem (cannot bring the network up)
      fast blink    fatal config or HID error (needs attention)
    """

    _PERIOD_MS = {"online": None, "connecting": 500, "netdown": 200, "fatal": 100}

    def __init__(self):
        self._led = None
        try:
            self._led = digitalio.DigitalInOut(board.LED)
            self._led.direction = digitalio.Direction.OUTPUT
        except Exception:
            self._led = None  # some boards differ (e.g. Pico W); degrade silently
        self._state = "connecting"

    def set(self, state):
        self._state = state

    def tick(self, now_ms):
        if self._led is None:
            return
        period = self._PERIOD_MS.get(self._state)
        self._led.value = True if period is None else ((now_ms // period) % 2 == 0)


STATUS = None  # set in main(); referenced by feed() so every loop updates the LED


def host_present():
    """True if the TARGET's USB host has enumerated us — a proxy for 'the machine
    is powered and running'. False when the node is still powered (e.g. the target
    supplies USB standby 5V) but the target itself is off or hung, which is how a
    node reports a DEAD machine while it is still alive to the hub. Returns None if
    the runtime doesn't expose it."""
    try:
        return bool(supervisor.runtime.usb_connected)
    except Exception:
        return None


def was_watchdog_reset():
    """True if this boot followed a watchdog reset (i.e. the loop hung last time)."""
    try:
        import microcontroller
        return microcontroller.cpu.reset_reason == microcontroller.ResetReason.WATCHDOG
    except Exception:
        return False


# --- watchdog ----------------------------------------------------------------

def setup_watchdog(cfg):
    if not cfg.watchdog_enabled:
        return None
    try:
        import microcontroller
        from watchdog import WatchDogMode

        wdt = microcontroller.watchdog
        if wdt is None:
            return None
        wdt.timeout = cfg.watchdog_timeout_s  # set timeout before mode
        wdt.mode = WatchDogMode.RESET
        return wdt
    except Exception as e:
        print("watchdog unavailable:", e)
        return None


def feed(wdt):
    if wdt is not None:
        wdt.feed()
    if STATUS is not None:
        STATUS.tick(mono_ms())


def sleep_feeding(seconds, wdt, net):
    """Sleep in small slices so the watchdog stays fed and the DHCP lease stays
    alive even while we are between hub connections."""
    end = time.monotonic_ns() + int(seconds * 1_000_000_000)
    while time.monotonic_ns() < end:
        feed(wdt)
        net.maintain()
        time.sleep(0.2)


def idle_forever(wdt):
    """A dead-end for unrecoverable startup errors: keep feeding the watchdog so
    the node does not reset-loop, and blink the fatal LED pattern. The error is
    also on the console for anyone who can attach one."""
    while True:
        feed(wdt)          # ticks the LED (fast/fatal blink) too
        time.sleep(0.1)


# --- HID setup ---------------------------------------------------------------
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

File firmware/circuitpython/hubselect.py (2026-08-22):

# hubselect.py — choose which hub a node dials, and fail over between them.
#
# Pure logic, no hardware imports, so it runs on plain CPython too (see
# firmware/tests/test_hubselect.py). The node holds an ordered list of hubs
# (primary first) and points cfg.hub_host/hub_port at the chosen one before each
# connect, so the transport (netlink) never changes.
#
# Failback policy:
#   * "sticky" (default): once a hub accepts us we keep dialing it across benign
#     drops; only after `failover_tries` connect failures to reach it do we
#     advance to the next candidate. A recovered primary does NOT pull us back —
#     no interruption to a live session.
#   * "preemptive": every reconnect restarts from the most-preferred hub, so a
#     recovered primary is used again on the next reconnect.
#
# A hub (dashboard today, an app tomorrow) can steer the node at runtime via a
# `hub_directive` frame handled in code.py:
#   * switch  — move to the target hub now (one-shot; preference unchanged)
#   * prefer  — make the target the preferred hub AND move now (persisted)
#   * pin     — lock to the target (ignore failover) and move now (persisted)
#   * unpin   — release a pin
# A directive's target must be one of the node's configured hubs, so a hub can
# never redirect a board to an arbitrary address.

# Where a runtime override is persisted so a promotion survives a soft reload.
# Best-effort: on a read-only filesystem (the default production posture, no OTA)
# the override simply holds for the life of the process.
HUB_PREF_PATH = "/hub_pref.json"


class HubSelector:
    def __init__(self, cfg, pref_path=HUB_PREF_PATH):
        self._cfg = cfg
        self._hubs = cfg.hubs                                  # [{label,host,port}]
        self._pref_path = pref_path
        self._by_label = {}
        for i in range(len(self._hubs)):
            self._by_label[self._hubs[i]["label"]] = i
        self._order = list(range(len(self._hubs)))            # preference (indices)
        self._cursor = 0                                       # position in _order
        self._sticky = None                                   # idx currently holding us
        self._pin = None                                      # locked idx or None
        self._pending = None                                  # idx to switch to now
        self._active = self._order[0]                         # idx last handed out
        self._fails = 0                                       # consecutive connect fails
        self._connected_id = None                             # hub_id from welcome
        self._tries = cfg.hub_failover_tries if cfg.hub_failover_tries > 0 else 1
        self._preemptive = cfg.hub_failback == "preemptive"
        self._load()

    # -- selection ------------------------------------------------------------

    def _current_idx(self):
        if self._pending is not None:
            return self._pending
        if self._pin is not None:
            return self._pin
        if not self._preemptive and self._sticky is not None:
            return self._sticky
        return self._order[self._cursor % len(self._order)]

    def next_target(self):
        """Point cfg at the hub to dial next; returns its label."""
        idx = self._current_idx()
        self._active = idx
        h = self._hubs[idx]
        self._cfg.hub_host = h["host"]
        self._cfg.hub_port = h["port"]
        return h["label"]

    @property
    def active_label(self):
        return self._hubs[self._active]["label"]

    @property
    def has_backup(self):
        return len(self._hubs) > 1

    def on_connected(self):
        """A hello just succeeded on the active hub."""
        idx = self._active
        self._fails = 0
        if self._pending == idx:
            self._pending = None
        if self._preemptive:
            self._cursor = 0            # next reconnect starts from the top again
        else:
            self._sticky = idx          # stay here until it fails
            self._cursor = self._order.index(idx)

    def on_failed(self):
        """A connect attempt to the active hub never reached it."""
        self._fails += 1
        if self._pending is not None:
            self._pending = None        # a requested switch couldn't connect; drop it
            self._fails = 0
            return
        if self._fails >= self._tries:
            self._fails = 0
            self._sticky = None
            if len(self._order) > 1:
                self._cursor = (self._cursor + 1) % len(self._order)

    # -- runtime directives ---------------------------------------------------

    def note_hub_id(self, hub_id):
        self._connected_id = hub_id

    def apply_directive(self, action, target):
        """Return True if the directive was valid/applied. Moving actions
        (switch/prefer/pin) set a pending target; the caller drops the session so
        the loop dials it."""
        if action == "unpin":
            self._pin = None
            self._persist()
            return True
        idx = self._by_label.get(target)
        if idx is None or action not in ("switch", "prefer", "pin"):
            return False
        if action == "prefer":
            self._order.remove(idx)
            self._order.insert(0, idx)
            self._cursor = 0
        elif action == "pin":
            self._pin = idx
        self._pending = idx
        if action in ("prefer", "pin"):
            self._persist()
        return True

    # -- persistence ----------------------------------------------------------

    def _persist(self):
        try:
            import json
            primary = self._hubs[self._order[0]]["label"]
            pin = self._hubs[self._pin]["label"] if self._pin is not None else None
            with open(self._pref_path, "w") as f:
                json.dump({"primary": primary, "pin": pin}, f)
        except Exception:
            pass  # read-only FS: the override just holds for this process

    def _load(self):
        try:
            import json
            with open(self._pref_path) as f:
                data = json.load(f)
        except Exception:
            return
        primary = data.get("primary")
        if primary in self._by_label:
            idx = self._by_label[primary]
            self._order.remove(idx)
            self._order.insert(0, idx)
        pin = data.get("pin")
        if pin in self._by_label:
            self._pin = self._by_label[pin]

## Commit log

2026-07-30 Fix node crash, hub query, and console rendering; add offline tests
    Firmware:
    - wire.py: fix crash on every inbound frame — CircuitPython bytearray has no
    __delitem__, so 'del buf[:n]' raised TypeError; consume by rebinding a slice.
    - build.sh: default --cp-version to 10.2.1 (was 9.2.1) so staged .mpy libs match
    the fleet's CircuitPython; avoids incompatible-library crash loops.
    - testhub.py: add offline framing checks (--framecheck) incl. a CircuitPython
    no-__delitem__ simulation that reproduces the above bug on a dev machine.
    Hub:
    - db.py: fix 'ambiguous column name: node_id' in list_commands — qualify every
    filter column with the commands alias, since the results JOIN shares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
    [wire.py]
2026-07-30 Add dashboard screenshots + macro editor UI; expand README BOM; fix mermaid edge label
    Dashboard:
    - app.js: full macro creation/edit modal — name, group, dangerous flag, and a
    step builder (type text / key-chord / wait) with reorder, remove, live preview;
    wires the previously-placeholder New macro / Add step buttons to POST/PATCH
    /macros; adds an empty-state CTA and Edit/Delete/Run actions.
    README:
    - Bill of materials: Pico or Pico 2 (RP2350) + WIZnet W5100S Ethernet HAT, with
    the W5100S-EVB-Pico all-in-one alternative; hub and fabric tables; sizing note.
    - Dashboard: five-screen Prev/Next screenshot slideshow (pictures/).
    - Fix mermaid 'suitable point for the given distance' rend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
2026-07-30 Reframe as a serial console (not KVM); move technical detail into docs/ and slim the README
    - Correct the framing throughout: PICOTTY is a networked serial console with
    keyboard injection, not a KVM (README tagline/intro/callout, CONTRIBUTING).
    - Move the deep technical detail (component roles, wire protocol, message
    journeys, data model, BOM, deployment workflow, firmware lifecycle, ops) into
    docs/ with an index; keep the README to the gist + screenshot grid + quick
    start + doc links.
    - Replace the stacked screenshot slideshow with a 2-column table grid.
2026-07-31 Add enclosure CAD (Fusion 360 source, STEP, printable STL)
    [Enclosure Body.stl, PICOTTY-ENCLOSURE.f3d, PICOTTY-ENCLOSURE.step]
2026-07-31 feat(Cad Updates): Updated cad model, still work needs to be done
    [Enclosure Body.stl, Front Side.stl, PICOTTY-ENCLOSURE.f3d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]
2026-08-01 Feat: fourth itteration case design, works really well now...
    [Enclosure Body.stl, Front Side.stl, PICOTTY-ENCLOSURE.f3d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]
2026-08-01 Show full-res dashboard shots + build photos; link enclosure STL/STEP/CAD
    - README: large click-to-full-resolution hero + grid for the dashboard
    screenshots (they were only being displayed at half width, not compressed).
    - Add hardware build photos (Ethernet HAT, Pico+HAT, assembled enclosure).
    - Link the 3D-printable enclosure files (STL/STEP/Fusion 360) in Enclosure Cad/.
2026-08-01 Render the enclosure STL in the README (spinning preview + interactive 3D viewer link)
    GitHub markdown can't embed a live 3D viewer, so: an inline turntable GIF of the
    STL (rendered from the mesh) links to an interactive web viewer that loads the raw
    STL straight from the repo, plus a note that clicking the .stl opens GitHub's own
    3D viewer. Download links for STL/STEP/Fusion 360 kept.
2026-08-01 feat: fleet automation suite — expect engine, runbooks, OTA, serial bridge, prompt-state, alerting, + more
    Implements the full eleven-phase PICOTTY improvement plan plus cross-cutting
    items. Every feature is additive and backward-compatible: the 4-byte-length JSON
    framing, the cmd_id echo contract, the unknown-message-type tolerance on both
    ends, the single-loop / single-uvicorn-worker rule, the registry-vs-SQLite split,
    and the firmware watchdog-arming-after-network sequence are all preserved. New
    firmware-dependent features are gated on a capability the node advertises in
    hello, so a mixed-firmware fleet keeps working. FW_VERSION bumped 1.0.0 -> 1.1.0.
    This lands on the `under-testing`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
    [boot.py, code.py]
2026-08-01 fix(security): address CodeQL findings — DOM-XSS sink and weak password hashing
    Two static-analysis findings from CodeQL, both fixed:
    1. Client-side XSS in the h() DOM helper (hub/static/app.js). Removed the unused
    `html` attribute branch that assigned `e.innerHTML = v` (0 call sites — a dead
    XSS escape hatch), and hardened child appending so a value is only ever added
    as a real DOM Node or an escaped text node (`kid instanceof Node ? kid :
    createTextNode(...)`). No string is ever parsed as HTML, so nothing reaching
    the helper can inject markup. The other innerHTML uses are `= ""` clears (safe).
    2. Weak hashing of a password (hub/app/utils.py). The login path hashed the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
2026-08-01 fix(wipe-pico): auto-grant serial port access with sudo chmod 666
    When the CircuitPython REPL port (e.g. /dev/ttyACM0) isn't writable by the
    current user (typically root/dialout-owned), the script now runs
    `sudo chmod 666 <dev>` to open it and re-checks, instead of only printing a hint
    and exiting. Falls back to a clear message if chmod fails (run with sudo or join
    the dialout group).
2026-08-01 docs(ota): add manual wipe-and-reflash recovery when OTA fails
    Documents the escape hatch for a write-protected OTA node whose update failed or
    that needs re-provisioning: firmware/scripts/wipe-pico.sh reaches it over the
    CircuitPython REPL, reformats to a host-writable drive, then redeploy with
    build.sh (or drag-drop). Includes the BOOTSEL/uf2 hardware fallback and notes
    that node identity lives in private/nodes/<id>/ so nothing is lost.
2026-08-01 feat(liveness): report attached-machine up/down distinctly from the node
    A node is powered by its target, so node-online alone doesn't tell you whether
    the MACHINE is actually running. The node now reports target liveness in each
    heartbeat via supervisor.runtime.usb_connected (host enumerated = machine up;
    gone = machine off/hung while the node stays powered by USB standby). The hub
    derives a per-node `target` state — up / down / unknown — corroborated by recent
    serial output (fresh output => alive regardless of the flag), and exposes it in
    merge_node and the heartbeat broadcast.
    - firmware: messages.heartbeat(host=...); host_present() reads usb_connected.
    - hub: NodeState.host_up + las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
    [code.py, messages.py]
2026-08-01 fix(dashboard): stop xterm CPR garbage; add machine up/dead badge; keep xterm
    - xterm serial input: strip the terminal's own auto-replies (cursor-position
    reports ESC[..R and device-attribute replies ESC[..c) before forwarding
    onData to the target's getty. The target queries cursor position (ESC[6n); a
    real terminal answers, and that answer was being sent back as input, landing at
    the shell as garbage like "168R" / "-bash: 168R: command not found", worst on
    tab switch (re-fit re-triggers the exchange). Real keystrokes (incl. arrow keys
    ESC[A–D) never match the filter, so typing is unaffected. xterm stays enabled.
    - machine (target) liveness badge: new targetBadge() renders the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
2026-08-01 feat: Magic SysRq machine-reboot command + custom quick-chords backend
    Reboot options for a target machine and operator-defined chords.
    - SysRq: new `sysrq` command (Alt+SysRq+<key>) — a firmware injector method that
    HOLDS Alt+SysRq while tapping the command key (default 'b' = immediate kernel
    reboot even on a hung box), which `keys` can't do since it presses+releases
    together. Wired through build_node_frame and POST /api/nodes/{id}/sysrq {key}
    (single-char validated). Requires kernel.sysrq on the target.
    - Custom chords: a new `chords` table (label + key chord, e.g. "VT2" ->
    CTRL+ALT+F2) with CRUD (GET/POST/PATCH/DELETE /api/chords), distinct from
    macros. Chord keys are norma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
    [code.py, injector.py]
2026-08-01 feat(dashboard): custom tooltip system with the docs "?" inside the hover box
    Replaces the tiny native title= tooltips and the separate standalone "?" icons
    with one styled hover tooltip that contains the docs link inside it, per request.
    - tip(text, anchor) / withTip(node,...) set data-tip / data-tip-help; a single
    delegated listener (mouseover/out/focusin/out on document, closest('[data-tip]'))
    shows a styled .sc-tooltip singleton — no per-element wiring.
    - The "?" now lives INSIDE the tooltip box (a "Learn more ?" footer linking
    help.html#anchor, new tab). Hover-intent: 180ms close delay + the tooltip's own
    mouseenter cancels it, so the "?" is reachable. Positions with viewport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
2026-08-01 fix(dashboard): restore tooltips on ALL controls; keep the styled box + inline ?
    The tooltip redesign regressed coverage: it stripped the native title= from ~60
    controls but only re-added data-tip to ~26, so most controls (the buttons you
    hover) had no tooltip at all. Rebuilt on the commit that still has title= on every
    control (68), and made the custom tooltip box READ the native title: on hover it
    adopts title -> data-tip, removes the native title (so the browser's small box
    never shows), and renders the polished box with the "?" inside it. The "?" deep-
    links to the current view's help section (or an element's data-tip-help if set).
    The standalone helpLink "?" icons are retired (helpLink(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
2026-08-01 feat(dashboard): runbook edit, reboot-machine menu, custom chords, OTA zip, rename
    Applies the five queued UI features on top of the fixed tooltip base (new controls
    use plain title=, which the custom tooltip box reads, so hover coverage stays
    complete — 86 titled controls now).
    - Rename: hero/tab title -> "PICOTTY SWARM CONTROL".
    - Runbook view/edit: inline View/Edit · Run · Delete per row (openRunbookEditor
    pulls GET /runbooks/{id} into the name+YAML editor; PATCH to save; 422 bad-YAML
    surfaced inline via a new apiSoft() helper) — edit is now attached to its row.
    - Reboot machine: a menu beside "Reboot node" (the Pico) with three confirm-gated
    methods — Serial `reboot` (send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
2026-08-01 docs: replace Assembly.jpeg with updated build photo
2026-08-01 fix(security): resolve CodeQL alerts — exception exposure + client-side XSS
    CodeQL findings on main:
    - py/stack-trace-exposure (#3, #4) in the two OTA bundle endpoints: the handlers
    returned the OTAError message (str(e)) in the HTTP body. Now the specific reason
    is written to the audit log (operator-visible in Events) and the client gets a
    static message instead — no exception text crosses the API boundary.
    - js/xss + DOM-text-reinterpreted-as-HTML (#5, #6) in app.js: the tooltip help
    link built an href from a data-tip-help attribute unsanitized. It is now
    stripped to a bare fragment id ([A-Za-z0-9_-]) before becoming href, so no
    scheme (e.g. javascript:) can be smuggled in.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
2026-08-02 feat(cad): added new side mount for 20x20 alumn extrusion frame
    [Aluminium 20x20x1000.step, Aluminium extrusion 20x20x1000.sldprt, Lab Mount Box.stl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]
2026-08-02 docs(hardware): hub needs wired Ethernet (Zero 2 W has none) — e.g. Waveshare Ethernet HAT
2026-08-02 docs(readme): add 'Why this exists' — headless homelab mini PCs with no accessible serial
2026-08-05 feat: Telegram bot sidecar + repackage hub as the `picotty` uv package
    Two design docs from Dev-Docs/improvement-docs, implemented and tested.
    Telegram sidecar (telegram-bot/): a separate process that reaches the hub only
    via REST + /ws and bridges it to Telegram over outbound-only long polling. Three
    tiers — stats (/status /nodes /uptime), push alerts (node down/up, watchdog,
    failed, hub-restart, /mute), and a break-glass terminal (/shell + control keys,
    /reboot, /sysrq) gated behind chat-ID allowlist + TOTP arming with auto-disarm,
    idle close, and a local audit log. Depends on picotty[telegram], imports
    picotty.client.
    Packaging: hub/app/ -> hub/src/picotty/ as the `picotty` distributi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
    [code.py]
2026-08-05 feat(telegram): share one .env with the hub + add dashboard "Install sidecar"
    Path alignment: the sidecar now uses the SAME credentials file the dashboard
    writes — ~/.config/picotty/telegram.env (the hub's default TELEGRAM_ENV_PATH) —
    so Settings -> Telegram writes it and the sidecar reads + hot-reloads it, with no
    hub restart and no path juggling. install.sh/run.sh/install-service.sh and the
    unit standardize on that path (a legacy in-repo telegram-bot/.env is migrated,
    and still works as a fallback); the sidecar config defaults env_file there too.
    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
2026-08-05 docs(telegram): document the shared .env, the install button, and setup flow
    Bring the Telegram docs in line with the current behavior:
    - one shared credentials file (~/.config/picotty/telegram.env) that the dashboard
    writes and the sidecar reads + hot-reloads — no manual path alignment
    - the "Install / start sidecar" button (POST /api/telegram/install) and the
    service running/stopped status (GET /api/telegram service_active)
    - two setup paths (dashboard vs shell), and the "restart swarm-hub after a code
    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
2026-08-05 ci(release): publish to PyPI on GitHub Release + add v1.0.0 CHANGELOG
    - publish.yml: switch to GitHub's official "Upload Python Package" pattern —
    trigger on release published, build (uv, with vendored assets) -> upload
    artifact -> pypa/gh-action-pypi-publish via Trusted Publishing (environment
    `pypi`). Publishing a Release now ships the package and links it to the
    Releases section.
    - docs/packaging.md: document the release-driven flow + the pypi environment.
    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
2026-08-05 release: v1.0.1 — attach dists to the GitHub Release; bump version
    - publish.yml: attach the built wheel + sdist to the GitHub Release page
    (Python has no GitHub Packages registry; Release assets are the GitHub-side
    artifact). Adds contents:write to the build job + a gh release upload step.
    - bump picotty 1.0.0 -> 1.0.1 (pyproject + both uv.lock) to match the CHANGELOG,
    so the release publishes picotty 1.0.1.
    - docs/packaging.md: note the Release-asset attachment.
2026-08-11 fix(reconnect): stop nodes lingering falsely offline; harden DHCP + hub link
    A live, networked node could show offline in the dashboard indefinitely and
    only recover on a hub restart (no node restart). The liveness sweep flipped a
    stale node offline and dropped it from the registry WITHOUT closing the socket,
    so the still-open connection kept delivering the node's frames onto a detached
    state and the node never re-registered.
    - mark_offline() now closes the node's writer, so a swept/half-open connection
    is torn down and the node is forced to reconnect (the core fix).
    - TCP keepalive on accepted node sockets (kernel backstop for a vanished peer).
    - node_pinger task: hub->node keepaliv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
    [code.py, netlink.py, nodeconfig.py]
2026-08-11 feat(telemetry): per-node link quality (rtt/jitter/loss) + uptime & reconnect tracking
    Precautionary monitoring so a degrading node is visible before it drops.
    - ping_node folds every probe (delivered or lost) into a rolling RTT window per
    node; utils.net_stats derives avg/min/max, jitter (mean consecutive-sample
    variation), and loss %. Broadcast live as a node_net event; exposed on the
    node API.
    - heartbeat now carries the node's firmware uptime; a backwards jump raises a
    node_down "node rebooted" event (unannounced reboot / watchdog).
    - registry counts reconnects per node id for this hub run, so a flapping link is
    visible even while the node reads online.
    Node firmware:
    -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
    [code.py, messages.py]
2026-08-11 docs(changelog): frame the reliability pass; ignore local PR draft files
    Add a lead summary to the Unreleased section and gitignore PR-*.md so a local
    PR body draft can live beside the branch without being committed.
2026-08-12 release: v1.0.3 — reliability pass + link telemetry; sidecar /telemetry (1.1.0)
    Hub bumped to 1.0.3 (patch): the node-presence reliability pass and the
    per-node link telemetry (rtt/jitter/loss, uptime, reconnects).
    Telegram sidecar bumped to 1.1.0 (minor): new /telemetry command surfacing
    the link telemetry over chat — a fleet roster bare, per-node detail with a
    node arg. Its picotty floor is raised to >=1.0.3 (the fields it reads).
2026-08-12 feat(ops): add update.sh — one-shot source-tree update + service restart
2026-08-22 feat: dual-hub failover + expanded Telegram control
    Nodes can now hold a primary + backup hub with automatic failover and
    runtime source-selection; the Telegram bot gains read-only ops and fleet
    automation commands.
    - firmware: HubSelector (primary/backup, sticky failback, runtime steering
    via new welcome + hub_directive frames); FW 1.3.0; pure-logic,
    host-testable hubselect.py
    - hub: HUB_ID + welcome frame, POST /nodes/{id}/hub directive endpoint,
    node hub_label surfaced in the API and dashboard; picotty 1.1.0
    - client SDK: node_output, output_search, ping, bulk_cmd, macros/run_macro,
    runbooks/run_runbook, hub_directive
    - telegram: /events /log /search /ping /bulk /macros /runmacro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
    [code.py, hubselect.py]
2026-08-22 feat: cross-hub takeover, sidecar dual-hub failover, responsive dashboard
    Round out dual-hub so either hub can drive any board, the phone control plane
    survives a hub outage, and the dashboard works on any screen. No version bump —
    these complete the unreleased v1.1.0.
    - hub: HUB_PEERS peer awareness — a peer_poller surfaces boards held by the other
    hub as "active on <peer>", and a steer directive to a board this hub doesn't
    hold RELAYS to the peer that does (loop-safe), so on-demand takeover works from
    either hub. New merge_peer_only + POST /nodes/{id}/hub relay header.
    - telegram: FailoverHub — the bot talks to a primary hub and fails over to
    HUB_BASE_URL_BACKUP (REST + even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
2026-08-22 fix(ui): stack the node header so the action buttons stop crushing the info
    On desktop the node-info column (flex:1 1 auto; min-width:0) collapsed under the
    fixed-width row of 10 action buttons, wrapping the node id and truncating the caps
    line with a large empty gap. Lay the header out as a vertical stack instead — node
    info full-width on top, the action toolbar wrapping on its own row below — so it is
    predictable at every width and aspect ratio. Also cap the responsive rail clamps at
    their original widths so wide screens don't steal space from the console.
2026-09-06 fix: route Magic SysRq chords to the /sysrq command (unknown keycode: 'SYSRQ')
    The Alt+SysRq+B quick-chord (and any custom chord naming SysRq) was dispatched as
    a plain HID /keys chord, which the node injector rejects — SysRq is the PrintScreen
    keycode and must be HELD while the command key is tapped, not pressed all at once.
    The dashboard now detects a SysRq chord and routes it to the dedicated /sysrq
    command (correct hold-and-tap timing). Also fix HubClient.sysrq() sending the key
    under `command` instead of `key`, so a Telegram /sysrq <node> <key> no longer
    silently defaulted to b (reboot).
2026-09-06 feat(telegram): button-driven menu UI with per-chat context memory
    The bot was all typed commands, which is clumsy on a phone. Add an inline-keyboard
    menu system: /menu (and /start) opens a home screen and everything drills down by
    tapping — Nodes -> node detail (Ping/Read/Telemetry/Log/Mute, and when armed
    Shell/Reboot[confirm]/SysRq[key picker]/Move-hub), Fleet (Macros/Runbooks with an
    all-online/this-node target picker), Source-hub switch, and Arm (tap then send the
    TOTP code). A per-chat context remembers the selected node and pending prompt so
    buttons act without re-typing, and the home screen shows live hub/online/armed
    state. All existing typed commands still work.
    New app/menus.py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
2026-09-06 feat: OTA firmware-only/settings-only + faster resilient pushes; takeover button; v1.2.0
    OTA: a push now takes a scope — all | firmware (everything except settings.toml,
    keep the node's config) | settings (only settings.toml, keep the code) — filtered
    hub-side so existing 1.3.0 nodes need no change; a settings-only push is how you
    retune a board's failover/timing knobs without reflashing. Chunk size 512->4096 B
    (~8x fewer round-trips), and a transient mid-transfer drop retries the whole
    transfer (safe: ota_begin re-wipes staging, commit stays one-shot + verified).
    Exposed on POST /nodes/{id}/ota and /bulk/ota (scope) and the dashboard's
    Update-firmware sheet (Everything / Firmware only /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
2026-09-06 docs(changelog): restore the v1.1.0 entry, split 1.2.0 to post-1.1.0 work only
    v1.1.0 was already released (tag v1.1.0 at the header-fix commit) with dual-hub
    failover, the Telegram command surface, cross-hub takeover/peer visibility, the
    sidecar dual-hub, and the responsive dashboard. The 1.2.0 bump had accidentally
    RENAMED that heading, erasing 1.1.0 from the changelog. Restore a proper v1.1.0
    section and trim v1.2.0 to only the work that landed after the tag — OTA
    firmware/settings scope + speed, the Telegram button UI, the clearer take-over /
    switch-hub controls, and the Magic SysRq fix. Each version keeps its own Verified
    counts. (1.2.0 is correct per semver: 1.1.0 shipped, and these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
2026-10-02 docs: add GitHub Pages explainer site + deploy workflow
    Add a standalone explainer/landing page under site/ and a GitHub Pages
    workflow that deploys it to https://morpheuslord.github.io/PICOTTY/ via
    GitHub Actions. Point the picotty Homepage and Documentation project URLs
    at the published site.
    - site/index.html: self-contained landing page (teletype/phosphor themes,
    topology diagram, feature grid, PyPI section, quick start, docs map)
    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
